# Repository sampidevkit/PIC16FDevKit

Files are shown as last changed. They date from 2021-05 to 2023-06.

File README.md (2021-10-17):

# PIC16F1887X MICROCONTROLLER DEVELOPMENT KIT
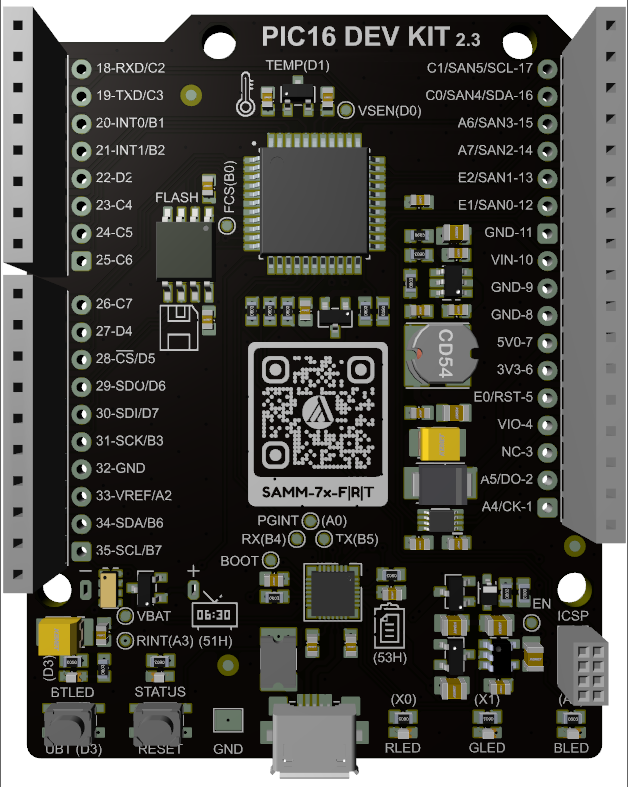
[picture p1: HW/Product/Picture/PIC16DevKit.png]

<br/>Đây là thiết kế mở - một kit phát triển vi điều khiển 8-bit họ PIC16F18875/6/7. Kit được trang bị các tính năng như sau:<br/>
* PCB và các ngõ vào ra theo định dạng của Arduino Uno.
* Mạch nạp tích hợp theo kiểu USB lưu trữ, tệp hex sẽ được kéo - thả để nạp trực tiếp mà không cần sử dụng phần mềm nạp cũng như các mạch nạp bên ngoài như PICKit, ICD, ..., tuy nhiên người dùng vẫn có thể sử dụng được các mạch nạp chuyên dụng kết nối với cổng ICSP được thiết kế sẵn.
* Cổng chuyển đổi USB - UART, người dùng không cần sử dụng thêm thiết bị chuyển đổi bên ngoài như CP2102, FT232, ...
* 4kByte SRAM dùng để mở rộng bộ nhớ tạm cho MCU chính. Chức năng này được thực hiện bởi chip nạp thông qua giao tiếp I2C.
* 2 ngõ ra mở rộng để điều khiển LED được trang bị sẵn trên board. Chức năng này cũng được thực hiện bởi chip nạp thông qua giao tiếp I2C.
* Bộ nhớ Flash 4Mbit, lưu dữ liệu, cấu hình của ứng dụng người dùng. Giao tiếp SPI với MCU chính.
* Cảm biến nhiệt độ dạng tín hiệu tương tự.
* Chip đồng hồ thời gian thực độ chính xác cao. Giao tiếp I2C với MCU chính.<br/>
## 1. Sơ Đồ Khối
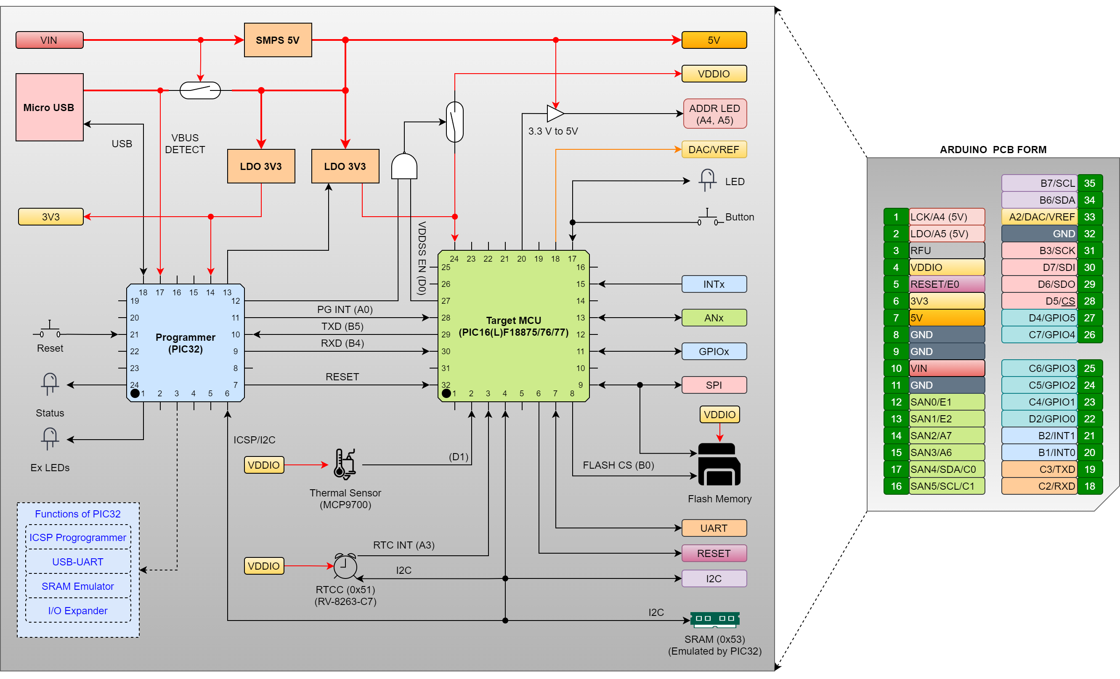
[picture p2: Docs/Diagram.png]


## 2. Sơ Đồ Nguyên Lý
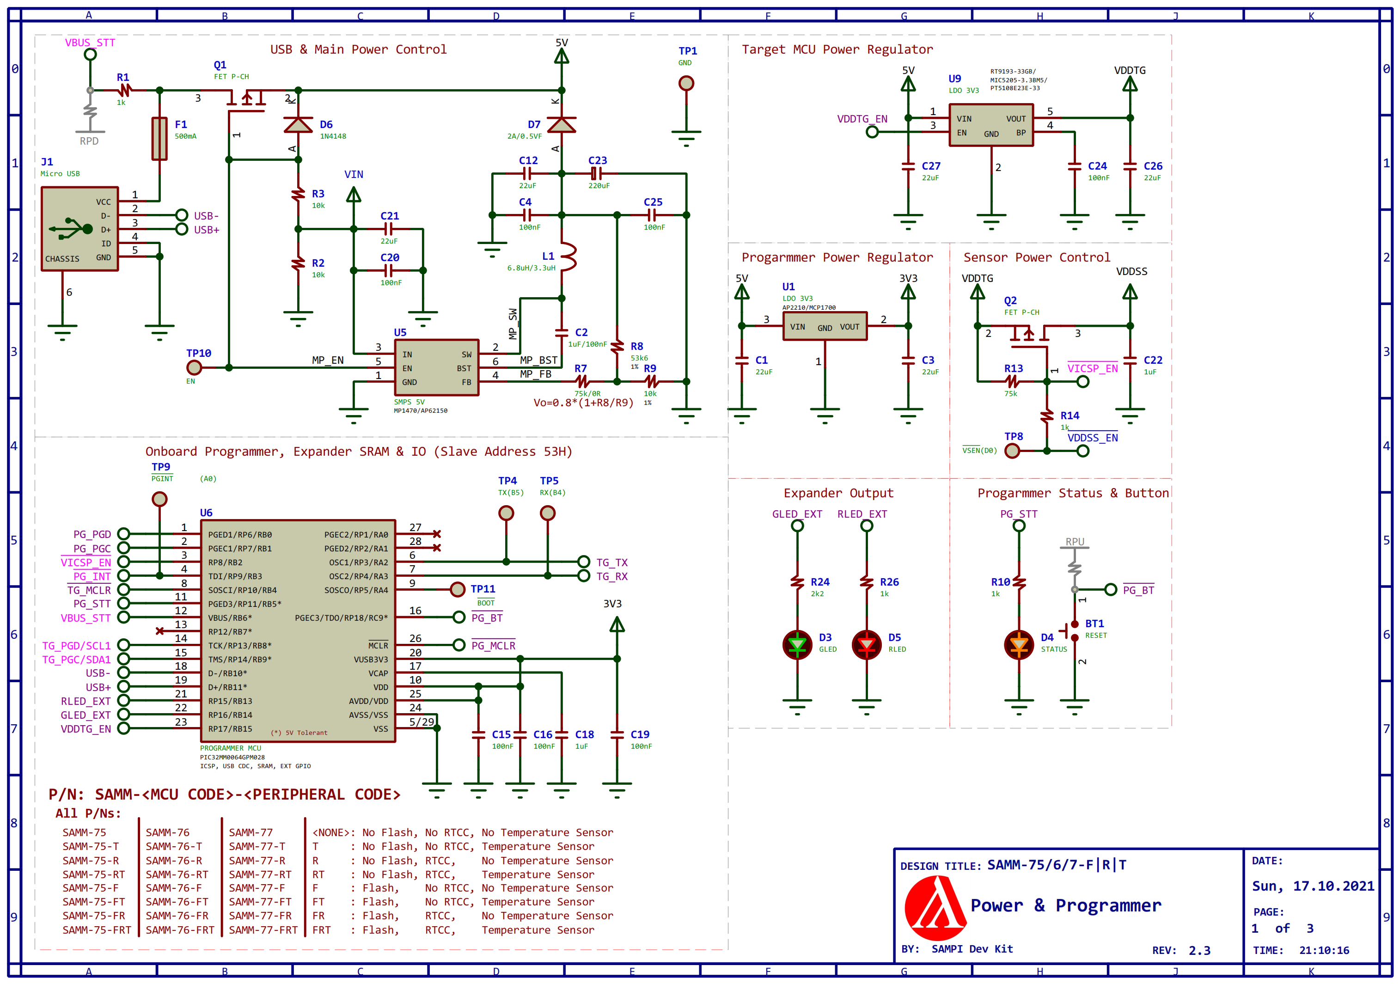
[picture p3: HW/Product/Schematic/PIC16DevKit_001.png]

<br/>
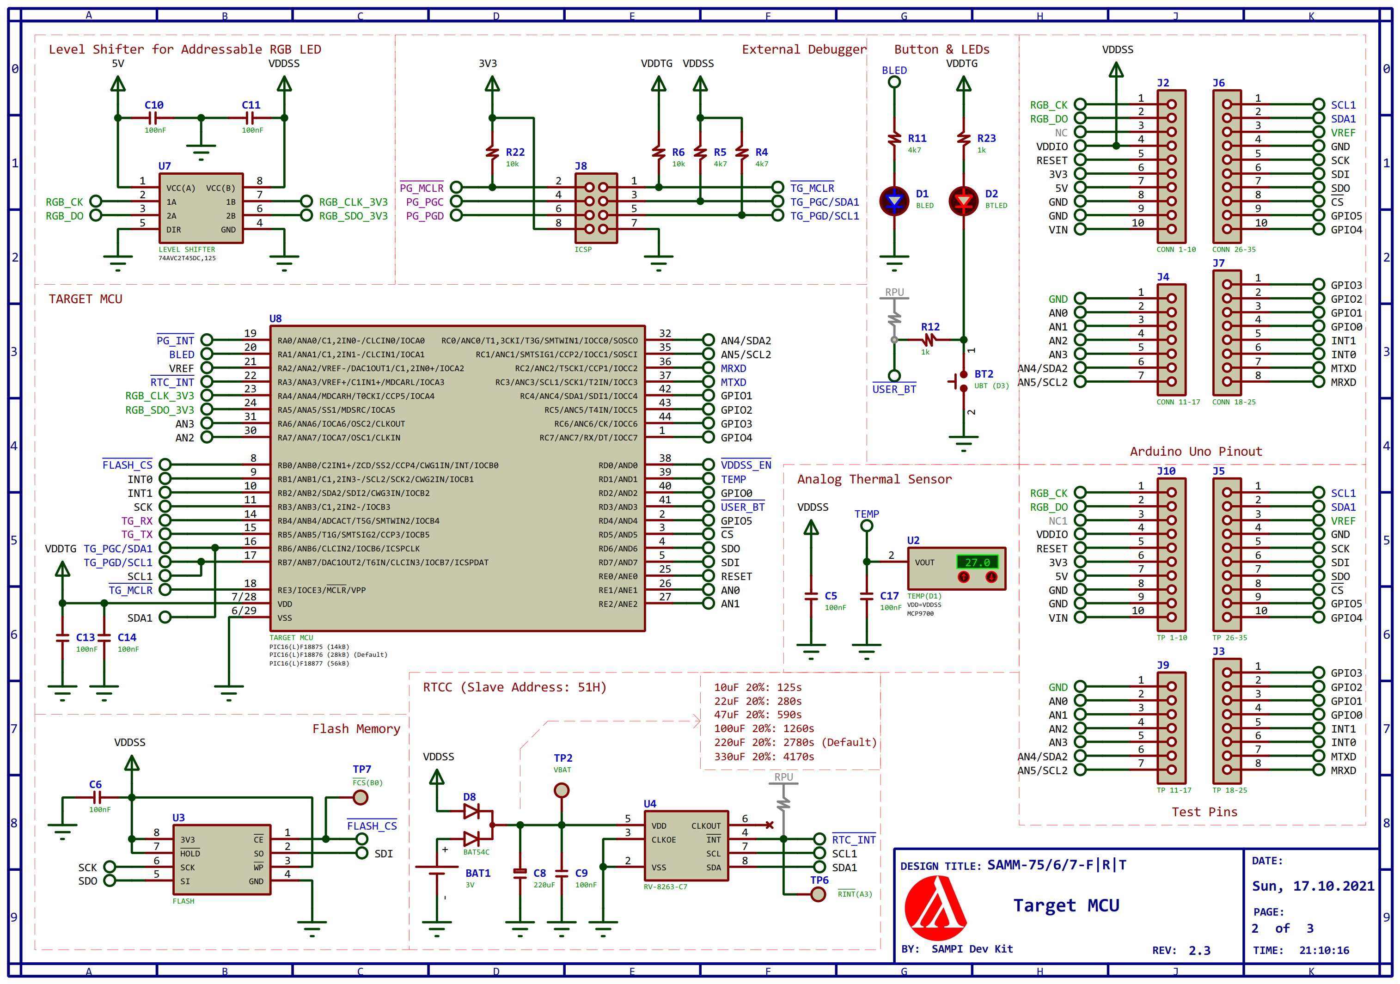
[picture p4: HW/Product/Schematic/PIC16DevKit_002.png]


## 3. Vi Điều Khiển Chính PIC16F1887x
Họ vi điều khiển PIC16F1887x là họ vi điều khiển 8-bit thế hệ mới của PIC16F887/PIC16F877A. Tương thích hoàn toàn về mặt I/O và các chức năng cơ bản. Bên cạnh đó, chip được trang bị các tính năng mới hơn như:<br/>
* Dao động nội lên đến 32MHz và tốc độ đạt 8MIPS so với 5MIPS của chip cũ.
* Bộ nhớ chương trình từ 7kByte đến 56kByte, RAM 512byte-4096byte, EEPROM nội lên đến 256byte.
* Chip được trang bị 1x UART, 2x SPI/I2C, 5x Capture/Compare/PWM (CCP), 2x PWM 10bit, 3x timer 8bit, 4x timer 16bit.
* ADC 10 bit sử dụng được cho tất cả các I/O, 1x DAC 5bit.
* Tính năng mới: 4x cổng logic khả trình (CLC), tính năng bắt điểm 0 của tín hiệu AC (ZCD), CRC, NCO, CWG, DSM, ...
* Ngõ vào ra của các module chức năng có thể cấu hình trên bất kì I/O nào nhờ chức năng Peripheral Pin Select (PPS).
* Năng lượng thấp, phù hợp cho các ứng dụng sử dụng pin.<br/>
* [Thông tin thêm xem tại đây](https://www.microchip.com/wwwproducts/ProductCompare/PIC16F877A/PIC16F18877).

## 4. Môi Trường Lập Trình, Trình Biên Dịch và Công Cụ Hỗ Trợ

### 4.1. Môi Trường Lập Trình MPLAB X IDE

Môi trường lập trình MPLAB X IDE sử dụng mã nguồn của Netbeans, giao diện thân thiện và dễ sử dụng. Tải về và hướng dẫn cài đặt tại đây: [Installing MPLAB® X IDE](https://microchipdeveloper.com/mplabx:installation). </br>
Khuyến cáo: Sử dụng Windows 64bit với RAM tối thiểu 4GB và ổ cứng trống từ 20GB.

### 4.2. Trình Biên Dịch MPLAB XC8
Nếu sử dụng ngôn ngữ lập trình C để lập trình cho Kit, bạn cần tải về trình biên dịch XC8. Nó sẽ chuyển mã C thành mã assembly. </br>

</br>Sau đó, nó sẽ chuyển mã assembly sang mã máy dưới dạng file HEX. Bạn cũng có thể sử dụng XC8 để biên dịch cho mã nguồn được viết trực tiếp bằng assembly. 

</br>Trình biên dịch có thể sử dụng miễn phí, không giới hạn code size, chỉ giới hạn các cấp độ tối ưu mã nguồn. Chức năng tối ưu mã nguồn sử dụng trong sản xuất, không cần thiết trong học tập. Tải về và hướng dẫn cài đặt tại đây: [Installing MPLAB® XC8 Compiler](https://microchipdeveloper.com/xc8:installation).

### 4.3. Công Cụ Cấu Hình và Tạo Code Mẫu MPLAB Code Configurator (MCC)
MCC là một plugin của MPLAB X IDE, hỗ trợ tạo cấu hình chip, cấu hình các ngoại vi và các API để người dùng sử dụng mà không mất nhiều thời gian xây dựng chúng. </br>

</br>Tải về và hướng dẫn cài đặt tại đây: [Install MPLAB® Code Configurator (MCC)](https://microchipdeveloper.com/install:mcc).

## 5. Mạch Nạp Tích Hợp

### 5.1. Nạp Chương Trình Mạch Nạp
Chương trình mạch nạp chỉ cần nạp 1 lần. Các công cụ cần chuẩn bị: </br>
* Mạch nạp chuyên dụng như PICkit3, PICkit4, Snap, ICD3, ICD4, ...
* Header đực 2x4x1.27 dùng cho cổng nạp ICSP theo sơ đồ sau: </br>
Pin2-MCLR, Pin4-PGC, Pin6-PGD, Pin8-VDD (3V3), Pin7-GND </br>
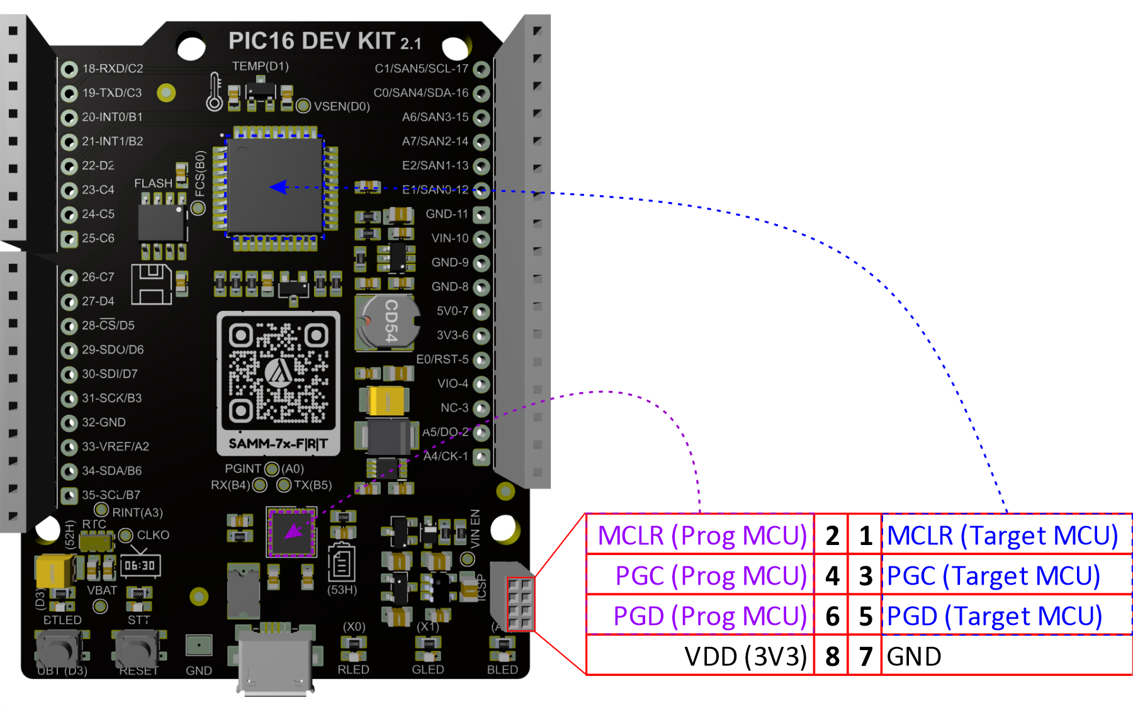
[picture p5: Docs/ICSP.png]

* Cáp micro USB: Kết nối Kit với nguồn USB 5V bất kỳ. Nếu sử dụng nguồn điện 3.3V cấp từ mạch nạp thì không cần sử dụng cáp micro USB.
* File chương trình tải về từ [master/FW/PG.X/Production.hex](https://github.com/sampidevkit/PIC16FDevKit/raw/master/FW/PG.X/Production.hex).
* MCU là PIC32MM0064GPM028.
Khi nạp thành công, kết nối kit với máy tính bằng cáp micro USB bạn sẽ thấy xuất hiện ổ đĩa như sau: </br>
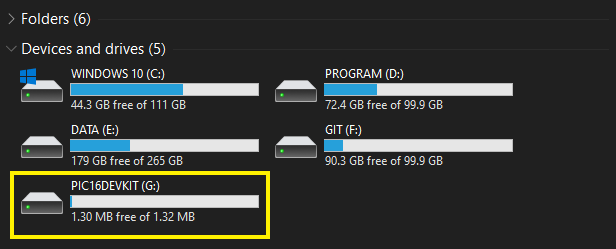
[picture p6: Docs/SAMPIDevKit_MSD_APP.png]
 </br>
Mở ổ đĩa này, bạn sẽ thấy file SAMPIDevKit_INFO.txt chứa nội dung như sau: </br>
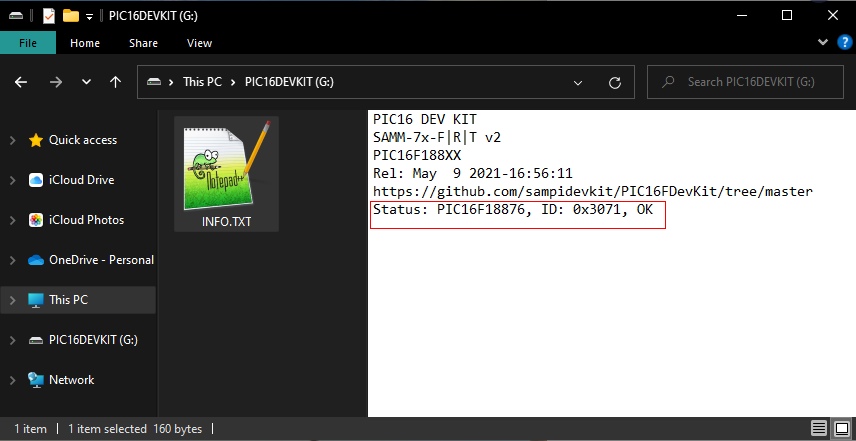
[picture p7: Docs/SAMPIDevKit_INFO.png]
 </br>
Nếu có lỗi xảy ra, xem ở mục 5.3.

### 5.2. Cập Nhật Chương Trình Mạch Nạp
Để cập nhật chương trình mới cho chip nạp, bạn có thể thực hiện như mục 5.1 hoặc thực hiện như sau: </br>
* Kết nối kit với máy tính bằng cáp micro USB.
* Nhấn giữ nút RESET đến khi các đèn STT, RLED, BLED cùng sáng (khoảng 5s).
* Vào My Computer/ This PC sẽ thấy xuất hiện ổ đĩa BOOTLOADER.
* Tải File chương trình về từ [master/FW/PG.X/app.hex](https://raw.githubusercontent.com/sampidevkit/PIC16FDevKit/master/FW/PG.X/app.hex) và lưu vào ổ đĩa BOOTLOADER. </br>
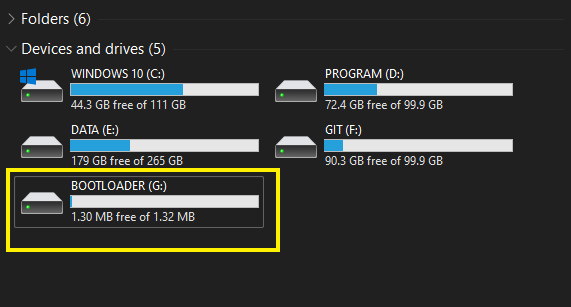
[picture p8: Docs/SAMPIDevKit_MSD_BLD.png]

* Sau khi lưu, kit sẽ tự khởi động lại và hoạt động với chương trình mới. Nếu có lỗi xảy ra, xem ở mục 5.3.

### 5.3 Các Trạng Thái LED Lỗi
* Lỗi khi ghi file hex vào ổ đĩa của kit: File nạp không đúng định dạng hoặc sự cố kết nối USB.
* Chế độ bootloader - nhấn giữ nút RESET trong 3s: RLED, GLED sáng, STT led ON=500ms, OFF=500ms. </br>
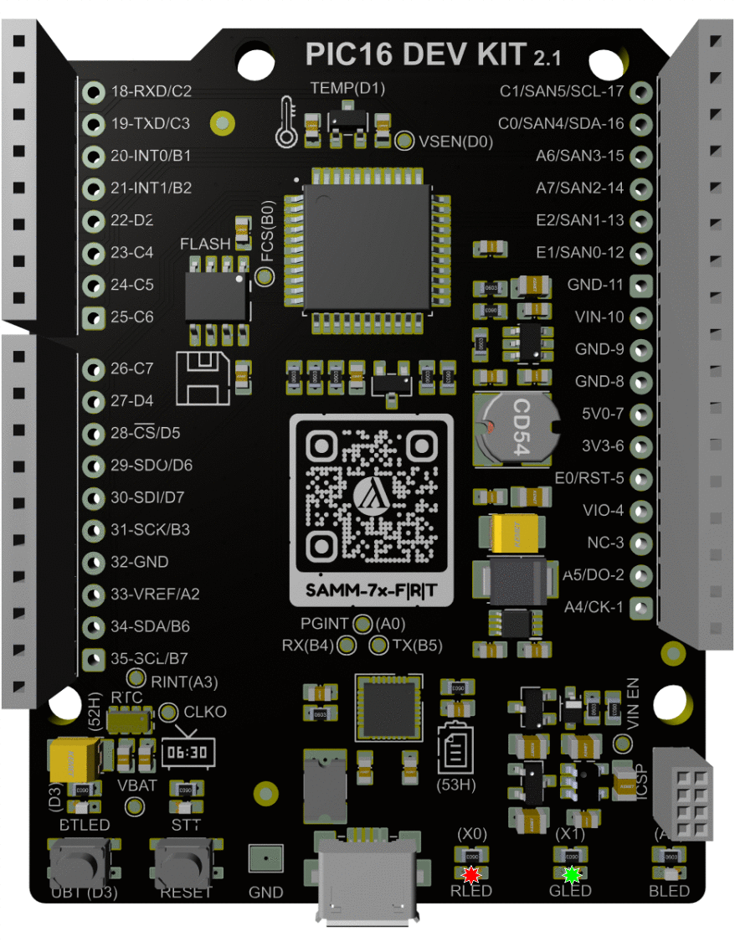
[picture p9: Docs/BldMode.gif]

* Chế độ chờ: Led STT nháy với chu kì ON=10ms, OFF=1990ms. </br>
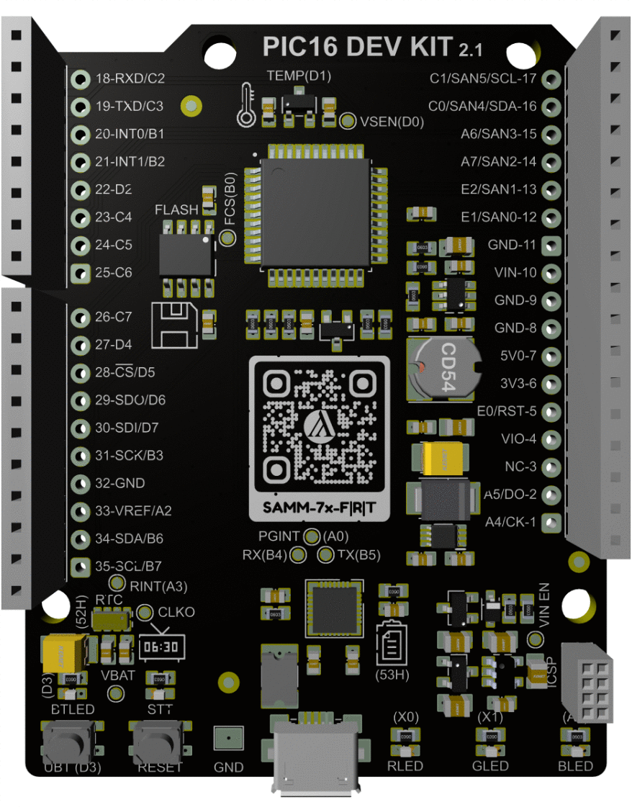
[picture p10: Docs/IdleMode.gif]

* Lỗi không nhận chip: Led STT nháy với chu kì ON=500ms, OFF=1500ms. </br>

* Truyền nhận dữ liệu UART: Led STT nháy 1 lần TON=5ms. </br>

* Reset target chip - khi nhấn giữ nút RESET khoảng 200ms: Led STT, RLED, GLED sáng 500ms. </br>
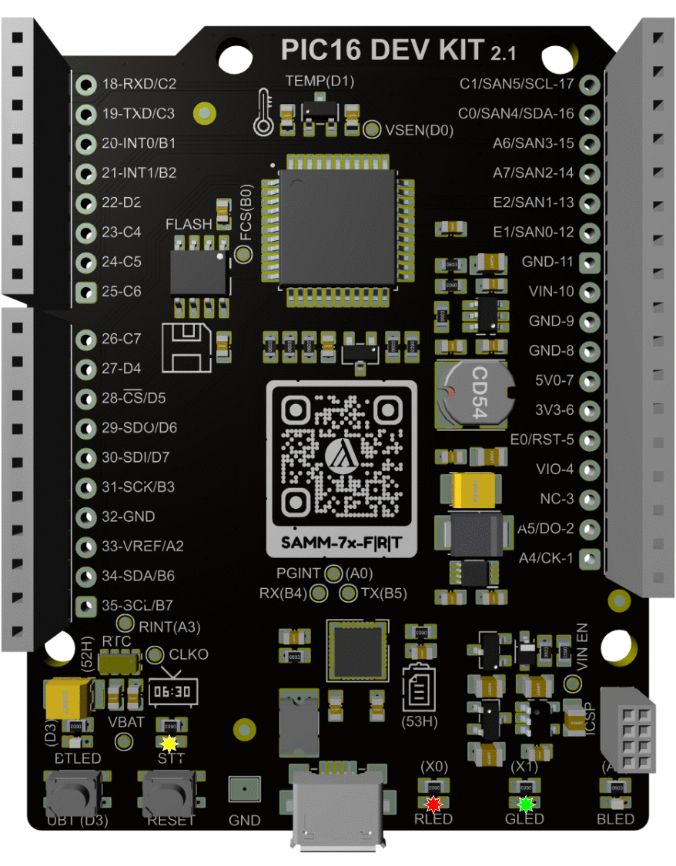
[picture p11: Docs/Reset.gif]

* Erase target chip - khi nhấn nhanh 4 lần nút RESET: Led STT sáng, RLED và GLED nháy 3 lần 250ms sau đó cả 3 cùng sáng trong 500ms. </br>


## 6. Hướng Dẫn Lập Trình Cơ Bản
[Xem tại đây](https://github.com/sampidevkit/PIC16FDevKit/blob/docs/README.md).

## 7. Tài Liệu Kỹ Thuật:
* [Target MCU PIC16LF18877](https://ww1.microchip.com/downloads/en/DeviceDoc/PIC16LF1885777_Data_Sheet_40001825F.pdf).
* [PIC16LF18877 Programming Specification](https://ww1.microchip.com/downloads/en/DeviceDoc/40001753B.pdf).
* [Programmer MCU PIC32MM0064GPM028](https://ww1.microchip.com/downloads/en/DeviceDoc/PIC32MM0256GPM064-Family-Data-Sheet-DS60001387D.pdf).
* [PIC32MM0064GPM028 Programming Specification](https://ww1.microchip.com/downloads/en/DeviceDoc/PIC32MM-Families-Flash-Programming-Specification-DS60001364E.pdf).
* [Flash memory SST25VF020B](https://ww1.microchip.com/downloads/en/DeviceDoc/20005054D.pdf).
* [Temperature sensor MCP9700](https://ww1.microchip.com/downloads/en/DeviceDoc/20001942G.pdf).
* [Real time clock and calendar RV8263-C7](https://www.microcrystal.com/fileadmin/Media/Products/RTC/Datasheet/RV-8263-C7.pdf).
* [Voltage level shifter 74LVC2T45GS-Q100X](https://assets.nexperia.com/documents/data-sheet/74LVC_LVCH2T45_Q100.pdf).
* [LDO 3.3V RT9193](https://www.richtek.com/assets/product_file/RT9193/DS9193-17.pdf).
* [LDO 3.3V MIC5205](https://www.microchip.com/content/dam/mchp/documents/OTH/ProductDocuments/DataSheets/20005785A.pdf).
* [LDO 3.3V PT5108E23E](http://www.sunnyqi.com/upLoad/product/month_1306/PT5108.pdf).
* [LDO 3.3V AP2210](https://www.diodes.com/assets/Datasheets/AP2210.pdf).
* [LDO 3.3V MCP1700](https://ww1.microchip.com/downloads/en/DeviceDoc/MCP1700-Data-Sheet-20001826F.pdf).
* [SMPS 5V MP1470](https://www.monolithicpower.com/en/documentview/productdocument/index/version/2/document_type/Datasheet/lang/en/sku/MP1470/document_id/327/).
* [SMPS 5V AP62150](https://www.diodes.com/assets/Datasheets/AP62150.pdf).
* [Button PTS 815](https://www.ckswitches.com/media/2728/pts815.pdf).
* [Inductor 3.3uH/6.8uH CD53 Series](http://www.coilsjs.com/product/product_images/b/cn_D_1_108.pdf).
* [Switching diode 1N4148W-E3-18](https://www.vishay.com/docs/85748/1n4148w.pdf).
* [Switching diode BAT54C](https://assets.nexperia.com/documents/data-sheet/BAT54_SER.pdf).
* [Schottky Power Rectifier SS24](https://www.onsemi.com/pdf/datasheet/ss24-d.pdf).
* [Resettable fuse 0ZCG0050AF2C](https://www.belfuse.com/resources/datasheets/circuitprotection/ds-cp-0zcg-series.pdf).
* [Micro USB connector 10118192-0002LF](https://www.amphenol-icc.com/media/wysiwyg/files/drawing/10118192.pdf).
* [Mosfet P-CH 2A FDN340P](https://www.onsemi.com/pdf/datasheet/fdn340p-d.pdf).
* [Battery CR1220](https://www.digikey.com/en/products/detail/panasonic-bsg/CR-1220-HFN/965114).
* [Female header 2x4x1.27mm SFMC-104-T1-S-D](http://suddendocs.samtec.com/prints/sfm-thd.pdf).
* [Female header 2x2x2.54mm M20-8760242](https://cdn.harwin.com/pdfs/M20-876.pdf).
* [Female header 1x10/8/7x2.54mm SSW-1XX-01-T-S](http://suddendocs.samtec.com/catalog_english/ssq_th.pdf).
* [Male header 1x10/8/7x2.54mm TSW-1XX-23-L-S](http://suddendocs.samtec.com/catalog_english/tsw_th.pdf).
* [Arduino Uno Dimension](http://arduino.cc/documents/ArduinoUno.dxf).
* [Arduino Uno Pinout](https://content.arduino.cc/assets/Pinout-UNOrev3_latest.png).

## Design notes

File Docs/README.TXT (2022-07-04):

PIC16(L)F1885X/7X microcontrollers feature Analog, Core Independent Peripherals and communication peripherals, combined with eXtreme Low Power (XLP) for a wide range of general purpose and low-power applications. The family features the CRC/SCAN, HLT and Windowed WDT to support customers looking to add safety to their application. Additionally, this family includes up to 56 KB of Flash memory, along with a 10-bit ADC with Computation (ADC2) for automated signal analysis to reduce the complexity of the application.
Enhanced Mid-range Core with 49 Instruction, 16 Stack Levels
Adjustable Internal Oscillator (up to 32MHz)
2x 10-bit PWMs
5x Capture, Compare, PWM (CCP)
Numerically Controlled Oscillator (NCO)
4x Configurable Logic Controller (CLC)
10-bit ADC with Computation (ADC2)
Complementary Waveform Generator (CWG)
5-bit Digital to Analog Converter (DAC)
Data Signal Modulator (DSM)
In Circuit Serial Programming (ICSP)
Zero Cross Detect (ZCD)
Cyclical Redundancy Check (CRC/SCAN)
Windowed Watchdog Timer (WWDT)
Peripheral Pin Select (PPS)
Enhanced Power-On/Off-Reset
Low-Power Brown-Out Reset (LPBOR)
Programmable Brown-Out Reset (BOR)
PIC16LF18877 (1.8V – 3.6V)
PIC16F18877 (2.3V – 5.5V)

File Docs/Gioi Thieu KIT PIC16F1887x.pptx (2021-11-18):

## PIC16F18877 DEVELOPMENT KIT

INTRODUCTION & DEMONSTRATION

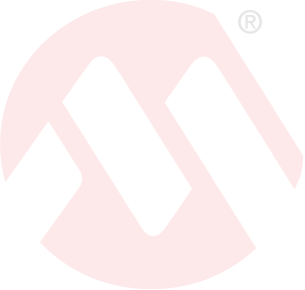
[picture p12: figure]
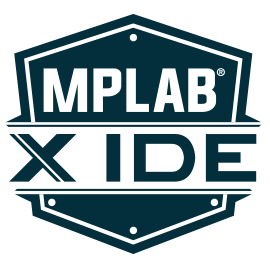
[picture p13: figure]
MPLAB X IDE Logo
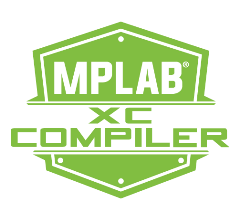
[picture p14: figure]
mplab_xc_compiler_logo_011216_03

## CONTENTS

MICROCHIP COMPANY INTRODUCTION
PIC16F18877 OVERVIEW
TRAINING PROGRAM
DEMONSTRATION

## MICROCHIP COMPANY INTRODUCTION

- Leading in microcontroller
PIC, dsPIC, AVR, MIPS, ARM.
- Acquisitions
- Atmel: MCU, MPU, Touch, RF.
- Micrel: Power supply & management.
- ISSC: Memory.
- Supertex: HV analog and mixed signal.
- EqcoLogic: Data and video transceivers.
- Microsemi: FPGA & SoC (March 1st, 2018).
- Number one in 8-bit MCU

MICROCHIP COMPANY INTRODUCTION

PIC16F1xxxx OVERVIEW

TRAINING PROGRAM

DEMONSTRATION

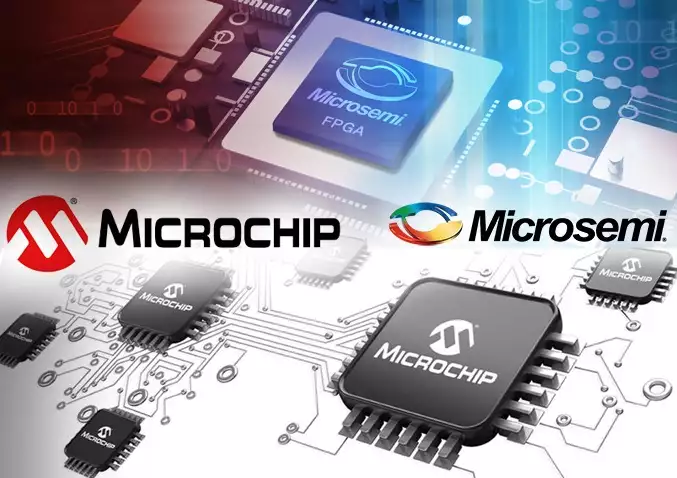
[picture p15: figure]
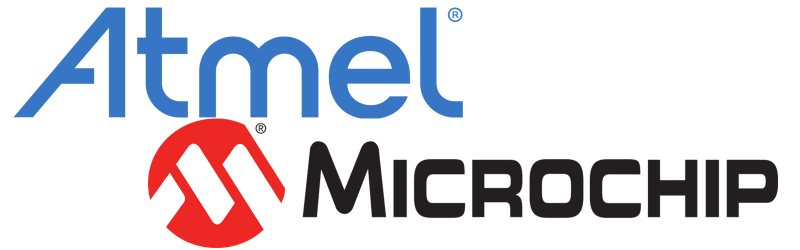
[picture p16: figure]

## PIC16F1xxxx OVERVIEW

- Summary
- PIC16F1xxxx MCU offer eXtreme Low-Power.
- LCD drive, RTCC, 12-bit ADC.
- Core Independent Peripherals.
- Memory access partition.

MICROCHIP COMPANY INTRODUCTION

PIC16F1xxxx OVERVIEW

TRAINING PROGRAM

DEMONSTRATION

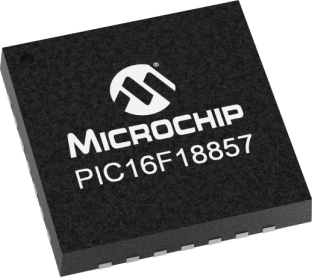
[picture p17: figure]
product primary image

## PIC16F1xxxx OVERVIEW

- Feature

MICROCHIP COMPANY INTRODUCTION

PIC16F1xxxx OVERVIEW

TRAINING PROGRAM

DEMONSTRATION

Parameters | PIC16F18857 | PIC16F886
Flash/RAM/EEPROM | Up to 56KB/4KB/256B | Up to 14KB/368B/256B
Speed | 8MIPS@32MHz (Internal) | 5MIPS&20MHz (External)
ADC/DAC resolution | 12-bit/5-bit | 10-bit/0
Timer 8/16bit | 2/2 | 2/1
CCP/PWM | 2/2 – 10-bit | 2/0 - 10-bit
CWG/CLC | 1/4 | 0/0
Zero cross detect | Yes | No
UART/SPI/I2C | 2/1/1 | 1/1/1
Peripheral pin select | Yes | No

## TRAINING PROGRAM

- What is a microcontroller?
- How to use a microcontroller?
- How to make an application?

MICROCHIP COMPANY INTRODUCTION

PIC16F1xxxx OVERVIEW

TRAINING PROGRAM

DEMONSTRATION

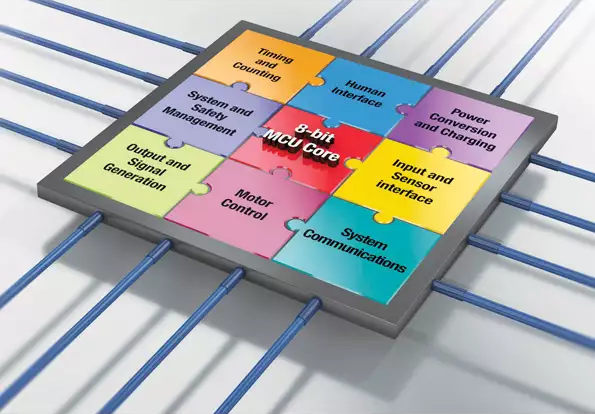
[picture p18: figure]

## TRAINING PROGRAM

- What is a microcontroller?
- MCU Basic Structure/Operation.
- Peripheral Circuitry.
- Programming Language/
Software Development Environment.
- Peripheral Circuitry Control.
- Interrupt Processing.

MICROCHIP COMPANY INTRODUCTION

PIC16F1xxxx OVERVIEW

TRAINING PROGRAM

DEMONSTRATION

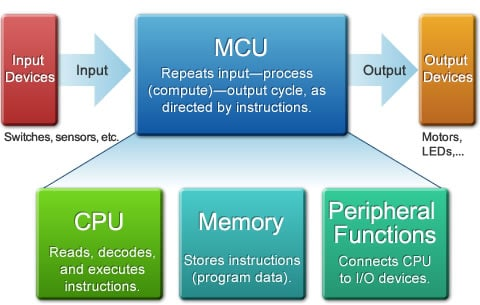
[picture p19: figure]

## TRAINING PROGRAM

- How to use a microcontroller?
- How to configure?
- How to manage memory?
- How to control I.Os & peripherals?
- MPLAB X IDE & XC8 compiler.

MICROCHIP COMPANY INTRODUCTION

PIC16F1xxxx OVERVIEW

TRAINING PROGRAM

DEMONSTRATION

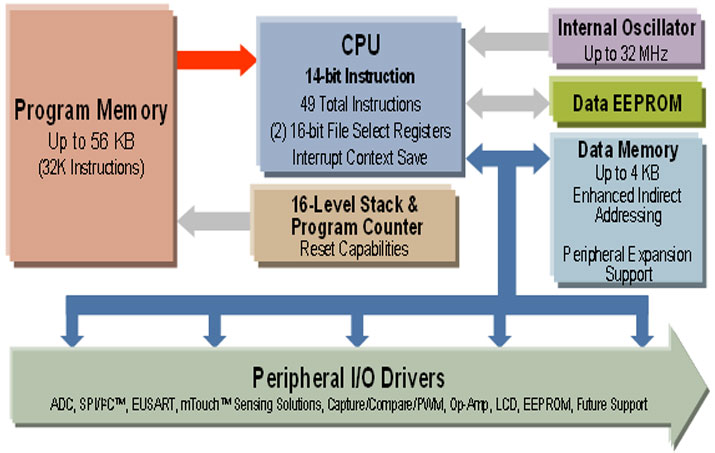
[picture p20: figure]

## TRAINING PROGRAM

MPLAB X IDE & XC8 compiler:
- Run on a PC (Windows®, Mac OS®, Linux®).
- Work on low level: ASM, register (in C).
- Work on high level: API using framework.
- Free license for student.

MICROCHIP COMPANY INTRODUCTION

PIC16F1xxxx OVERVIEW

TRAINING PROGRAM

DEMONSTRATION

## TRAINING PROGRAM

- How to make an application?

MICROCHIP COMPANY INTRODUCTION

PIC16F1xxxx OVERVIEW

TRAINING PROGRAM

DEMONSTRATION

Collect demands
Analyze
Design
Test
Adjust
Release

## TRAINING PROGRAM

- Duration
2 Shifts x 4 Weeks (18 hours).
- Main content
- Configure Chip.
- Memory partition & accessing.
- GPIO control.
- Peripherals: Timer, ADC, PWM, UART, I²C, SPI, Interrupt.
- Applications: Real time control.

MICROCHIP COMPANY INTRODUCTION

PIC16F1xxxx OVERVIEW

TRAINING PROGRAM

DEMONSTRATION

## DEMONSTRATION

- Overview
- Arduino size and pinout.
- Compatible with Arduino shields.
- Feature
- Programmer & Debugger onboard.
- External power supply up to 1.5A.
- More connectivity.

MICROCHIP COMPANY INTRODUCTION

PIC16F1xxxx OVERVIEW

TRAINING PROGRAM

DEMONSTRATION

## DEMONSTRATION

- Electrical
- 5V from micro USB or external power up to 1.5A.
- Logic 5V/3.3V.
- Demo application
MCU will connect to server and send values of sensor included:
  - Temperature & Humidity.
  - Proximity and Ambient.
  - Accelerometer.
  - GPS & RTCC.
Server will send command to control LEDs on MCU board.

MICROCHIP COMPANY INTRODUCTION

PIC16F1xxxx OVERVIEW

TRAINING PROGRAM

DEMONSTRATION

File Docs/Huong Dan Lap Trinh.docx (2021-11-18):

TÀI LIỆU HƯỚNG DẪN LẬP TRÌNH

VI ĐIỀU KHIỂN PIC 8-BIT

HỌ PIC16F18877

Chương 1. TỔNG QUAN VỀ VI ĐIỀU KHIỂN PIC16F18877
  1.1. Các thông số kỹ thuật vi điều khiển PIC16F18877

Vi điều khiển PIC16(L)F1885x/7x với thiết kế analog cải tiến, ngoại vi hoạt động độc lập với CPU (Core Independent Peripherals) và các chuẩn giao tiếp được kết hợp với công nghệ năng lượng siêu thấp (eXtreme Low Power – XLP). Bên cạnh đó, họ PIC16(L)F188xx còn có thêm các tính năng như CRC/SCAN, HLT và Windowed WDT nhằm tăng cường tính an toàn cho ứng dụng. Thêm vào đó, với bộ nhớ flash lên đến 56KB, 4KB RAM cùng với 10-bit ADC với khả năng tính toán tự động sẽ làm giảm sự phức tạp của ứng dụng.

Các tính năng mở rộng:

- Enhanced Mid-range Core with 49 Instruction, 16 Stack Levels.
- Adjustable Internal Oscillator (1-32MHz).
- 2x 10-bit PWMs.
- 5x Capture, Compare, PWM (CCP).
- Complementary Waveform Generator (CWG).
- Numerically Controlled Oscillator (NCO).
- 4x Configurable Logic Controller (CLC).
- 10-bit ADC with Computation (ADC2).
- 5-bit Digital to Analog Converter (DAC).
- Data Signal Modulator (DSM).
- Zero Cross Detect (ZCD).
- Cyclical Redundancy Check (CRC/SCAN).
- Windowed Watchdog Timer (WWDT).
- Peripheral Pin Select (PPS).
- Enhanced Power-On/Off-Reset.
- Low-Power Brown-Out Reset (LPBOR).
- Programmable Brown-Out Reset (BOR).
- In Circuit Serial Programming (ICSP).
- PIC16LF18877 (1.8V – 3.6V).
- PIC16F18877 (2.3V – 5.5V).

Các thông số:

Name | Value
Program Memory Type | Flash
Program Memory Size (KB) | 56
CPU Speed (MIPS/DMIPS) | 8
SRAM Bytes | 4096
Data EEPROM/HEF (bytes) | 256
Digital Communication Peripherals | 1-UART, 2-SPI, 2-I2C
Capture/Compare/PWM Peripherals | 5CCP+2PWM only
Timers | 3 x 8-bit, 4 x 16-bit
ADC input | 24 channel, 10-bit
Number of Comparators | 2
Temperature Range (C) | -40 to 125
Operating Voltage Range (V) | 1.8 to 3.6 (LF) 2.3 to 5.5 (F)
Pin count | 28
I/O | 25

  1.2. Các thông số kỹ thuật kit phát triển

Kit được thiết kế với kích thước và bố trí GPIO theo chuẩn Arduino Uno với các đặc trưng:

- Programmer onboard. Không giống các kit phát triển PIC khác – sử dụng mạch nạp ngoài, hoặc trang bị PICKit 2,3 onboard với chi phí cao; hay sử dụng bootloader để nạp chương trình với nhiều hạn chế trong việc tương tác với MCU. Kit được thiết kế chip nạp riêng để không hạn chế trong việc tương tác chip.
- Bộ chuyển đổi USB-UART. Bên cạnh programmer onboard, Kit còn tích hợp chức năng chuyển đổi USB-UART mà không cần bộ chuyển đổi bên ngoài.
- Bố trí IO tương thích với các shield Arduino có sẵn trên thị trường.

Name | Value
Speed | Internal 32MHz@8MIPS
Flash/RAM/EEPROM (KB) | 56/4/0.25
UART/SPI/I2C | 1/2/2
Debug | Hardware or, and Software UART
UART supported baud | 9600-115200
Ananlog
CCP/PWM | 5/2x10-bit

  1.3. Cấu trúc bộ nhớ
  1.4. Cấu hình chip
Chương 2. GIỚI THIỆU MPLAB X IDE, XC COMPILER VÀ CÔNG CỤ TẠO CODE
2.1. MPLAB X IDE

MPLAB X IDE là môi trường biên soạn được xây dựng dựa trên nền tảng Eclipse, cho phép tải miễn phí từ http://www.microchip.com/mplab/mplab-x-ide.

Trong trường hợp máy tính cấu hình yếu hoặc hệ điều hành không hỗ trợ, có thể sử dụng MPLAB X online tại địa chỉ https://mplabxpress.microchip.com/mplabcloud/ide.

2.2. XC Compiler
2.3. Microchip Code Configurator (MCC)
2.4. Programmer và Debugger
Chương 3. LẬP TRÌNH CÁC MODULE CƠ BẢN
BÀI 1. Chip configuration
BÀI 2. Digital input/output
BÀI 3. Analog input/output
BÀI 4. Interrupts
BÀI 5. Interrupt on change, External interrupt
BÀI 6. Timer/Counter
BÀI 7. Capture/Compare/PWM-EPWM
BÀI 8. EUSART
BÀI 9. MSSP
Chương 4. LẬP TRÌNH CÁC MODULE NÂNG CAO
BÀI 10. CRC
BÀI 11. CLC
BÀI 12. NCO
BÀI 13. CWG
BÀI 14. DSM
BÀI 15. ZCD
BÀI 16. SMT
Chương 5. LẬP TRÌNH TRUY XUẤT BỘ NHỚ VÀ BOOT LOADER
BÀI 17. EEPROM
BÀI 18. NVM
BÀI 19. BOOTLOADER
Chương 6. LẬP TRÌNH ỨNG DỤNG CƠ BẢN
BÀI 20. QUÉT LED 7 ĐOẠN
BÀI 21. QUÉT LED MA TRẬN
BÀI 22. TEXT LCD
BÀI 23. GRAPHIC LCD
BÀI 24. ĐIỀU KHIỂN TỐC ĐỘ ĐỘNG CƠ DC
BÀI 25. STEPPER MOTOR
BÀI 26. ĐIỀU KHIỂN TỐC ĐỘ ĐỘNG CƠ 1 PHASE AC
BÀI 27. CẢM BIẾN NHIỆT ĐỘ
BÀI 28. CẢM BIẾN QUANG VÀ TIỆM CẬN
BÀI 29. CẢM BIẾN ÁP SUẤT
BÀI 30. CẢM BIẾN GIA TỐC
BÀI 31. CON QUAY HỒI CHUYỂN
Chương 7. LẬP TRÌNH ỨNG DỤNG NÂNG CAO
BÀI 32. ĐỊNH VỊ TOÀN CẦU GPS
BÀI 33. GSM/3G/4G
BÀI 34. BLUETOOTH
BÀI 35. WIFI
BÀI 36. SUB-GHZ
BÀI 37. LORA
BÀI 38. THU THẬP DỮ LIỆU VÀ ĐIỀU KHIỂN TỪ XA
BÀI 39. HỆ THỐNG DEVICE FIRMWARE UPDATE (DFU)

TÀI LIỆU THAM KHẢO

[1]  PIC16F18877/77 - DS40001825C - 2016-2018 Microchip Technology Inc (https://www.microchip.com/wwwproducts/en/PIC16F18857).

SAMPI Dev Kit Trang 2

TÀI LIỆU HƯỚNG DẪN LẬP TRÌNH PIC 8-BIT HỌ PIC16F18877

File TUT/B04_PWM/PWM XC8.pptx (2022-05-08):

## PIC16F DEVELOPMENT KIT

PIC16F18877 – PWM
(XC8 COMPILER)

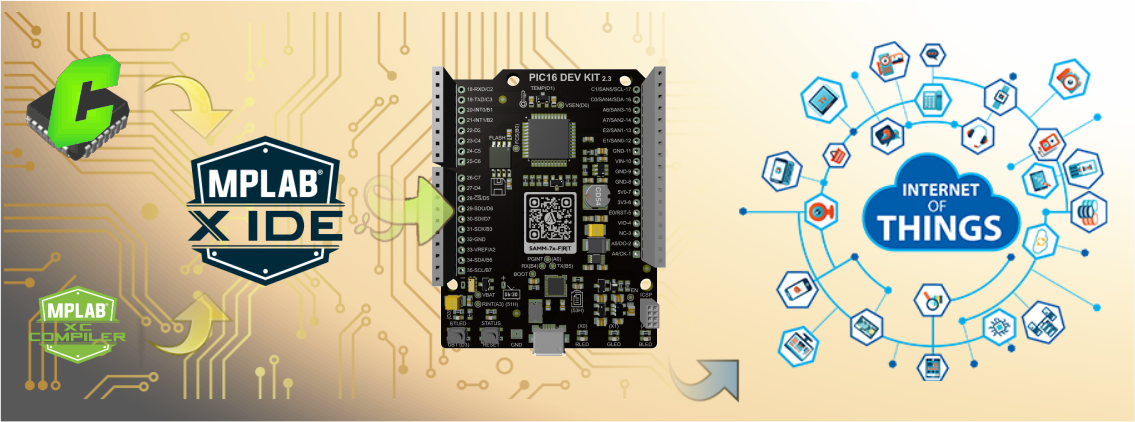
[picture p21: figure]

## NỘI DUNG

ĐIỀU RỘNG XUNG TRÊN MODULE CCP
ĐIỀU RỘNG XUNG TRÊN MODULE PWM

## CCP MODULE 1. TỔNG QUAN

ĐIỀU RỘNG XUNG TRÊN MODULE CCP

ĐIỀU RỘNG XUNG TRÊN MODULE PWM

## CCP MODULE 2. CẤU HÌNH

ĐIỀU RỘNG XUNG TRÊN MODULE CCP

ĐIỀU RỘNG XUNG TRÊN MODULE PWM

## PWM MODULE 1. TỔNG QUAN

ĐIỀU RỘNG XUNG TRÊN MODULE CCP

ĐIỀU RỘNG XUNG TRÊN MODULE PWM

## PWM MODULE 2. CẤU HÌNH

ĐIỀU RỘNG XUNG TRÊN MODULE CCP

ĐIỀU RỘNG XUNG TRÊN MODULE PWM

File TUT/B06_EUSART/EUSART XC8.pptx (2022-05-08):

## PIC16F DEVELOPMENT KIT

PIC16F18877 – EUSART
(XC8 COMPILER)


## NỘI DUNG

SOFT EUSART
EUSART

## SOFT UART

SOFT UART

EUSART

## EUSART

SOFT UART

EUSART

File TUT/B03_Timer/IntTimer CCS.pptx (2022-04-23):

## PIC16F DEVELOPMENT KIT

PIC16F18877 – INTERRUPT & TIMER
(CCS COMPILER)


## NỘI DUNG

INTERRUPT
TIMER

## INTERRUPT 1. TỔNG QUAN

- Ngắt thực thi một chương trình ưu tiên hơn chương trình chính (main function).
- Ngắt xử lý một sự kiện không xác định thời điểm xảy ra.
- Ngắt xử lý sự kiện theo chu kỳ.

INTERRUPT

TIMER

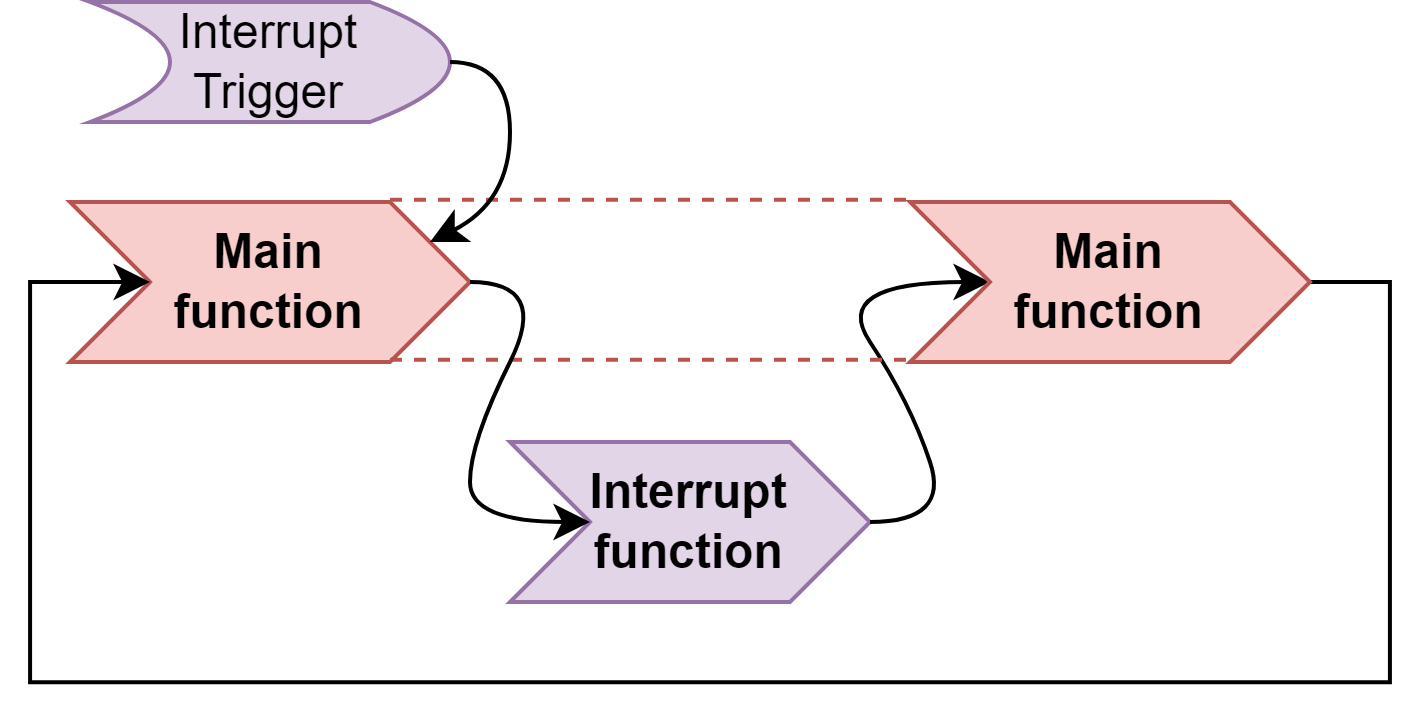
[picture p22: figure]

## INTERRUPT 2. CÁC NGUỒN NGẮT

- PIC16F18877 có 1 vector ngắt.
- Có 2 nhóm ngắt:
- Ngắt ngoại vi (peripheral interrupts), điều khiển bởi bit PEIE.
- Ngắt ngoài ngoại vi,
Điều khiển bởi bit GIE.
Bit này cũng đồng thời
điều khiển tất cả các
nguồn ngắt khác.

INTERRUPT

TIMER

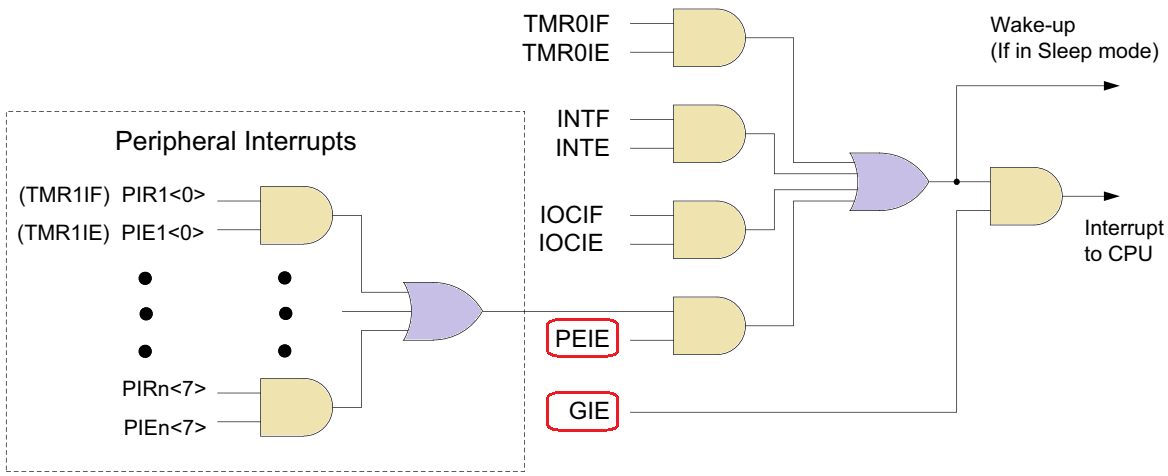
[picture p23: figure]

## INTERRUPT 3. NGẮT TRONG CCS

- Bật ngắt enable_interrupts(tên nguồn ngắt).
- Tắt ngắt disable_interrupts(tên nguồn ngắt).
- Xoá cờ ngắt clear_interrupt(tên nguồn ngắt).
- Cấu trúc khối điều khiển ngắt:

INTERRUPT

TIMER

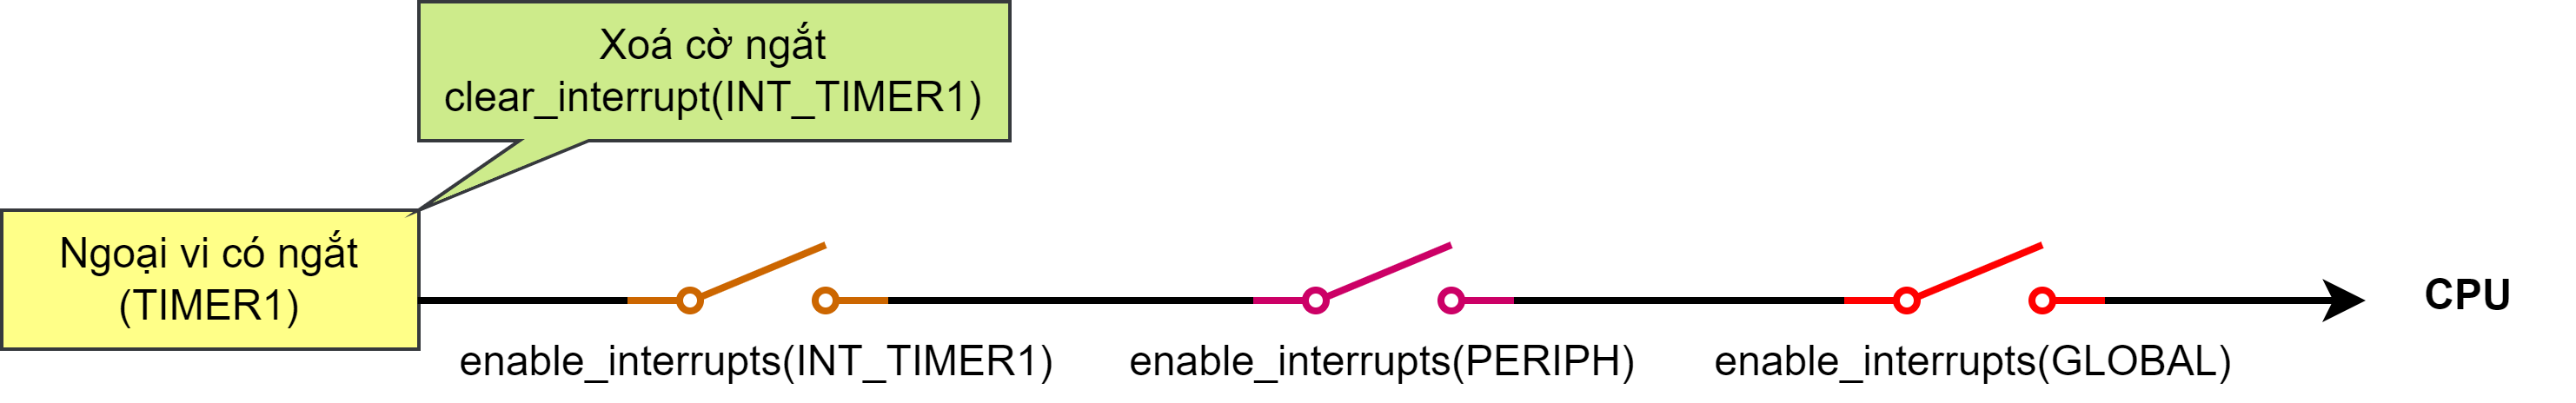
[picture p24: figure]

## INTERRUPT 3. NGẮT TRONG CCS

- Các nguồn ngắt thông dụng:

INTERRUPT

TIMER

GLOBAL | Ngắt toàn cục | INT_OSC_FAIL | Ngắt lỗi dao động
PERIPH | Ngắt ngoại vi | INT_CLCx | Ngắt cổng logic
INT_IOC_x | Ngắt thay đổi trạng thái IO | INT_CCPx | Ngắt CCP
INT_EXT | Ngắt ngoài | INT_TIMERx | Ngắt timer
INT_AD | Ngắt chuyển đổi ADC | INT_RDA | Ngắt UART
INT_SSPx | Ngắt SPI/I2C | INT_ZCD | Ngắt điểm 0

## INTERRUPT 4. CHƯƠNG TRÌNH NGẮT

- Chương trình ngắt đặt bất kỳ vị trí nào trong file source.
- Cấu trúc:
#<TÊN NGUỒN NGẮT>

void FuncName(void)
{
clear_interrupt(Tên nguồn ngắt);
// Chương trình người dùng
}

INTERRUPT

TIMER

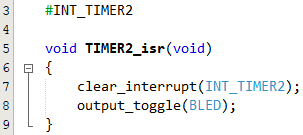
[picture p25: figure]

## INTERRUPT 4. CHƯƠNG TRÌNH NGẮT

- Cấu hình ngắt:
- Cấu hình module ngoại vi.
- Xoá cờ ngắt module ngoại vi.
- Cho phép ngắt module ngoại vi.
- Cho phép ngắt ngoại vi.
- Cho phép ngắt toàn cục.

INTERRUPT

TIMER

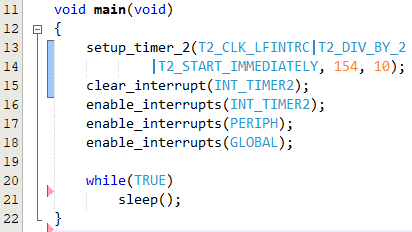
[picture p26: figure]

## TIMER 1. TỔNG QUAN

- Timer/counter thực tế là một bộ đếm với giá trị đếm tăng 1 đơn vị tương ứng với mỗi xung clock cấp vào.
- Timer/counter bản chất là 1 module, chúng chỉ khác nhau về nguồn clock.
  - Timer: Xung clock xác định
được tần số, sử dụng để
đếm thời gian.
  - Counter: Xung clock không
xác định tần số, sử dụng để đếm sự kiện.

INTERRUPT

TIMER

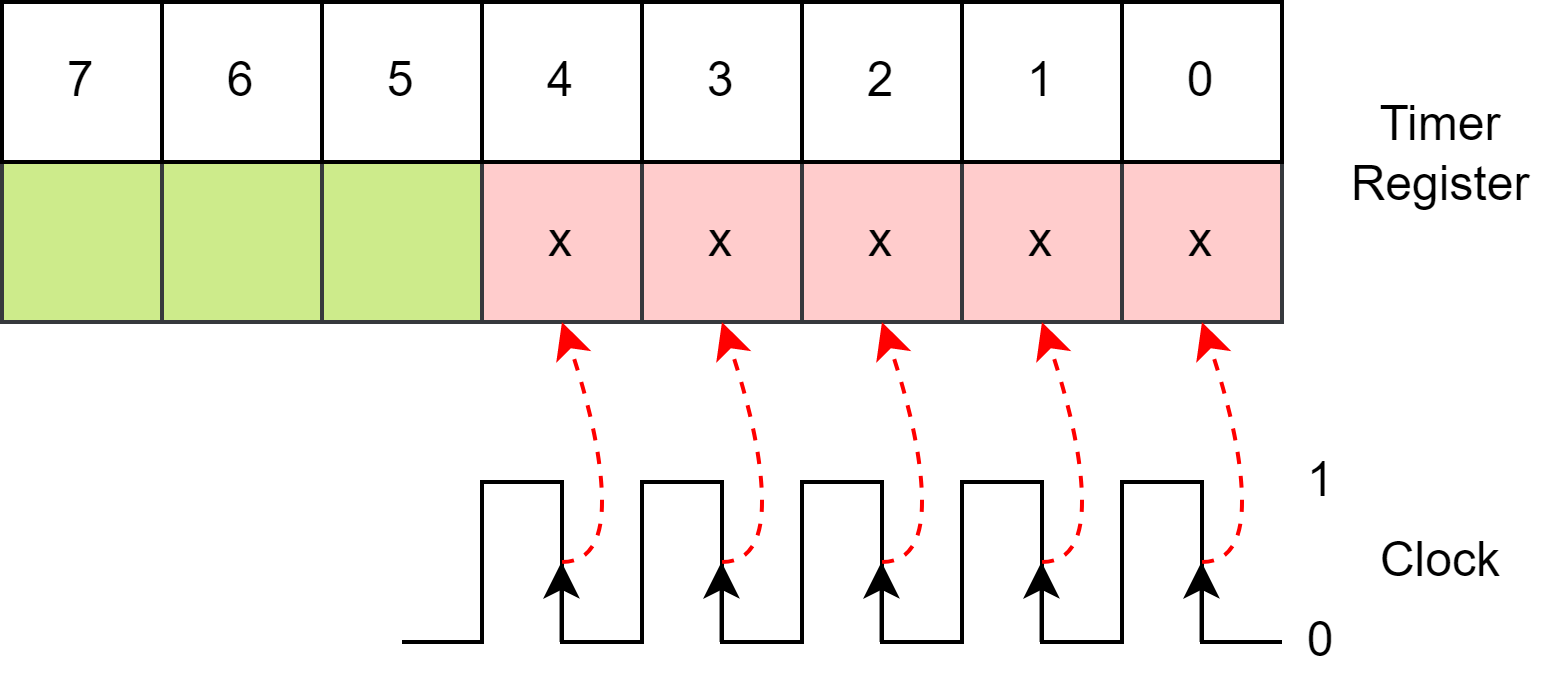
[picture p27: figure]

## TIMER 1. TỔNG QUAN

- PIC16F18877 có 7 timer:
  - Timer 0: 8-bit hoặc 16-bit.
  - Timer 1/3/5: 16-bit.
  - Timer 2/4/6: 8-bit.
- Hai chế độ hoạt động:
  - Tràn (Overflow).
  - So sánh (Compare).

INTERRUPT

TIMER

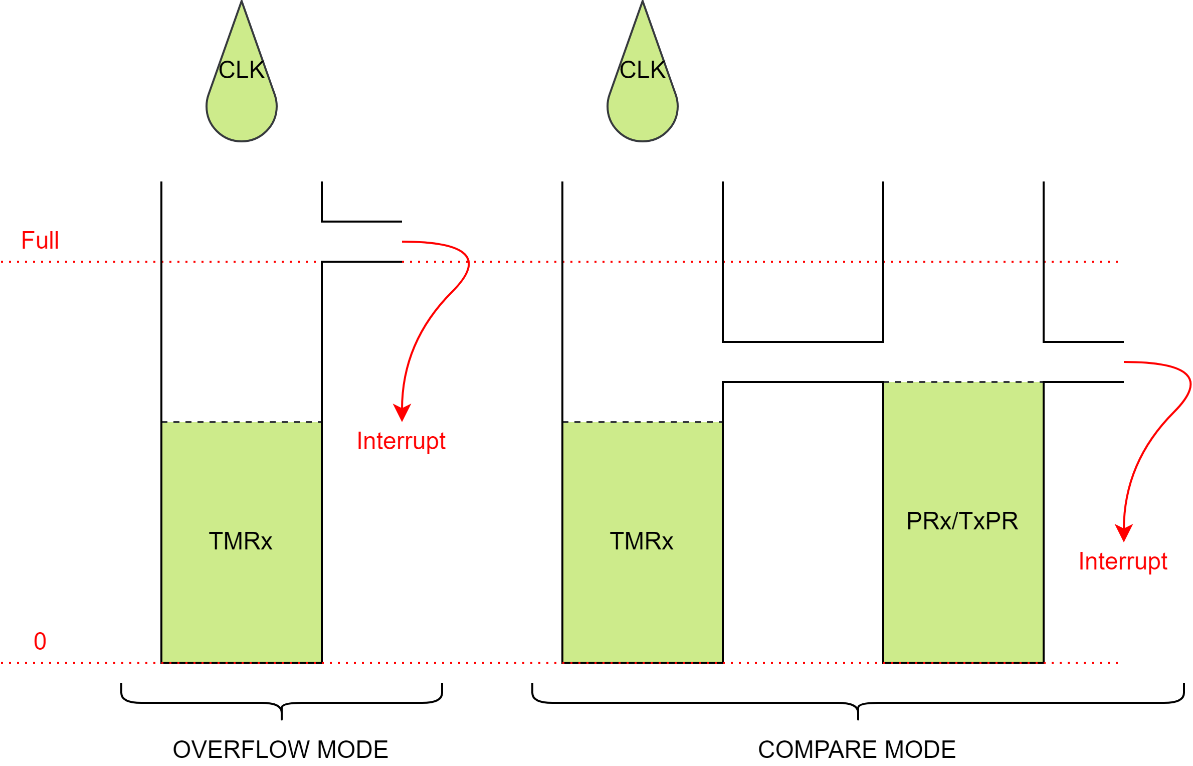
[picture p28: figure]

## TIMER 2. CHẾ ĐỘ TRÀN

- Áp dụng cho timer 16-bit (TMR0/1/3/5).
- Hoạt động:
  - Ứng với mỗi xung cạnh lên,
bộ đếm sẽ tăng 1 giá trị,
khi đạt giá trị tối đa sẽ sinh ngắt
và reset timer về 0.
  - Giá trị bắt đầu là tuỳ chọn.

INTERRUPT

TIMER

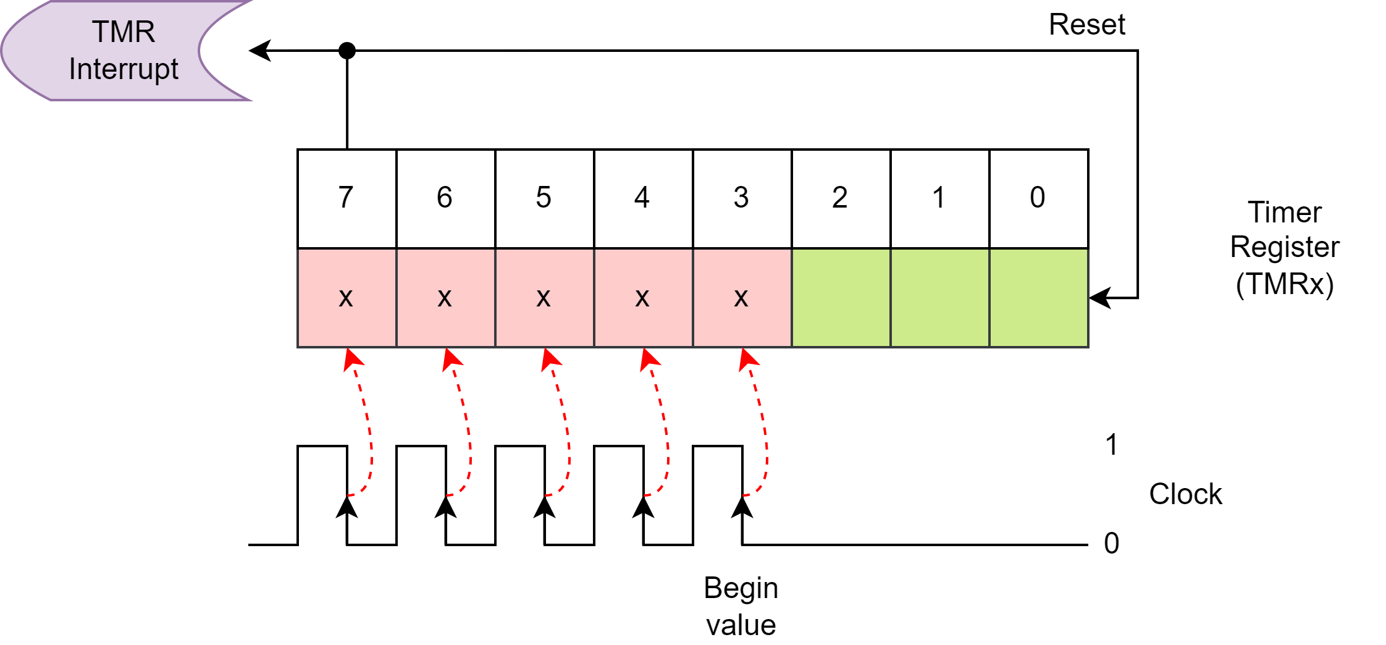
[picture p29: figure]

## TIMER 2. CHẾ ĐỘ TRÀN

- Tính toán:
Tần số xung cấp vào timer: Ftmr=(Fin)/(Pre)
Khoảng định thời: từ 1000/(Ftmr) đến 1000/(Ftmr)×65536 (ms)
Tần suất tràn: Fov=(Ftmr)/(65536−TMR)=(Fin)/(Pre×(65536−TMR))
Tần suất ngắt (TMR=0, Pos>1): Fint=(Fov)/(Pos)=(Fin)/(Pre×Pos×65536)
Tần suất ngắt (Pos=1): Fint=Fov=(Fin)/(Pre×(65536−TMR))⇒TMR=65536−(Fin)/(Fint×Pre)

INTERRUPT

TIMER

## TIMER 2. CHẾ ĐỘ TRÀN

- Ví dụ:
Tần số xung cấp vào timer: Ftmr=(Fin)/(Pre)=31000/8=3875Hz
Khoảng định thời: từ 1000/3875=0.258ms đến 1000/3875×65536=16912.516ms
Giả sử ta muốn ngắt sau mỗi 500ms (Pos=1 ⇒ Fov=Fint=2Hz):
Giá trị TMR theo Fint: TMR=65536−31000/(2×8)=63599.
MCU 8-bit nên thanh ghi 16-bit sẽ tách thành 2 thanh ghi 8bit:
8-bit thấp: TMRL=TMR%256= 111
8-bit cao: TMRH=(TMR)/256=248

INTERRUPT

TIMER

## TIMER 2. CHẾ ĐỘ TRÀN

- Cấu hình TMR trên CCS:
- Cấu hình Fin, Pre, Pos, ...
- Cấu hình giá trị timer.
- Cấu hình interrupt.

INTERRUPT

TIMER

## TIMER 2. CHẾ ĐỘ TRÀN

- Ngắt TMR trên CCS:
- Xoá cờ ngắt.
- Đặt lại giá trị bắt đầu của TMR (nếu có).
- Thực hiện chương trình người dùng.’
→ Lưu ý: Tránh sử dụng biến hoặc function trùng với chương trình chính để tránh sự xung đột.

INTERRUPT

TIMER

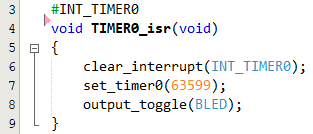
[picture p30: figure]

## TIMER 3. CHẾ ĐỘ SO SÁNH

- Áp dụng cho timer 8-bit
(TMR0/2/4/6).
- Hoạt động:
  - Ứng với mỗi xung (cạnh tuỳ chọn),
bộ đếm sẽ tăng 1 giá trị,
khi đạt giá trị của thanh ghi so sánh
sẽ sinh ngắt và reset timer về 0.
  - Giá trị TMR bắt đầu là 0.
  - Giá trị thanh ghi so sánh là tuỳ chọn.

INTERRUPT

TIMER

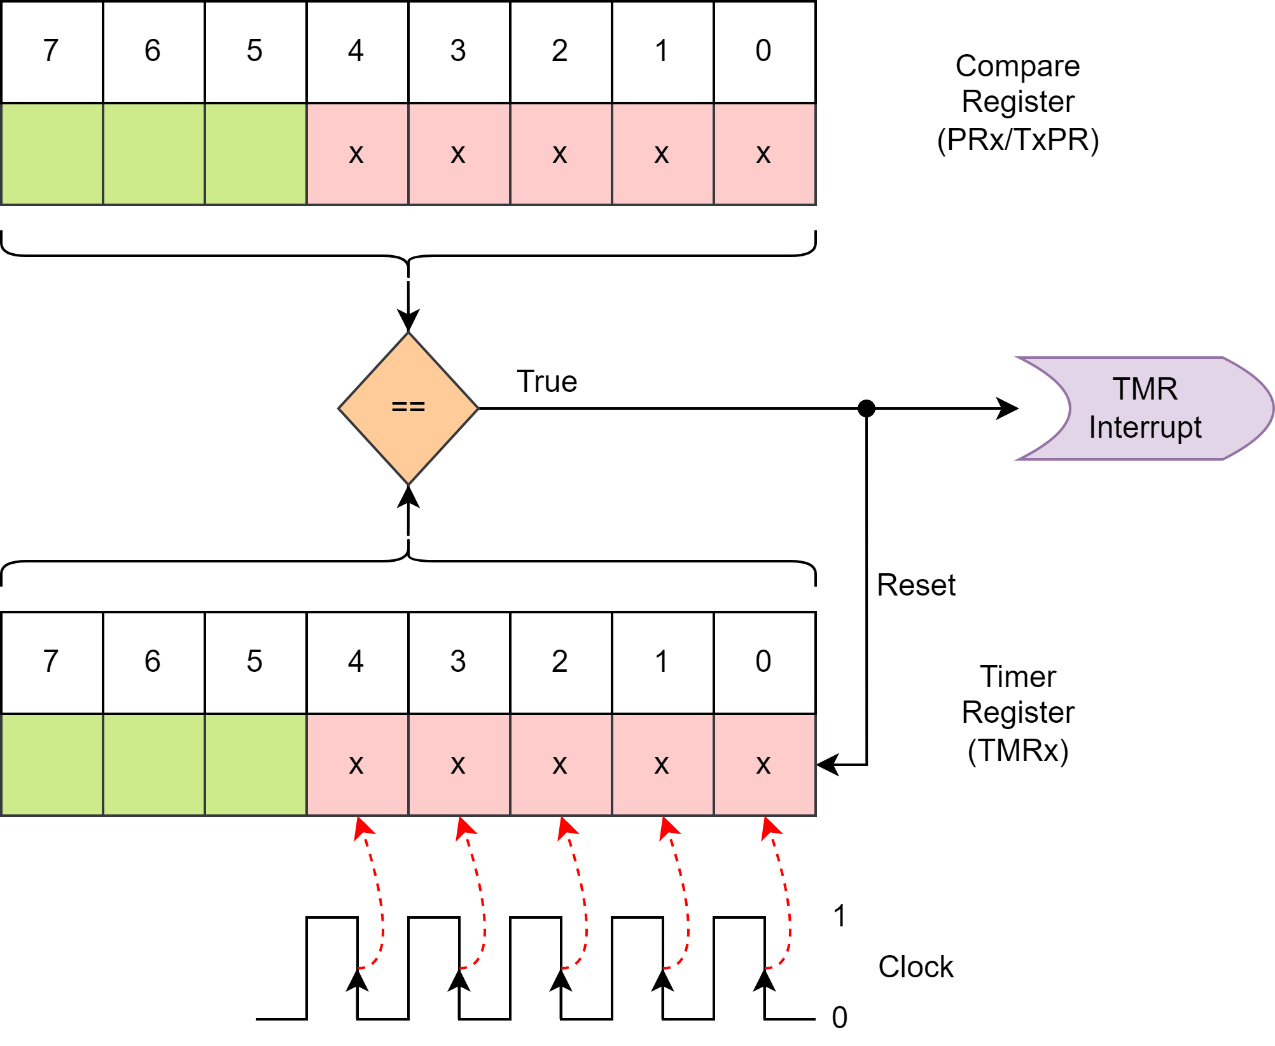
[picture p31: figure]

## TIMER 3. CHẾ ĐỘ SO SÁNH

- Tính toán:
Tần số xung cấp vào timer: Ftmr=(Fin)/(Pre)
Khoảng định thời: từ 1000/(Ftmr) đến 1000/(Ftmr)×256 (ms)
Tần suất tràn: Fov=(Ftmr)/(TMR+1)=(Fin)/(Pre×(TxPR+1))⇒TxPR=(Fin)/(Fov×Pre)−1
Tần suất ngắt: Fint=(Fov)/(Pos)=(Fin)/(Pre×Pos×(TxPR+1))⇒TxPR=(Fin)/(Fint×Pre×Pos)−1

INTERRUPT

TIMER

## TIMER 3. CHẾ ĐỘ SO SÁNH

- Ví dụ:
Tần số xung cấp vào timer: Ftmr=(Fin)/(Pre)=31000/2=15500Hz
Khoảng định thời: từ 1000/15500≈0.065ms đến 1000/15500×256≈16.516ms
Giả sử ta muốn ngắt sau mỗi 100ms (>16.516ms), ta có Fint=10Hz , chọn Pos=10
⇒Fov=Fint×Pos=10×10=100Hz
Giá trị TxPR theo Fov: TxPR=31000/(100×2)−1=154.

INTERRUPT

TIMER

## TIMER 3. CHẾ ĐỘ SO SÁNH

- Cấu hình TMR trên CCS:
- Cấu hình Fin, Pre, Pos, ...
- Cấu hình giá trị timer.
- Khởi động timer.
- Cấu hình interrupt.

INTERRUPT

TIMER

## TIMER 3. CHẾ ĐỘ SO SÁNH

- Ngắt TMR trên CCS:
- Xoá cờ ngắt.
- Đặt lại giá trị bắt đầu của TMR (nếu có).
- Thực hiện chương trình người dùng.
→ Lưu ý: Tránh sử dụng biến hoặc function trùng với chương trình chính để tránh sự xung đột.

INTERRUPT

TIMER

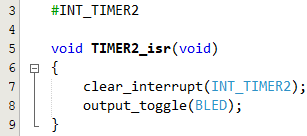
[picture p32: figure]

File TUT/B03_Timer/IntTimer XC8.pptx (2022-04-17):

## PIC16F DEVELOPMENT KIT

PIC16F18877 – INTERRUPT & TIMER
(XC8 COMPILER)


## NỘI DUNG

INTERRUPT
TIMER

## INTERRUPT 1. TỔNG QUAN

- Ngắt thực thi một chương trình ưu tiên hơn chương trình chính (main function).
- Ngắt xử lý một sự kiện không xác định thời điểm xảy ra.
- Ngắt xử lý sự kiện theo chu kỳ.

INTERRUPT

TIMER


## INTERRUPT 2. CÁC NGUỒN NGẮT

- PIC16F18877 có 1 vector ngắt tại địa chỉ 0x0004.
- Có 2 nhóm ngắt:
- Ngắt ngoại vi (peripheral interrupts), điều khiển bởi bit PEIE.
- Ngắt ngoài ngoại vi,
Điều khiển bởi bit GIE.
Bit này cũng đồng thời
điều khiển tất cả các
nguồn ngắt khác.

INTERRUPT

TIMER


## INTERRUPT 3. THANH GHI NGẮT

- Thanh ghi điều khiển ngắt toàn cục INTCON.
- Thanh ghi điều khiển ngắt ngoại vi PIEx.
- Thanh ghi cờ ngắt PIRx.
- Thanh ghi điều khiển module ngoại vi cần ngắt.

INTERRUPT

TIMER

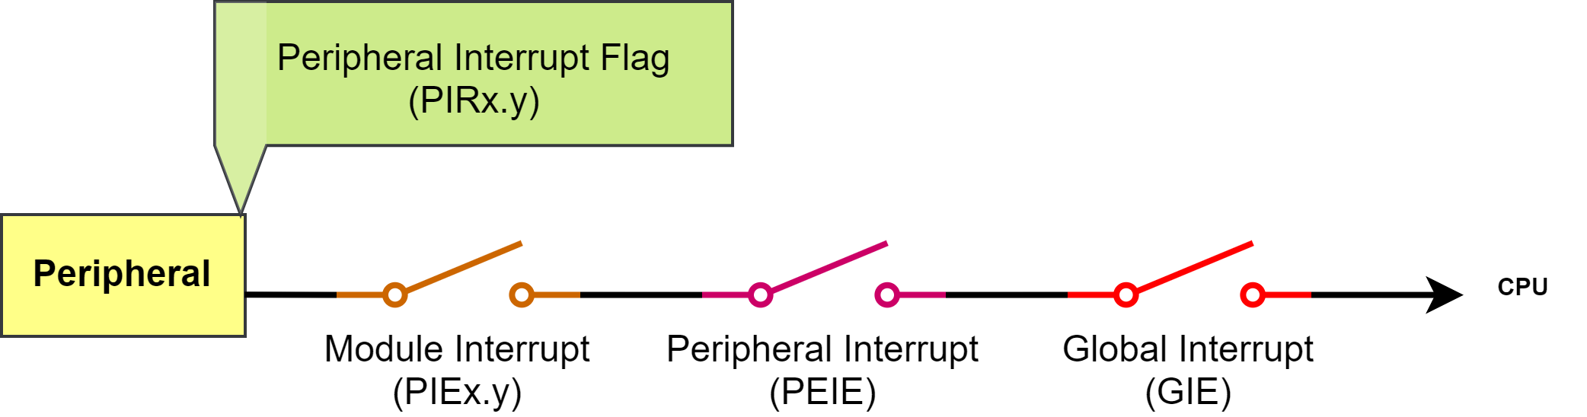
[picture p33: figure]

## INTERRUPT 3. THANH GHI NGẮT

- Thanh ghi điều khiển ngắt INTCON:

INTERRUPT

TIMER

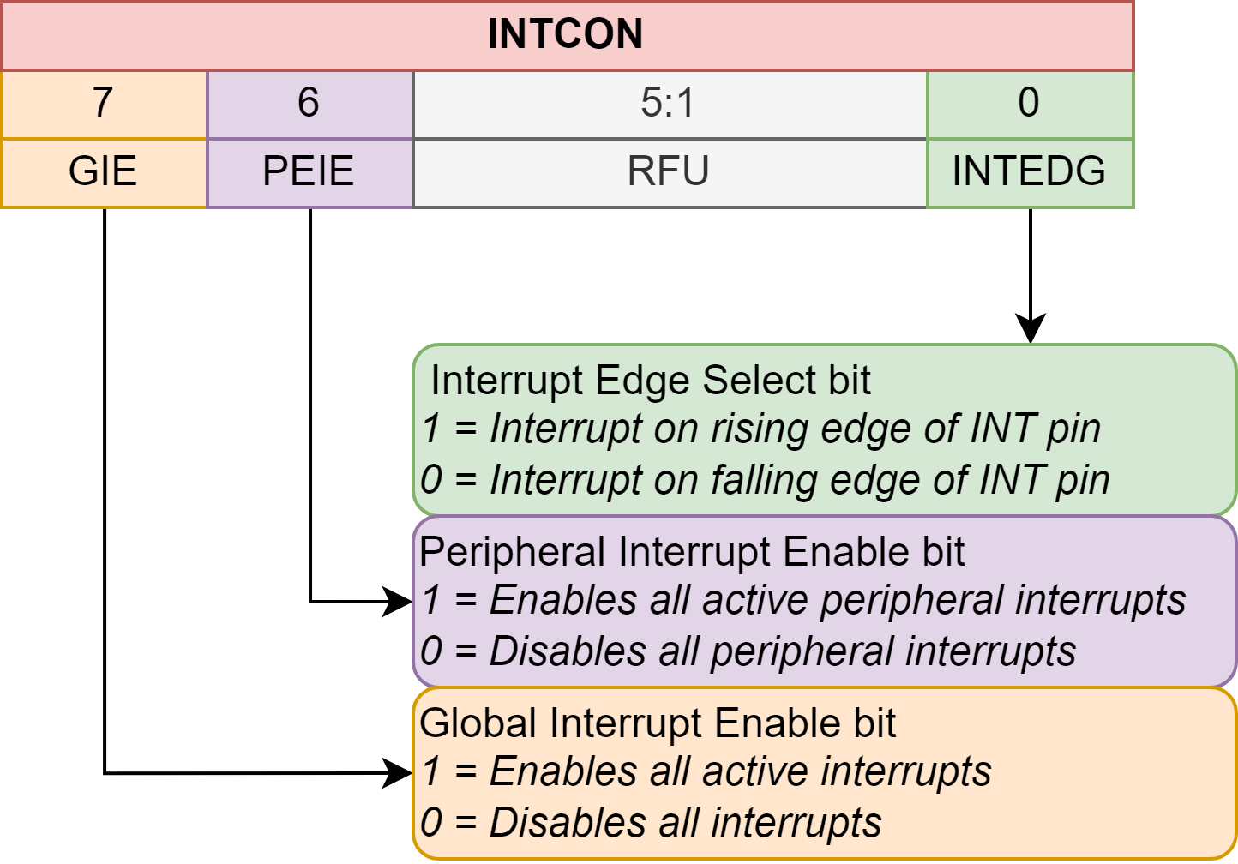
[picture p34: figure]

## INTERRUPT 4. CHƯƠNG TRÌNH NGẮT

- Chương trình ngắt đặt bất kỳ vị trí nào trong file source.
- Cấu trúc:
void __interrupt() FuncName(void)
{
if(INCONbits.PEIE) // Ngắt ngoại vi
{}
else // Ngắt ngoài ngoại vi
{}
}

INTERRUPT

TIMER

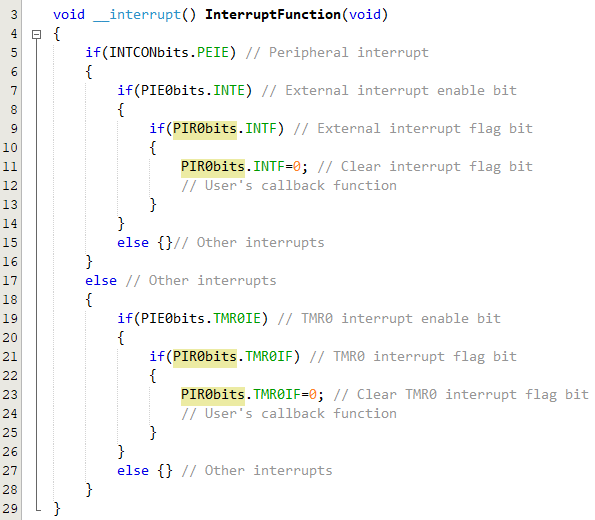
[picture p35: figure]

## INTERRUPT 4. CHƯƠNG TRÌNH NGẮT

- Cấu hình ngắt:
- Cấu hình module ngoại vi.
- Xoá cờ ngắt module ngoại vi.
- Cho phép ngắt module ngoại vi.
- Cho phép ngắt ngoại vi (PEIE).
- Cho phép ngắt toàn cục (GIE).

INTERRUPT

TIMER


## TIMER 1. TỔNG QUAN

- Timer/counter thực tế là một bộ đếm với giá trị đếm tăng 1 đơn vị tương ứng với mỗi xung clock cấp vào.
- Timer/counter bản chất là 1 module, chúng chỉ khác nhau về nguồn clock.
  - Timer: Xung clock xác định
được tần số, sử dụng để
đếm thời gian.
  - Counter: Xung clock không
xác định tần số, sử dụng để đếm sự kiện.

INTERRUPT

TIMER


## TIMER 1. TỔNG QUAN

- PIC16F18877 có 7 timer:
  - Timer 0: 8-bit hoặc 16-bit.
  - Timer 1/3/5: 16-bit.
  - Timer 2/4/6: 8-bit.
- Hai chế độ hoạt động:
  - Tràn (Overflow).
  - So sánh (Compare).

INTERRUPT

TIMER


## TIMER 2. CHẾ ĐỘ TRÀN

- Áp dụng cho timer 16-bit (TMR0/1/3/5).
- Hoạt động:
  - Ứng với mỗi xung cạnh lên,
bộ đếm sẽ tăng 1 giá trị,
khi đạt giá trị tối đa sẽ sinh ngắt
và reset timer về 0.
  - Giá trị bắt đầu là tuỳ chọn.

INTERRUPT

TIMER


## TIMER 2. CHẾ ĐỘ TRÀN

- Tính toán:
Tần số xung cấp vào timer: Ftmr=(Fin)/(Pre)
Khoảng định thời: từ 1000/(Ftmr) đến 1000/(Ftmr)×65536 (ms)
Tần suất tràn: Fov=(Ftmr)/(65536−TMR)=(Fin)/(Pre×(65536−TMR))
Tần suất ngắt (TMR=0, Pos>1): Fint=(Fov)/(Pos)=(Fin)/(Pre×Pos×65536)
Tần suất ngắt (Pos=1): Fint=Fov=(Fin)/(Pre×(65536−TMR))⇒TMR=65536−(Fin)/(Fint×Pre)

INTERRUPT

TIMER

## TIMER 2. CHẾ ĐỘ TRÀN

- Ví dụ:
Tần số xung cấp vào timer: Ftmr=(Fin)/(Pre)=31000/8=3875Hz
Khoảng định thời: từ 1000/3875=0.258ms đến 1000/3875×65536=16912.516ms
Giả sử ta muốn ngắt sau mỗi 500ms (Pos=1 ⇒ Fov=Fint=2Hz):
Giá trị TMR theo Fint: TMR=65536−31000/(2×8)=63599.
MCU 8-bit nên thanh ghi 16-bit sẽ tách thành 2 thanh ghi 8bit:
8-bit thấp: TMRL=TMR%256= 111
8-bit cao: TMRH=(TMR)/256=248

INTERRUPT

TIMER

## TIMER 2. CHẾ ĐỘ TRÀN

- Cấu hình TMR trên MPLAB:
- Bật module timer.
- Cấu hình Fin, Pre, Pos.
- Cấu hình giá trị timer.
- Khởi động timer.
- Cấu hình interrupt.

INTERRUPT

TIMER


## TIMER 2. CHẾ ĐỘ TRÀN

- Ngắt TMR trên MPLAB:
- Kiểm tra bit điều khiển ngắt.
- Kiểm tra cờ ngắt.
- Xoá cờ ngắt.
- Đặt lại giá trị bắt đầu của TMR.
- Thực hiện chương trình người dùng.
→ Lưu ý: Tránh sử dụng biến hoặc function trùng với chương trình chính để tránh sự xung đột.

INTERRUPT

TIMER


## TIMER 3. CHẾ ĐỘ SO SÁNH

- Áp dụng cho timer 8-bit
(TMR0/2/4/6).
- Hoạt động:
  - Ứng với mỗi xung (cạnh tuỳ chọn),
bộ đếm sẽ tăng 1 giá trị,
khi đạt giá trị của thanh ghi so sánh
sẽ sinh ngắt và reset timer về 0.
  - Giá trị TMR bắt đầu là 0.
  - Giá trị thanh ghi so sánh là tuỳ chọn.

INTERRUPT

TIMER


## TIMER 3. CHẾ ĐỘ SO SÁNH

- Tính toán:
Tần số xung cấp vào timer: Ftmr=(Fin)/(Pre)
Khoảng định thời: từ 1000/(Ftmr) đến 1000/(Ftmr)×256 (ms)
Tần suất tràn: Fov=(Ftmr)/(TMR+1)=(Fin)/(Pre×(TxPR+1))⇒TxPR=(Fin)/(Fov×Pre)−1
Tần suất ngắt: Fint=(Fov)/(Pos)=(Fin)/(Pre×Pos×(TxPR+1))⇒TxPR=(Fin)/(Fint×Pre×Pos)−1

INTERRUPT

TIMER

## TIMER 3. CHẾ ĐỘ SO SÁNH

- Ví dụ:
Tần số xung cấp vào timer: Ftmr=(Fin)/(Pre)=31000/2=15500Hz
Khoảng định thời: từ 1000/15500≈0.065ms đến 1000/15500×256≈16.516ms
Giả sử ta muốn ngắt sau mỗi 100ms (>16.516ms), ta có Fint=10Hz , chọn Pos=10
⇒Fov=Fint×Pos=10×10=100Hz
Giá trị TxPR theo Fov: TxPR=31000/(100×2)−1=154.

INTERRUPT

TIMER

## TIMER 3. CHẾ ĐỘ SO SÁNH

- Cấu hình TMR trên MPLAB:
- Bật module timer.
- Cấu hình Fin, Pre, Pos.
- Cấu hình cạnh xung clock.
- Cấu hình chế độ hoạt động.
- Cấu hình giá trị timer.
- Khởi động timer.
- Cấu hình interrupt.

INTERRUPT

TIMER


## TIMER 3. CHẾ ĐỘ SO SÁNH

- Ngắt TMR trên MPLAB:
- Kiểm tra bit điều khiển ngắt.
- Kiểm tra cờ ngắt.
- Xoá cờ ngắt.
- Đặt lại giá trị bắt đầu của TMR.
- Thực hiện chương trình người dùng.
→ Lưu ý: Tránh sử dụng biến hoặc function trùng với chương trình chính để tránh sự xung đột.

INTERRUPT

TIMER


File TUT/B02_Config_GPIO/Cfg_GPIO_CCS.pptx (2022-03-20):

## PIC16F DEVELOPMENT KIT

PIC16F18877 – CONFIGURATION & GPIO
(PIC C COMPILER)


## NỘI DUNG

GIỚI THIỆU CHUNG
CONFIGURATION
GENERAL-PURPOSE INPUT/OUTPUT

## GIỚI THIỆU CHUNG 1. HỆ THỐNG VI ĐIỀU KHIỂN

1. Khối dao động
2. Khối xử lý
3. Khối bộ nhớ
4. Khối ngoại vi
5. Khối sự kiện
6. Các khối khác:
Quản lý nguồn,
Gỡ lỗi, …

GIỚI THIỆU CHUNG

CONFIGURATION

GENERAL-PURPOSE INPUT/OUTPUT


## GIỚI THIỆU CHUNG 2. CÔNG CỤ PHÁT TRIỂN

1. MPLAB X IDE/ PIC C IDE
Môi trường soạn thảo, định dạng, gỡ lỗi, …
2. MPLAB XC8/ CCS C
Chuyển đổi ngôn ngữ C/Asm sang mã thực thi.
3. Evaluation Kit

GIỚI THIỆU CHUNG

CONFIGURATION

GENERAL-PURPOSE INPUT/OUTPUT


## GIỚI THIỆU CHUNG 3. TÀI LIỆU KỸ THUẬT

1. Datasheet: DS40001825F (https://ww1.microchip.com/downloads/en/DeviceDoc/PIC16LF1885777_Data_Sheet_40001825F.pdf)
2. User’s guide: C:\Program Files (x86)\PICC\ccsc.chm
3. Code Examples: C:\Program Files (x86)\PICC\Examples

GIỚI THIỆU CHUNG

CONFIGURATION

GENERAL-PURPOSE INPUT/OUTPUT

## CONFIGURATION

Để làm việc với vi điều khiển cần:
- Cấu hình được chip.
- Quản lý được bộ nhớ.
- Quản lý được ngoại vi.

GIỚI THIỆU CHUNG

CONFIGURATION

GENERAL-PURPOSE INPUT/OUTPUT

## CONFIGURATION 1. CẤU HÌNH DAO ĐỘNG

- PIC16F18877 có 2 nhóm dao động:
- Dao động nội: 31KHz đến 32MHz.
- Dao động ngoài:
  - Clock chính OSC: lên đến 32MHz.
  - Clock phụ SOSC: 32768Hz.
- Tốc độ xử lý: FCPU=FOSC/4.

GIỚI THIỆU CHUNG

CONFIGURATION

GENERAL-PURPOSE INPUT/OUTPUT


## CONFIGURATION 1. CẤU HÌNH DAO ĐỘNG

- Kit sử dụng dao động nội.
- Tốc độ tối đa 32MHz.

GIỚI THIỆU CHUNG

CONFIGURATION

GENERAL-PURPOSE INPUT/OUTPUT


## CONFIGURATION 2. CẤU HÌNH KHÁC

- Có thể sử dụng cấu hình mặc định.

GIỚI THIỆU CHUNG

CONFIGURATION

GENERAL-PURPOSE INPUT/OUTPUT


## GPIO 1. I/O PORTS

- PIC16F18877 có 5 port:
Port A, B, C, D: 8 I/O.
Port E: 4 I/O. Có 1 I/O được mặc định
chức năng MCLR.

GIỚI THIỆU CHUNG

CONFIGURATION

GENERAL-PURPOSE INPUT/OUTPUT


## GPIO 2. DIGITAL OUTPUTS

- Cấu hình trong Project Wizard:
- Cấu hình trong code:
#use FIXED_IO(<P>_outputs=PIN_<P>1)

#use FIXED_IO(A_outputs=PIN_A1, PIN_A2)

Cấu hình ngõ ra:
set_tris_<P>(value);
Bit tương ứng có giá trị 0 thì pin sẽ là ngõ ra.
Đặt mức logic theo port:
output_<P>(value);
Đặt mức logic theo pin:
output_bit(PIN, logic);
output_high(PIN);
output_low(PIN);
output_toggle(PIN);

GIỚI THIỆU CHUNG

CONFIGURATION

GENERAL-PURPOSE INPUT/OUTPUT


## GPIO 3. DIGITAL INPUTS

- Cấu hình trong Project Wizard:
- Cấu hình trong code:
Cấu hình ngõ vào:
set_tris_<P>(value);
Bit tương ứng có giá trị 1 thì pin sẽ là ngõ vào.
Cấu hình pull-up:
port_<P>_pullups(value);
Bit tương ứng có giá trị 1 thì pin sẽ pull-up.
Đọc mức logic theo port:
logic=input_<P>(value);
Đọc mức logic theo pin:
Logic=input(PIN);

GIỚI THIỆU CHUNG

CONFIGURATION

GENERAL-PURPOSE INPUT/OUTPUT


## GPIO 3. VÍ DỤ

GIỚI THIỆU CHUNG

CONFIGURATION

GENERAL-PURPOSE INPUT/OUTPUT


## GPIO 3. VÍ DỤ

Simple button:

GIỚI THIỆU CHUNG

CONFIGURATION

GENERAL-PURPOSE INPUT/OUTPUT


## GPIO 3. VÍ DỤ

Latched button:

GIỚI THIỆU CHUNG

CONFIGURATION

GENERAL-PURPOSE INPUT/OUTPUT


## GPIO 3. VÍ DỤ

Debounce button:

GIỚI THIỆU CHUNG

CONFIGURATION

GENERAL-PURPOSE INPUT/OUTPUT


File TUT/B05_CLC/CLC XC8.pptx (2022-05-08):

## PIC16F DEVELOPMENT KIT

PIC16F18877 – CLC
(XC8 COMPILER)


## NỘI DUNG

GIỚI THIỆU
COMBINATORIAL LOGIC
LATCHES

## GIỚI THIỆU

GIỚI THIỆU

COMBINATORIAL LOGIC

LATCHES

## COMBINATORIAL LOGIC

GIỚI THIỆU

COMBINATORIAL LOGIC

LATCHES

## LATCHES

GIỚI THIỆU

COMBINATORIAL LOGIC

LATCHES

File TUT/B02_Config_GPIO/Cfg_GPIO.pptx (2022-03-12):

## PIC16F DEVELOPMENT KIT

PIC16F18877 – CONFIGURATION & GPIO


## NỘI DUNG

GIỚI THIỆU CHUNG
CONFIGURATION
GENERAL-PURPOSE INPUT/OUTPUT

## GIỚI THIỆU CHUNG 1. HỆ THỐNG VI ĐIỀU KHIỂN

1. Khối dao động
2. Khối xử lý
3. Khối bộ nhớ
4. Khối ngoại vi
5. Khối sự kiện
6. Các khối khác:
Quản lý nguồn,
Gỡ lỗi, …

GIỚI THIỆU CHUNG

CONFIGURATION

GENERAL-PURPOSE INPUT/OUTPUT


## GIỚI THIỆU CHUNG 2. CÔNG CỤ PHÁT TRIỂN

1. MPLAB X IDE/ PIC C IDE
Môi trường soạn thảo, định dạng, gỡ lỗi, …
2. MPLAB XC8/ CCS C
Chuyển đổi ngôn ngữ C/Asm sang mã thực thi.
3. Evaluation Kit

GIỚI THIỆU CHUNG

CONFIGURATION

GENERAL-PURPOSE INPUT/OUTPUT


## GIỚI THIỆU CHUNG 3. TÀI LIỆU KỸ THUẬT

1. Datasheet: DS40001825 (https://ww1.microchip.com/downloads/en/DeviceDoc/PIC16LF1885777_Data_Sheet_40001825F.pdf)
2. Programming Specifications: DS40001753 (https://ww1.microchip.com/downloads/en/DeviceDoc/40001753B.pdf)
3. Application Notes: https://www.microchip.com/en-us/application-notes
4. Code Examples: https://www.microchip.com/doclisting/CodeExamplesByFunc.aspx

GIỚI THIỆU CHUNG

CONFIGURATION

GENERAL-PURPOSE INPUT/OUTPUT

## CONFIGURATION 1. CẤU TRÚC BỘ NHỚ

Để làm việc với vi điều khiển cần:
- Cấu hình được chip.
- Quản lý được bộ nhớ.
- Quản lý được ngoại vi.
Xem thêm:
- DS40001753 (https://ww1.microchip.com/downloads/en/DeviceDoc/40001753B.pdf) – trang 3.
- DS40001825 (https://ww1.microchip.com/downloads/en/DeviceDoc/PIC16LF1885777_Data_Sheet_40001825F.pdf) – trang 39.

GIỚI THIỆU CHUNG

CONFIGURATION

GENERAL-PURPOSE INPUT/OUTPUT


## CONFIGURATION 2. CẤU HÌNH CHIP

- Quy định các tính năng cụ thể của chip, bao gồm:
dao động, quản lý lỗi, quản lý nguồn, tính năng bảo mật, …
- Các bit cấu hình là cố định, không thay đổi trong quá
trình hoạt động.
- Vùng nhớ cấu hình chip có độ dài 5 word:
Word 1: Oscillator
Word 2: Supervisors
Word 3: Watchdog
Word 4: Memory
Word 5: Code protection

GIỚI THIỆU CHUNG

CONFIGURATION

GENERAL-PURPOSE INPUT/OUTPUT

## CONFIGURATION 3. CẤU DAO ĐỘNG

- PIC16F18877 có 2 nhóm dao động:
- Dao động nội: 31KHz đến 32MHz.
- Dao động ngoài: lên đến 32MHz.
- Tốc độ xử lý: FCPU=FOSC/4.

GIỚI THIỆU CHUNG

CONFIGURATION

GENERAL-PURPOSE INPUT/OUTPUT


## CONFIGURATION 3. CẤU DAO ĐỘNG

GIỚI THIỆU CHUNG

CONFIGURATION

GENERAL-PURPOSE INPUT/OUTPUT


## GPIO 1. I/O PORTS

- PIC16F18877 có 5 port:
Port A, B, C, D: 7 I/O.
Port E: 4 I/O. Có 1 I/O được mặc định
chức năng MCLR.

GIỚI THIỆU CHUNG

CONFIGURATION

GENERAL-PURPOSE INPUT/OUTPUT


## GPIO 1. I/O PORTS

- Mỗi port được điều khiển bởi các
thanh ghi sau với mỗi bit tương ứng
1 pin:
TRISx: Qui định ngõ vào/ra. Pin là ngõ vào
nếu bit tương ứng là 1.
ANSELx: Qui định dạng tín hiệu là số (0)
hoặc tương tự (1).
LATx: Qui định trạng thái ngõ ra.
PORTx: Lưu trạng thái ngõ vào.

GIỚI THIỆU CHUNG

CONFIGURATION

GENERAL-PURPOSE INPUT/OUTPUT


## GPIO 1. I/O PORTS

WPUx: Cấu hình điện trở kéo lên.
INLVLx: Qui định chuẩn logic TTL
hoặc CMOS. (Mặc định)
SLRCONx: Qui định tốc độ thay đổi
trạng thái. (Mặc định)
ODCONx: Cấu hình ngõ ra cực
nguồn hở.

GIỚI THIỆU CHUNG

CONFIGURATION

GENERAL-PURPOSE INPUT/OUTPUT

## GPIO 2. DIGITAL OUTPUTS

Qui trình cấu hình:
- Cấu hình tín hiệu số: ANSELxbits.ANSxy=0
- Cấu hình ngõ ra: TRISxbits.TRISxy=0
- Cấu hình cực nguồn: ODCONxbits.ODCxy=0/1
- Đặt trạng thái: LATxbits.LATxy=0/1

GIỚI THIỆU CHUNG

CONFIGURATION

GENERAL-PURPOSE INPUT/OUTPUT

## GPIO 3. DIGITAL INPUTS

Qui trình cấu hình:
- Cấu hình tín hiệu số: ANSELxbits.ANSxy=0
- Cấu hình ngõ vào: TRISxbits.TRISxy=0
- Cấu hình điện trở kéo: WPUAbits.WPUxy=0/1
- Đọc trạng thái: PORTxbits.Rxy

GIỚI THIỆU CHUNG

CONFIGURATION

GENERAL-PURPOSE INPUT/OUTPUT

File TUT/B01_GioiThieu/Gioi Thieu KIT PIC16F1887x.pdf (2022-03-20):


# NỘI DUNG

GIỚI THIỆU CHUNG; HƯỚNG DẪN NẠP CHƯƠNG TRÌNH

# HƯỚNG DẪN SỬ DỤNG VỚI MPLAB X IDE + XC8 COMPILER

# HƯỚNG DẪN SỬ DỤNG VỚI MPLAB X IDE + PIC C COMPILER

# GIỚI THIỆU CHUNG 1. CẤU TẠO

# Hệ thống

GIỚI THIỆU CHUNG

HD NẠP CHƯƠNG TRÌNH

HDSD VỚI XC8 COMPILER

HDSD VỚI PIC C COMPILER


# GIỚI THIỆU CHUNG 1. CẤU TẠO


# Sơ đồ khối

HD NẠP CHƯƠNG TRÌNH

HDSD VỚI XC8 COMPILER

HDSD VỚI PIC C COMPILER

# GIỚI THIỆU CHUNG

# 1. CẤU TẠO


# Các thành phần chính

HD NẠP CHƯƠNG TRÌNH

HDSD VỚI XC8 COMPILER

HDSD VỚI PIC C COMPILER

# GIỚI THIỆU CHUNG

# 2. TÍNH NĂNG

❖ Mạch nạp tích hợp dạng kéo thả, không sử dụng chương trình hỗ trợ.
❖ Tích hợp bộ chuyển đổi USB –UART.
❖ I/O mở rộng, SRAM.
❖ RTCC, Flash, cảm biến nhiệt.
❖ Bộ chuyển đổi logic điều khiển LED RGB.

HD NẠP CHƯƠNG TRÌNH

HDSD VỚI XC8 COMPILER

HDSD VỚI PIC C COMPILER

# GIỚI THIỆU CHUNG

# 3. VI ĐIỀU KHIỂN PIC16F18877

# So sánh PIC16F18877 & PIC16F877A

HD NẠP CHƯƠNG TRÌNH

HDSD VỚI XC8 COMPILER

HDSD VỚI PIC C COMPILER

| PIC16F877A | PIC16F18877
CPU Speed (MIPS) | 5@20MHz External clock | 8@32MHz Internal clock
Program Memory Size (KB) | 14.3 | 56
Data SRAM (bytes) | 368 | 4096
Data EEPROM (bytes) | 256 | 256
I/O Pins | 33 | 36
Low Power | No | Yes
Operation Voltage (V) | 2.0-5.5 | F: 2.3-5.5 LF: 1.8-3.6
Temperature Range (oC) | -40-125 | -40-125

# GIỚI THIỆU CHUNG

# 3. VI ĐIỀU KHIỂN PIC16F18877

# So sánh PIC16F18877 & PIC16F877A

HD NẠP CHƯƠNG TRÌNH

HDSD VỚI XC8 COMPILER

HDSD VỚI PIC C COMPILER

| PIC16F877A | PIC16F18877
ADC bits/Channels | 10/8 | 10/35
DAC bits/Channels | 0/0 | 5/1
CCP/PWM/Comparator | 2/0/2 | 5/2/2
Timer 8bit/16bit | 2/1 | 3/4
EUSART/MSSP (I2C/SPI) | 1/1 | 1/2
FVR/IOC | 0/0 | 2/35
ZCD/CWG/NCO/DSM/SMT | 0/0/0/0/0 | 1/3/1/1/2
CLC | 0 | 4
Peripheral Pin Select | No | Yes

# HD NẠP CHƯƠNG TRÌNH

# 1. CẬP NHẬT FW CHIP NẠP

❖ Bước 1: Kết nối Kit với máy tính bằng cáp micro USB.

HD NẠP CHƯƠNG TRÌNH

HDSD VỚI XC8 COMPILER

HDSD VỚI PIC C COMPILER


# HD NẠP CHƯƠNG TRÌNH

# 1. CẬP NHẬT FW CHIP NẠP

# ❖ Bước 2: Nhấn giữ nút RESET đến khi RLED, GLED cùng

sáng và Status LED nháy.

HD NẠP CHƯƠNG TRÌNH

HDSD VỚI XC8 COMPILER

HDSD VỚI PIC C COMPILER


# HD NẠP CHƯƠNG TRÌNH

# 1. CẬP NHẬT FW CHIP NẠP

# ❖ Bước 3: Truy cập vào bit.ly/3rMJ4hs, tìm phiên bản firmware mới nhất, so sánh với phiên bản hiện tại trong file BOOTLOADER/INFO.TXT

HD NẠP CHƯƠNG TRÌNH

HDSD VỚI XC8 COMPILER

HDSD VỚI PIC C COMPILER

# HD NẠP CHƯƠNG TRÌNH

# 1. CẬP NHẬT FW CHIP NẠP


# ❖ Bước 4: Tải về phiên bản firmware mới nhất lưu vào ổ đĩa

BOOTLOADER. Thiết bị tự khởi động lại sau khi cập nhật thành công.

HD NẠP CHƯƠNG TRÌNH

HDSD VỚI XC8 COMPILER

HDSD VỚI PIC C COMPILER

# HD NẠP CHƯƠNG TRÌNH

# 2. NẠP FW CHO PIC16F18877

❖ Bước 1: Kết nối Kit với máy tính bằng cáp micro USB.

HD NẠP CHƯƠNG TRÌNH

HDSD VỚI XC8 COMPILER

HDSD VỚI PIC C COMPILER

# HD NẠP CHƯƠNG TRÌNH

# 2. NẠP FW CHO PIC16F18877

❖ Bước 2: Copy và paste file hex vào folder PIC16DEVKIT.


# → Quá trình copy sẽ lỗi nếu file sai định dạng hoặc không phải

file hex của PIC16F18877.

HD NẠP CHƯƠNG TRÌNH

HDSD VỚI XC8 COMPILER

HDSD VỚI PIC C COMPILER

# HDSD VỚI MPLAB X IDE + XC8 COMPILER

# ❖ Bước 1: Khởi động MPLAB X IDE. Trên thanh công cụ, chọn

File → New Project… (Ctrl+Shift+N).

HD NẠP CHƯƠNG TRÌNH

HDSD VỚI XC8 COMPILER

HDSD VỚI PIC C COMPILER

# HDSD VỚI MPLAB X IDE + XC8 COMPILER


# ❖ Bước 2: Trong cửa sổ New Project, chọn

Standalone Project → Next.

HD NẠP CHƯƠNG TRÌNH

HDSD VỚI XC8 COMPILER

HDSD VỚI PIC C COMPILER

# HDSD VỚI MPLAB X IDE + XC8 COMPILER

❖ Bước 3: Nhập tên chip vào ô Device → Next.

HD NẠP CHƯƠNG TRÌNH

HDSD VỚI XC8 COMPILER

HDSD VỚI PIC C COMPILER


# HDSD VỚI MPLAB X IDE + XC8 COMPILER

❖ Bước 4: Chọn XC8.

HD NẠP CHƯƠNG TRÌNH

HDSD VỚI XC8 COMPILER

HDSD VỚI PIC C COMPILER


# HDSD VỚI MPLAB X IDE + XC8 COMPILER

❖ Bước 5: Đặt tên cho project và vị trí lưu.
→ Không đặt tên project hoặc lưu vào vị trí mà đường dẫn chứa tiếng Việt có dấu.

HD NẠP CHƯƠNG TRÌNH

HDSD VỚI XC8 COMPILER

HDSD VỚI PIC C COMPILER

# HDSD VỚI MPLAB X IDE + XC8 COMPILER


# Cây thư mục của project

## Hai folder quan trọng gồm: - Header Files: Chứa các file .h - Source Files: Chứa các file .c, .asm

HD NẠP CHƯƠNG TRÌNH

HDSD VỚI XC8 COMPILER

HDSD VỚI PIC C COMPILER

# HDSD VỚI MPLAB X IDE + XC8 COMPILER

# ❖ Bước 6: Cấu hình project. Click vào project, trên thanh Run toolbar, chọn Customize…

HD NẠP CHƯƠNG TRÌNH

HDSD VỚI XC8 COMPILER

HDSD VỚI PIC C COMPILER


# HDSD VỚI MPLAB X IDE + XC8 COMPILER

# ❖ Bước 6: Cấu hình project. Trong tab Conf:[default] → Building


## → Click chọn:

Execute this line after build.

## → Điền dòng lệnh sau:

copy ${ImagePath} ".\lastbuild.${OUTPUT_SUFFIX}“

## Lệnh này sẽ tạo ra file lastbuild.hex

trong project folder sau mỗi lần build.

## →Click chọn:

## Normalize hex file → Apply

HD NẠP CHƯƠNG TRÌNH

HDSD VỚI XC8 COMPILER

HDSD VỚI PIC C COMPILER

# HDSD VỚI MPLAB X IDE + XC8 COMPILER

# ❖ Bước 6: Cấu hình project. Trong tab XC8 Global Options


# → XC8 Compiler

## →Trong mục Option categories:

Preprocessing and messages, Đặt Warning level lên mức 0.
→ Apply.

HD NẠP CHƯƠNG TRÌNH

HDSD VỚI XC8 COMPILER

HDSD VỚI PIC C COMPILER

# HDSD VỚI MPLAB X IDE + XC8 COMPILER

# ❖ Bước 6: Cấu hình project. Trong tab XC8 Global Options

# → XC8 Compiler

## →Trong mục Option categories:

Optimizations,
Đặt Optimization level lên mức 2. → Apply → OK.

HD NẠP CHƯƠNG TRÌNH

HDSD VỚI XC8 COMPILER

HDSD VỚI PIC C COMPILER

# HDSD VỚI MPLAB X IDE + XC8 COMPILER

❖ Bước 7: Cấu hình nạp chương trình vào Kit.


Trong cây thư mục project,

# click phải chuột vào Important Files →

# Add Items to Important files… → Chọn file D2K.bat

→ Copy → Select.

HD NẠP CHƯƠNG TRÌNH

HDSD VỚI XC8 COMPILER

HDSD VỚI PIC C COMPILER

# HDSD VỚI MPLAB X IDE + XC8 COMPILER

❖ Bước 7: Cấu hình nạp chương trình vào Kit.


→ Kết nối Kit với máy tính.
→ Mở file D2K.bat vừa copy.

# → Sửa lại tên ổ đĩa đúng với tên

thật.

HD NẠP CHƯƠNG TRÌNH

HDSD VỚI XC8 COMPILER

HDSD VỚI PIC C COMPILER

# HDSD VỚI MPLAB X IDE + XC8 COMPILER

❖ Bước 8: Tạo source file.


# Click phải chuột vào Source Files → New → main.c

HD NẠP CHƯƠNG TRÌNH

HDSD VỚI XC8 COMPILER

HDSD VỚI PIC C COMPILER

# HDSD VỚI MPLAB X IDE + XC8 COMPILER

❖ Bước 8: Tạo source file. Đặt tên file và vị trí lưu.

# Mặc định file sẽ được tạo

trong project folder.

HD NẠP CHƯƠNG TRÌNH

HDSD VỚI XC8 COMPILER

HDSD VỚI PIC C COMPILER

# HDSD VỚI MPLAB X IDE + XC8 COMPILER


❖ Bước 9: Build project.

# Trên thanh công cụ, chọn Clean and Build

Main Project (Shift + F11).

# Nếu không có lỗi, cửa sổ

# Output sẽ thông báo

## BUILD SUCCESSFUL (total time:…)

HD NẠP CHƯƠNG TRÌNH

HDSD VỚI XC8 COMPILER

HDSD VỚI PIC C COMPILER

# HDSD VỚI MPLAB X IDE + XC8 COMPILER

❖ Bước 10: Nạp chương trình vào Kit.


# Click phải chuột vào file D2K.bat → Run Khi nạp thành công, cửa sổ Output hiển thị:

1 file(s) copied.

HD NẠP CHƯƠNG TRÌNH

HDSD VỚI XC8 COMPILER

HDSD VỚI PIC C COMPILER

# HDSD VỚI MPLAB X IDE + PIC C COMPILER

# ❖ Bước 1: Khởi động PIC C IDE. Trên thanh công cụ, chọn


# File → Project Wizard

→ Đặt tên và lưu file.

HD NẠP CHƯƠNG TRÌNH

HDSD VỚI XC8 COMPILER

HDSD VỚI PIC C COMPILER

# HDSD VỚI MPLAB X IDE + PIC C COMPILER

❖ Bước 2: Cấu hình project.

# Family: PIC16

Device: PIC16F18877.
…
→ Create Project.

HD NẠP CHƯƠNG TRÌNH

HDSD VỚI XC8 COMPILER

HDSD VỚI PIC C COMPILER

# HDSD VỚI MPLAB X IDE + PIC C COMPILER

❖ Bước 3: Build project.


# Khi build thành công, cửa sô

̉

# Output thông báo:

Build Successful.

# File hex được tạo ra và lưu

tại project folder.

HD NẠP CHƯƠNG TRÌNH

HDSD VỚI XC8 COMPILER

HDSD VỚI PIC C COMPILER

# HDSD VỚI MPLAB X IDE + PIC C COMPILER

❖ Bước 4: Nạp chương trình vào Kit.


Mở project folder,
Copy file hex vào Kit.

HD NẠP CHƯƠNG TRÌNH

HDSD VỚI XC8 COMPILER

HDSD VỚI PIC C COMPILER

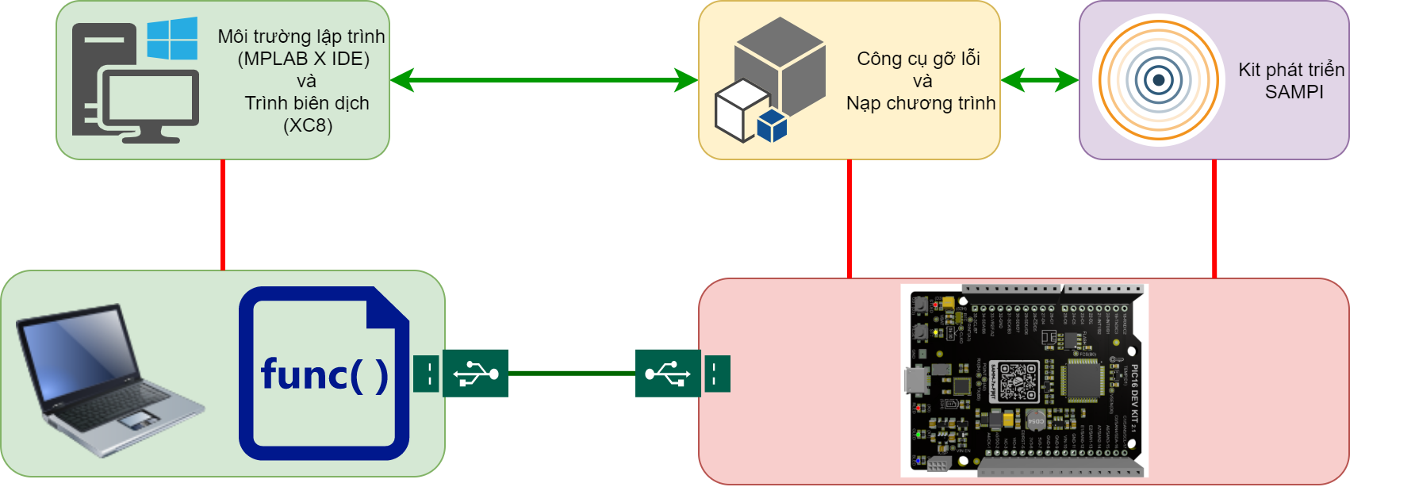
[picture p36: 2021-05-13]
Docs/SysOverview.png

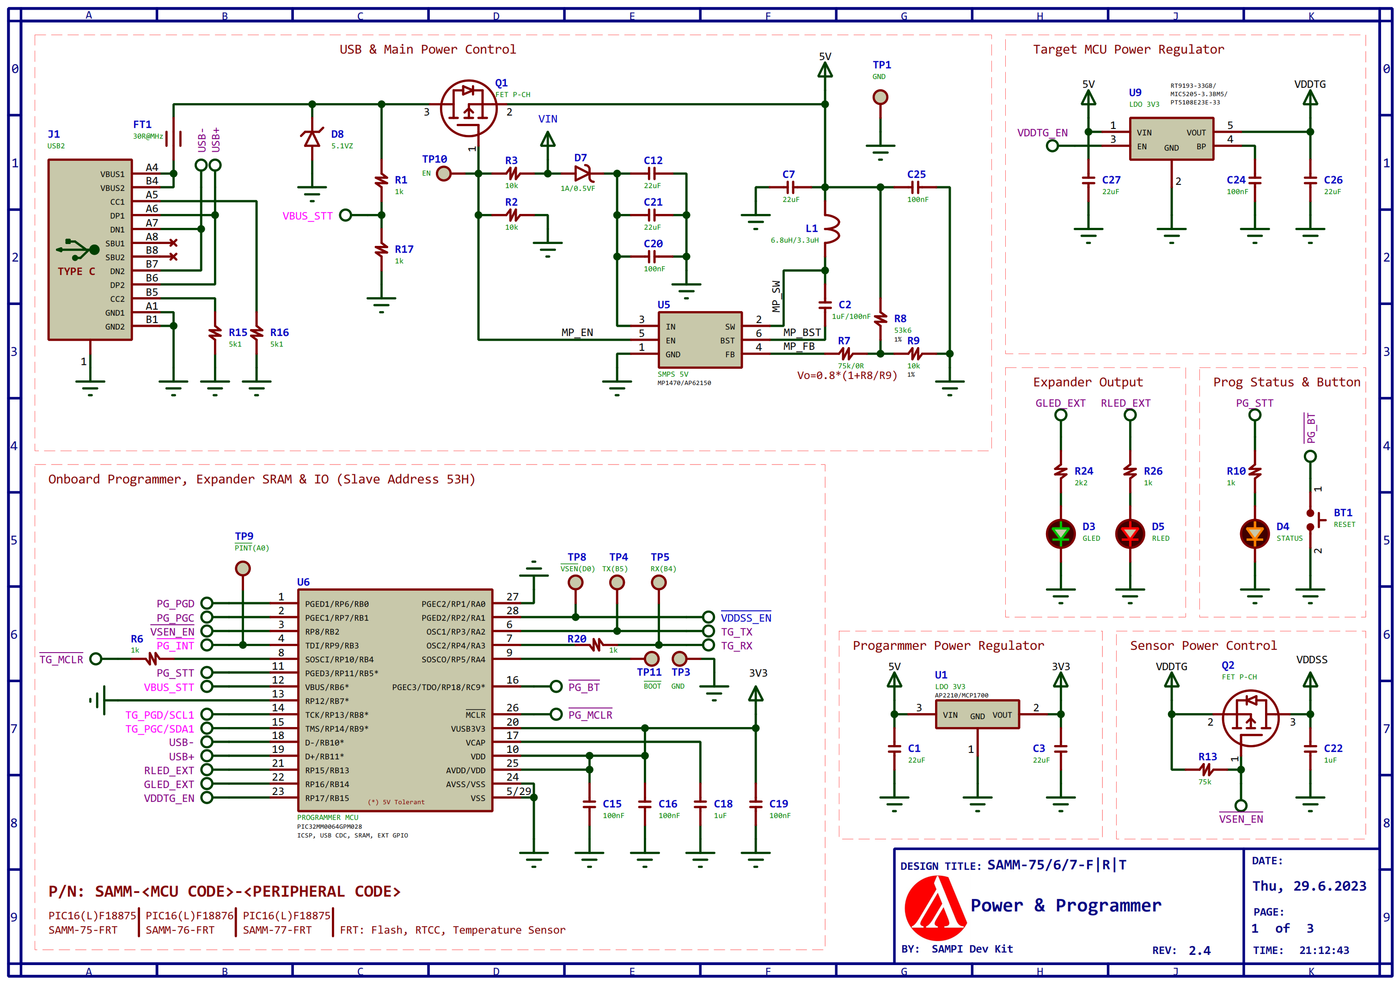
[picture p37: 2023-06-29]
HW/Product/Standard/Schematic/PIC16DevKit_001.png

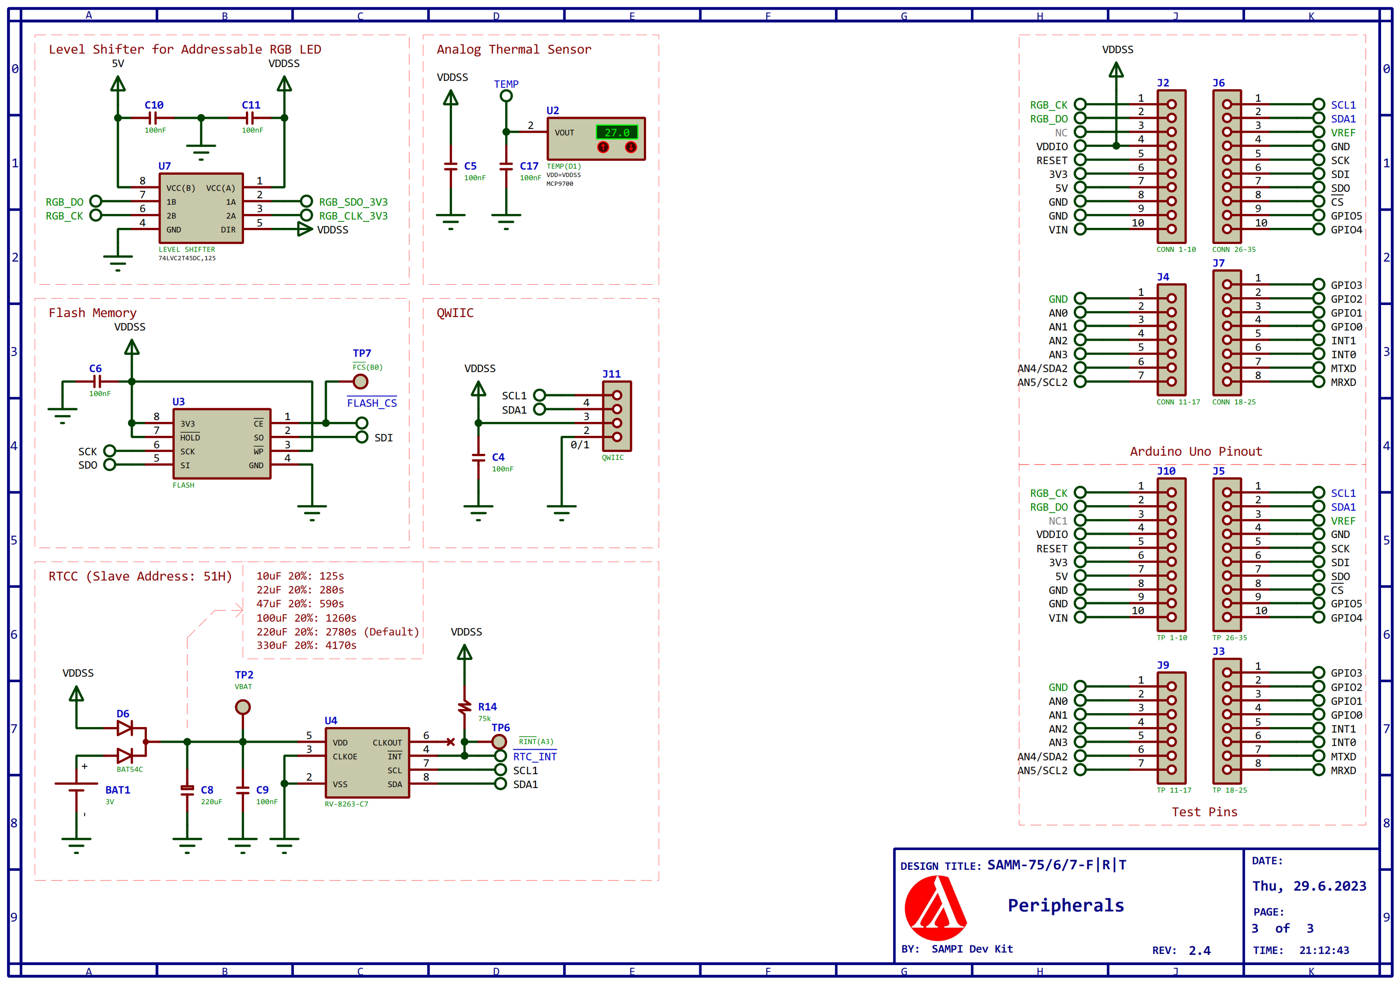
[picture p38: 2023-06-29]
HW/Product/Standard/Schematic/PIC16DevKit_003.png

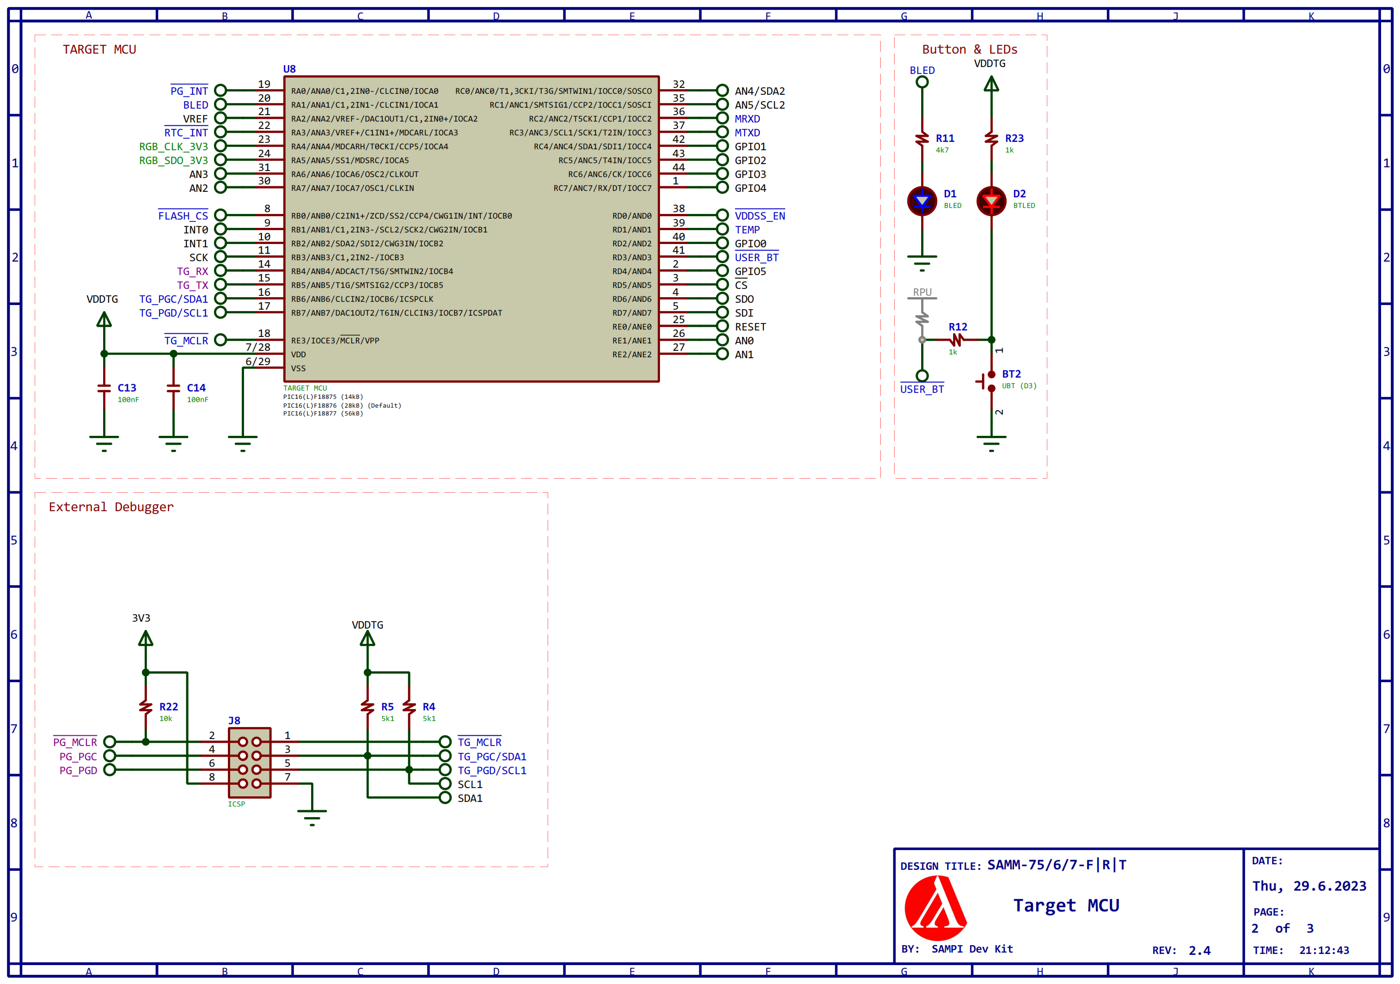
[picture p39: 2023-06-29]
HW/Product/Standard/Schematic/PIC16DevKit_002.png

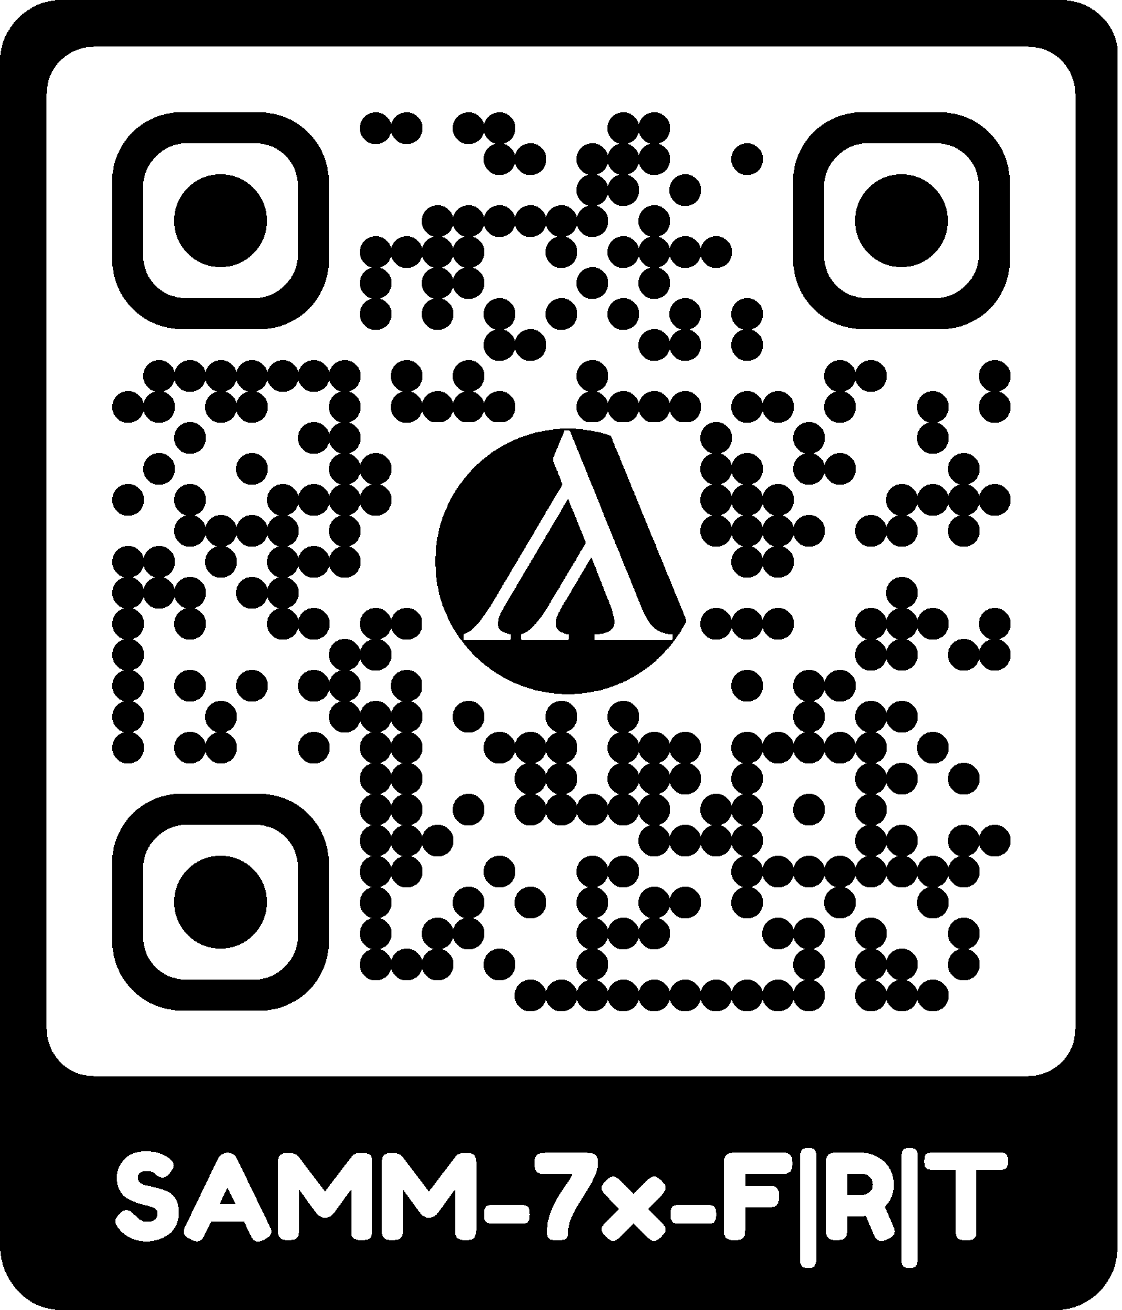
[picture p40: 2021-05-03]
Docs/bit.ly_3rMJ4hs.bmp

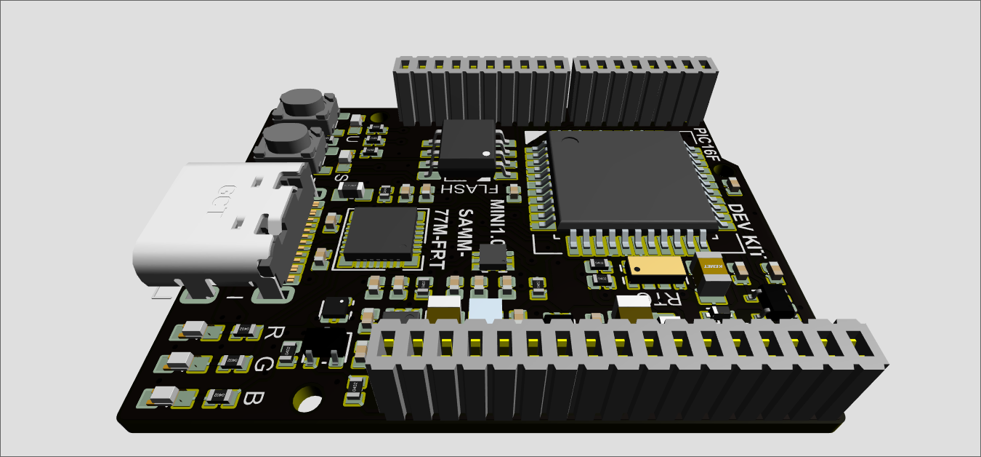
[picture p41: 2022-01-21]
HW/Product/Mini/Picture/ScreenShot_20220119223801.png

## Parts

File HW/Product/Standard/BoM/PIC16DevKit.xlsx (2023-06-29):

No | Stock Code | Description | References | Quantity | Unit Cost | Sub-Cost
1 | CC0805ZKY5V6BB226 | CAP CER 22UF 10V Y5V 0805 | C1,C3,C7,C12,C21,C26,C27 | 7 | $0.14220 | $0.99540
2 | CC0603JRX7R7BB105 | CAP CER 1UF 16V X7R 0603 | C2,C18,C22 | 3 | $0.16400 | $0.49200
3 | CC0603JRX7R7BB104 | CAP CER 0.1UF 16V X7R 0603 | C4,C5,C6,C9,C10,C11,C13,C14,C15,C16,C17,C19,C20,C24,C25 | 15 | $0.03010 | $0.45150
4 | TMCMB0J227MTRF | CAP TANT 220UF 20% 6.3V 1411 | C8 | 1 | $0.56200 | $0.56200
6 | AC0603JR-071KL | RES SMD 1K OHM 5% 1/10W 0603 | R1,R6,R10,R12,R17,R20,R23,R26 | 8 | $0.01180 | $0.09440
7 | RT0603FRE0710KL | RES SMD 10K OHM 1% 1/10W 0603 | R2,R3,R9,R22 | 4 | $0.05900 | $0.23600
8 | RC0603FR-075K1L | RES 5.1K OHM 1% 1/10W 0603 | R4,R5,R15,R16 | 4 | $0.01800 | $0.07200
9 | RC0603FR-0775KL | RES SMD 75K OHM 1% 1/10W 0603 | R7 | 1 | $0.01800 | $0.01800
10 | RC0603FR-0753K6L | RES 53.6K OHM 1% 1/10W 0603 | R8 | 1 | $0.01800 | $0.01800
11 | AC0603JR-074K7L | RES SMD 4.7K OHM 5% 1/10W 0603 | R11 | 1 | $0.01900 | $0.01900
12 | RC0603FR-0775KL | RES SMD 75K OHM 1% 1/10W 0603 | R13,R14 | 2 | $0.01800 | $0.03600
13 | AC0603JR-072K2L | RES SMD 2.2K OHM 5% 1/10W 0603 | R24 | 1 | $0.01900 | $0.01900
14 | AP2210N-3.3TRG1 | IC REG LINEAR 3.3V 300MA SOT23-3 | U1 | 1 | $0.32300 | $0.32300
15 | MCP9700T-H/LT | SENSOR ANALOG -10C-125C SOT23-3 | U2 | 1 | $0.46000 | $0.46000
16 | SST25VF040B-50-4C-SAF-T | IC FLASH 4MBIT SPI 50MHZ 8SOIC | U3 | 1 | $1.17000 | $1.17000
17 | RV-8263-C7-32.768KHZ-20PPM-TA-QC | IC RTC CLK/CALENDAR I2C 8SON | U4 | 1 | $1.53700 | $1.53700
18 | MP1470GJ-Z | IC REG BUCK ADJ 2A TSOT23-6 | U5 | 1 | $1.53200 | $1.53200
19 | PIC32MM0064GPM028-I/M6 | IC MCU 32BIT 64KB FLASH 28UQFN | U6 | 1 | $2.51000 | $2.51000
20 | 74LVC2T45DC,125 | IC TRNSLTR BIDIRECTIONAL 8VSSOP | U7 | 1 | $0.72900 | $0.72900
21 | PIC16F18876-I/PT | IC MCU 8BIT 28KB FLASH 44TQFP | U8 | 1 | $2.05000 | $2.05000
22 | MIC5504-3.3YM5-TR | IC REG LINEAR 3.3V 300MA SOT23-5 | U9 | 1 | $0.16000 | $0.16000
23 | SSM3J378R,LF | MOSFET P-CH 20V 6A SOT23F | Q1,Q2 | 2 | $0.28800 | $0.57600
24 | 150060BS75000 | LED BLUE CLEAR 0603 SMD | D1 | 1 | $0.17000 | $0.17000
25 | 150060SS75000 | LED RED CLEAR 0603 SMD | D2 | 1 | $0.15000 | $0.15000
26 | 150060VS75000 | LED GREEN CLEAR 0603 SMD | D3 | 1 | $0.15000 | $0.15000
27 | 150060YS75000 | LED YELLOW CLEAR 0603 SMD | D4 | 1 | $0.15000 | $0.15000
28 | 150060SS75000 | LED RED CLEAR 0603 SMD | D5 | 1 | $0.15000 | $0.15000
29 | BAT54C | DIODE ARRAY SCHOTTKY 30V SOT-23-3 | D6 | 1 | $0.32200 | $0.32200
30 | SS14 | DIODE SCHOTTKY 40V 1A DO214AC | D7 | 1 | $0.19900 | $0.19900
31 | SMAJ5.0CA | TVS, BI-DIR, 400W, 5V, DO-214AC | D8 | 1 | $0.21000 | $0.21000
32 | PTS810 SJG 250 SMTR LFS | SWITCH TACTILE SPST-NO 0.05A 16V | BT1,BT2 | 2 | $0.36300 | $0.72600
34 | 2508056017Y2 | FERRITE BEAD 600 OHM 0805 1LN | FT1 | 1 | $0.05000 | $0.05000
35 | USB4105-GF-A | CONN RCP USB2.0 TYP C 24P SMD RA | J1 | 1 | $0.68800 | $0.68800
36 | RS1-10-G | RECEPTACLE STRIP 10P 2.54MM PITC | J2,J6 | 2 | $0.54200 | $1.08400
37 | RS1-07-G | RECEPTACLE STRIP 7P 2.54MM PITCH | J4 | 1 | $0.41400 | $0.41400
39 | RS1-08-G | RECEPTACLE STRIP 8P 2.54MM PITCH | J7 | 1 | $0.43400 | $0.43400
40 | HRS-2B-10-GA | RECEPTACLE STRIP, 1.27MM,VERTICA | J8 | 1 | $0.52100 | $0.52100
41 | 10147606-00004LF | CONN HEADER SMD R/A 4POS 1MM | J11 | 1 | $0.58300 | $0.58300
42 | SDE0604A-6R8M | FIXED IND 6.8UH 3A 80 MOHM SMD | L1 | 1 | $0.57500 | $0.57500
43 | PCB |  | PCB | 1 | $1.00000 | $1.00000
 |  |  |  | SUM |  | 20.64090
 |  |  |  | VAT(%) | 10 | 2.06409
 |  |  |  | TOTAL |  | 22.70499

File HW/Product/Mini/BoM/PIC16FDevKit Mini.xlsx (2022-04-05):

Category | Quantity | References | Value | Description | PCB Package | Stock Code | Unit Cost
Capacitors | 6 | C1,C3,C18,C20-C22 | 10uF | CAP CER SMD 0402 10uF 6.3V 20% X6S | 0402_CAP | GRM155C80J106ME11D
Capacitors | 12 | C2,C5-C7,C10-C11,C13-C17,C19 | 100nF | CAP CER SMD 0402 100nF 25V 20% Y5V | 0402_CAP | CC0402ZRY5V8BB104 | $0.01
Capacitors | 2 | C4,C9 | 47uF | CAP CER SMD 1206 10uF 25V 10% X5R | CAP1206 | GRM319R61E106KA12D | $0.54
Capacitors | 1 | C8 | 22uF | CAP CER SMD 0805 22uF 6.3V 10% X5R | 0805_CAP | C2012X5R0J226K/1.25 | $0.10
Resistors | 6 | R1,R10,R12,R14,R23,R26 | 1k | RES SMD 0402 1K 5% 1/16W | 0402_RES | RC0402JR-071KL | $0.01
Resistors | 3 | R2,R7,R17 | 5k1 | RES SMD 0402 5.1K OHM 1% 1/16W | 0402_RES | AC0402FR-075K1L | $0.02
Resistors | 2 | R3, R16 | 52k3 | RES SMD 0402 52.3K 1% 1/16W | 0402_RES | RC0402FR-0752K3L | $0.02
Resistors | 3 | R4-R5,R11 | 4k7 | RES SMD 0402 4.7K 5% 1/16W | 0402_RES | MCR01MRTJ472 | $0.01
Resistors | 2 | R15,R22 | 10k | RES SMD 0402 10K 1% 1/16W | 0402_RES | RC0402FR-0710KL | $0.16
Resistors | 1 | R24 | 2k2 | RES SMD 0402 2.2K 5% 1/16W | 0402_RES | MCR01MRTF2201 | $0.01
Integrated Circuits | 1 | U1 | AP6220X | 17V 2A ADJ ACOT BUCK SOT-563(FC) | SOT563_DIODE | RT6252BHGH6F (https://www.digikey.com/en/products/detail/richtek-usa-inc/RT6252BHGH6F/13180173) | $0.85
Integrated Circuits | 1 | U2 | TEMP(D1) | SENSOR ANALOG -40C-150C SC70 | SC70-5-MIC | MCP9700T-H/LT (https://www.digikey.com/en/products/detail/microchip-technology/MCP9700T-H-LT/2342427) | $0.42
Integrated Circuits | 1 | U3 | FLASH | IC FLASH 4MBIT SPI 50MHZ 8SOIC | SOIC127P600X173-8 | SST25VF040B-50-4C-SAF (https://www.digikey.com/en/products/detail/microchip-technology/SST25VF040B-50-4C-SAF/4740879) | $1.03
Integrated Circuits | 1 | U4 | RV-8263-C7 | IC RTC CLK/CALENDAR I2C 8SON | RV8263C7 | RV-8263-C7-32.768KHZ-20PPM-TA-QC (https://www.digikey.com/en/products/detail/micro-crystal-ag/RV-8263-C7-32-768KHZ-20PPM-TA-QC/10499245) | $1.54
Integrated Circuits | 1 | U5 | MIC5370-PGYMT-TR | IC REG LINEAR 3.3V/3.3V 6TMLF | SON50P160X160X60-7N-D | MIC5370-SSYMT-TR (https://www.digikey.com/en/products/detail/microchip-technology/MIC5370-SSYMT-TR/1974124) | $0.46
Integrated Circuits | 1 | U6 | PROGRAMMER MCU | IC MCU 32BIT 64KB FLASH 28UQFN | UQFN28_0.4X4X4 | PIC32MM0064GPM028-I/M6 (https://www.digikey.com/en/products/detail/microchip-technology/PIC32MM0064GPM028-I-M6/8037777) | $2.38
Integrated Circuits | 1 | U7 | LEVEL SHIFTER | IC TRNSLTR BIDIRECTIONAL 8VSSOP | SOP50P310X100-8N | 74LVC2T45DC,125 (https://www.digikey.com/en/products/detail/nexperia-usa-inc/74LVC2T45DC-125/2530595) | $0.67
Integrated Circuits | 1 | U8 | TARGET MCU | IC MCU 8BIT 56KB FLASH 44TQFP | TQFP44_0.8_10X10X1_MCHP | PIC16F18877-I/PT (https://www.digikey.com/en/products/detail/microchip-technology/PIC16F18877-I-PT/6098397) | $2.15
Integrated Circuits | 1 | U9 | MIC5528 | IC REG LINEAR 3.3V 500MA 6XTDFN | DTFN1212-6LD-PL-1 | MIC5528-3.3YMX-TR (https://www.digikey.com/en/products/detail/microchip-technology/MIC5528-3-3YMX-TR/4465358) | $0.24
Transistors | 1 | Q1 | RZF013P01TL | MOSFET P-CH 12V 1.3A TUMT3 | SOT-323T_TUMT3_ROHM | RZF013P01TL (https://www.digikey.com/en/products/detail/rohm-semiconductor/RZF013P01TL/5042831) | $0.34
Diodes | 1 | D1 | BLED | LED BLUE CLEAR 0603 SMD | SML-D12U8W | 150060BS75000 (https://www.digikey.com/en/products/detail/würth-elektronik/150060BS75000/4489895) | $0.16
Diodes | 1 | D2 | BTLED | LED RED CLEAR 0603 SMD | SML-D12U8W | 150060SS75000 (https://www.digikey.com/en/products/detail/würth-elektronik/150060SS75000/4489903) | $0.15
Diodes | 1 | D3 | GLED | LED GREEN CLEAR 0603 SMD | SML-D12U8W | 150060VS75000 (https://www.digikey.com/en/products/detail/würth-elektronik/150060VS75000/4489906) | $0.15
Diodes | 1 | D4 | STATUS | LED YELLOW CLEAR 0603 SMD | SML-D12U8W | 150060YS75000 (https://www.digikey.com/en/products/detail/würth-elektronik/150060YS75000/4489909) | $0.15
Diodes | 1 | D5 | RLED | LED RED CLEAR 0603 SMD | SML-D12U8W | 150060SS75000 (https://www.digikey.com/en/products/detail/würth-elektronik/150060SS75000/4489903) | $0.15
Diodes | 1 | D6 | RB162VAM-20TR | DIODE SCHOTTKY 20V 1A TUMD2M | TUMD2 | RB162VAM-20TR (https://www.digikey.com/en/products/detail/rohm-semiconductor/RB162VAM-20TR/7793317) | $0.31
Diodes | 1 | D7 | RB751G-40T2R | DIODE SCHOTTKY 30V 100MA SOD723 | SOD-723_SC-104A_VMD2_ROHM | RB521G-30HF (https://www.digikey.com/en/products/detail/comchip-technology/RB521G-30HF/7201128) | $0.29
Miscellaneous | 1 | BT1 | RESET | SWITCH TACTILE SPST-NO 0.05A 16V | PTS815 | PTS810 SJG 250 SMTR LFS (https://www.digikey.com/en/products/detail/c-k/PTS810-SJG-250-SMTR-LFS/4176612) | $0.37
Miscellaneous | 1 | BT2 | UBT (D3) | SWITCH TACTILE SPST-NO 0.05A 16V | PTS815 | PTS810 SJG 250 SMTR LFS (https://www.digikey.com/en/products/detail/c-k/PTS810-SJG-250-SMTR-LFS/4176612) | $0.37
Miscellaneous | 1 | FT1 | 100R@100MHz | FERRITE BEAD 600 OHM 0603 1LN | 0603_FE | BBPY00160808601Y00 (https://www.digikey.com/en/products/detail/chilisin-electronics/BBPY00160808601Y00/10498841) | $0.06
Miscellaneous | 1 | J1 | USB2 | CONN RCP USB2.0 TYP C 24P SMD RA | GCT_USB4105 | USB4105-GF-A (https://www.digikey.com/en/products/detail/gct/USB4105-GF-A/11198441) | $0.71
Miscellaneous | 1 | J2 | CONN 1-10 | RECEPTACLE STRIP, 1.27MM, VERTIC | SIL10_1.27_TH_SMD | HRS-1B-10-GA (https://www.digikey.com/en/products/detail/adam-tech/HRS-1B-10-GA/9832954) | $0.63
Miscellaneous | 1 | J4 | CONN 11-17 | RECEPTACLE STRIP, 1.27MM, VERTIC | SIL7_1.27_TH_SMD | HRS-1B-07-GA (https://www.digikey.com/en/products/detail/adam-tech/HRS-1B-07-GA/9832943) | $0.45
Miscellaneous | 1 | J6 | CONN 26-35 | RECEPTACLE STRIP, 1.27MM, VERTIC | SIL10_1.27_TH_SMD | HRS-1B-10-GA (https://www.digikey.com/en/products/detail/adam-tech/HRS-1B-10-GA/9832954) | $0.63
Miscellaneous | 1 | J7 | CONN 18-25 | RECEPTACLE STRIP, 1.27MM, VERTIC | SIL8_1.27_TH_SMD | HRS-1B-08-GA (https://www.digikey.com/en/products/detail/adam-tech/HRS-1B-08-GA/9832941) | $0.50
Miscellaneous | 1 | L1 | 4.7uH | FIXED IND 4.7UH 600MA 615MOHM SM | IND0805 | MBKK2012T4R7M (https://www.digikey.com/en/products/detail/taiyo-yuden/MBKK2012T4R7M/5035139) | $0.22

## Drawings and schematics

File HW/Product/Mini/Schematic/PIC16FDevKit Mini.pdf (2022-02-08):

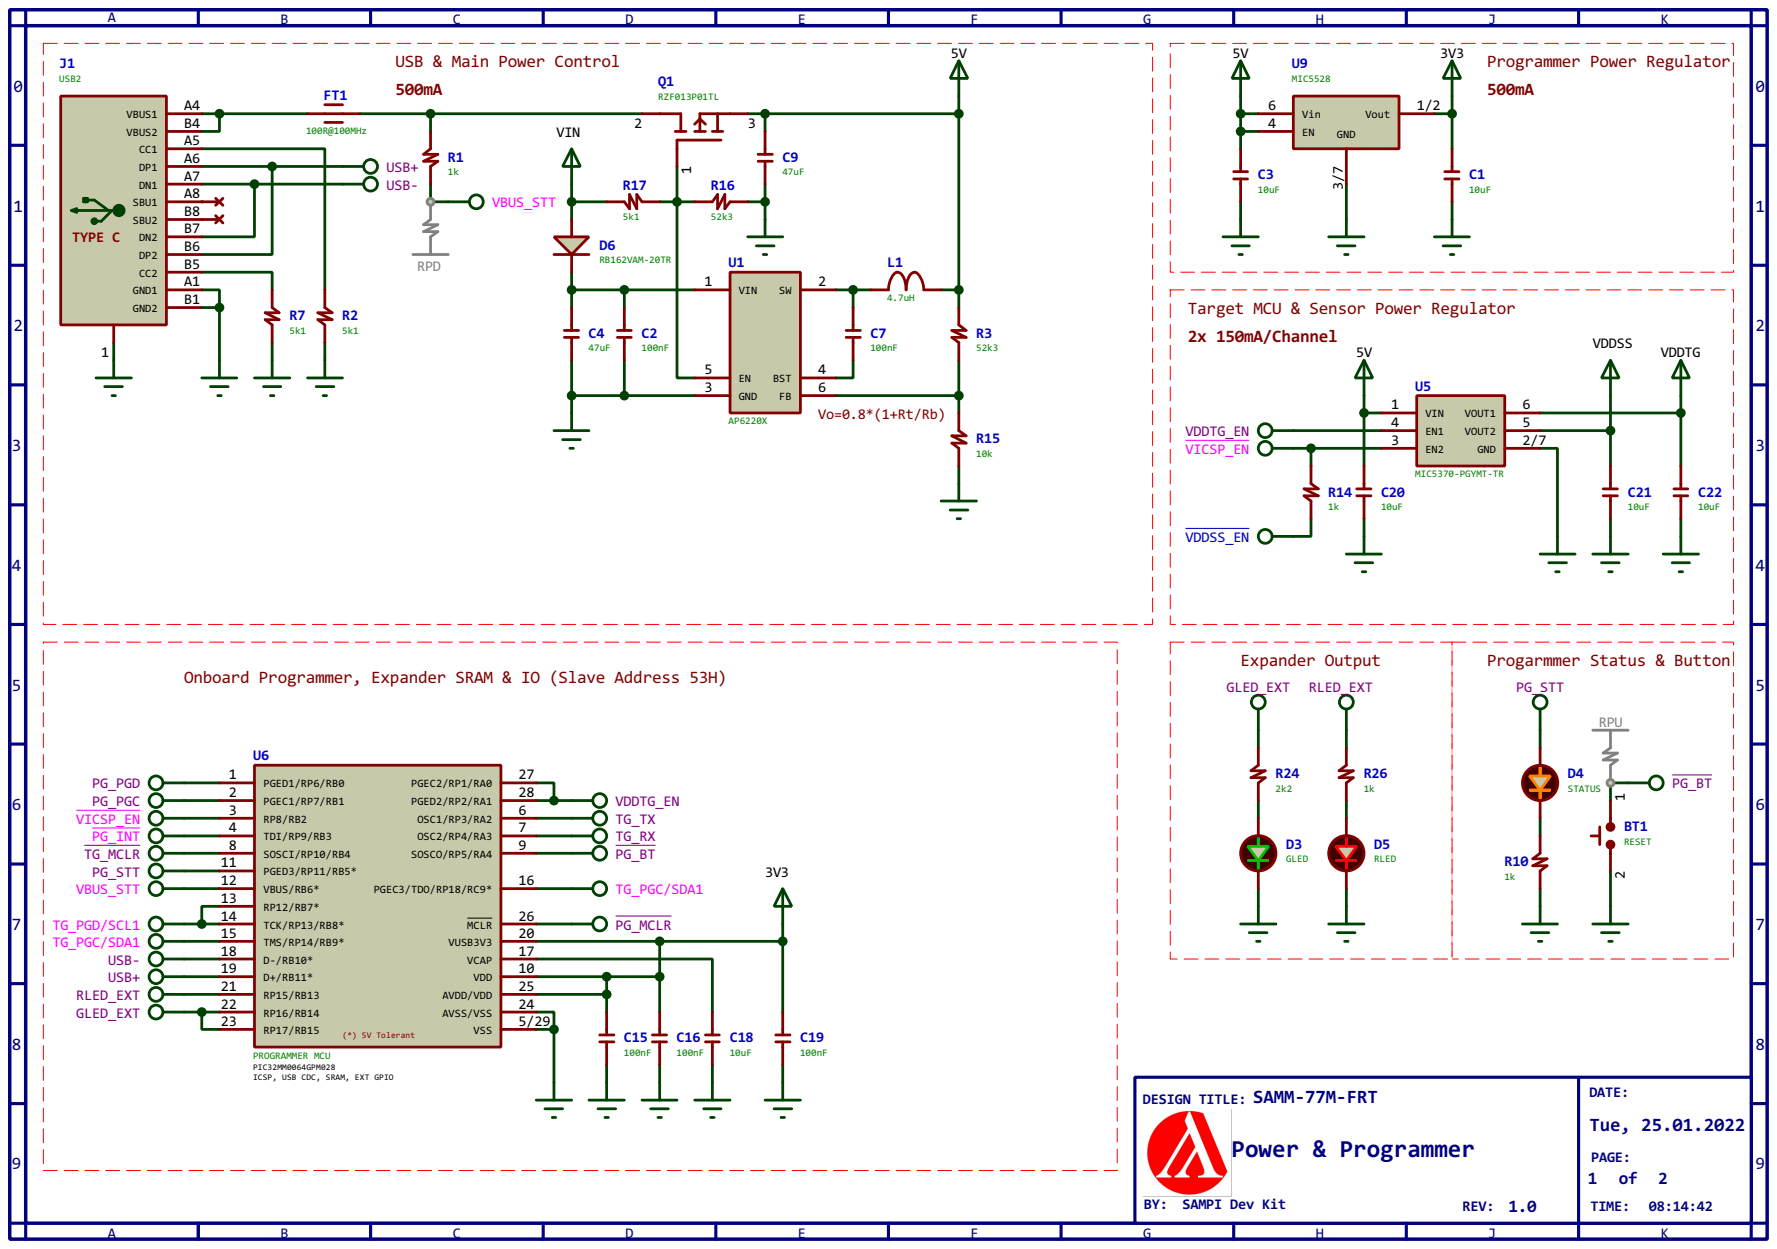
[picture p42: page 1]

Target MCU & Sensor Power Regulator
2x 150mA/Channel

Onboard Programmer, Expander SRAM & IO (Slave Address 53H)

PROGRAMMER MCU
PIC32MM0064GPM028
ICSP, USB CDC, SRAM, EXT GPIO

DESIGN TITLE: SAMM-77M-FRT

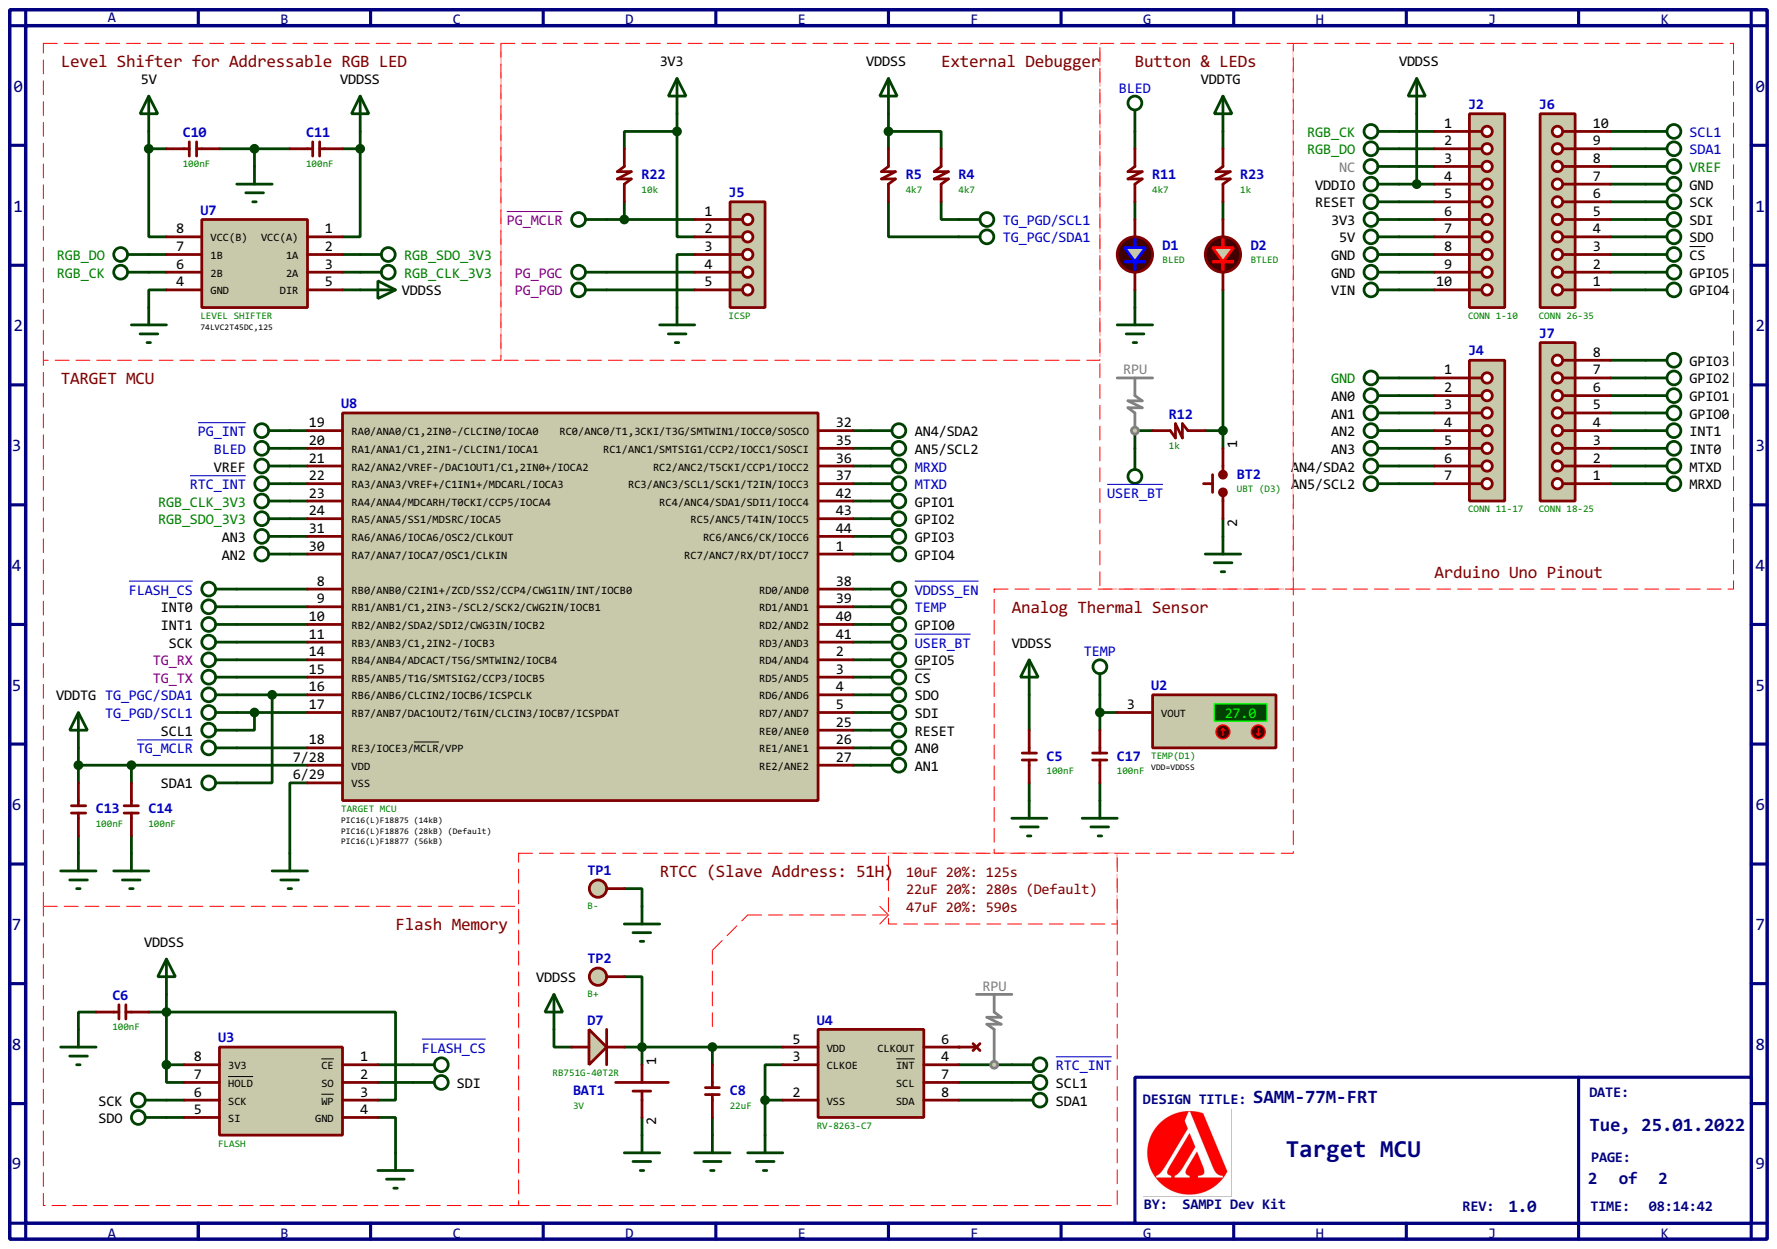
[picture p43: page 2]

RB6/ANB6/CLCIN2/IOCB6/ICSPCLK 16
RB7/ANB7/DAC1OUT2/T6IN/CLCIN3/IOCB7/ICSPDAT 17

DESIGN TITLE: SAMM-77M-FRT

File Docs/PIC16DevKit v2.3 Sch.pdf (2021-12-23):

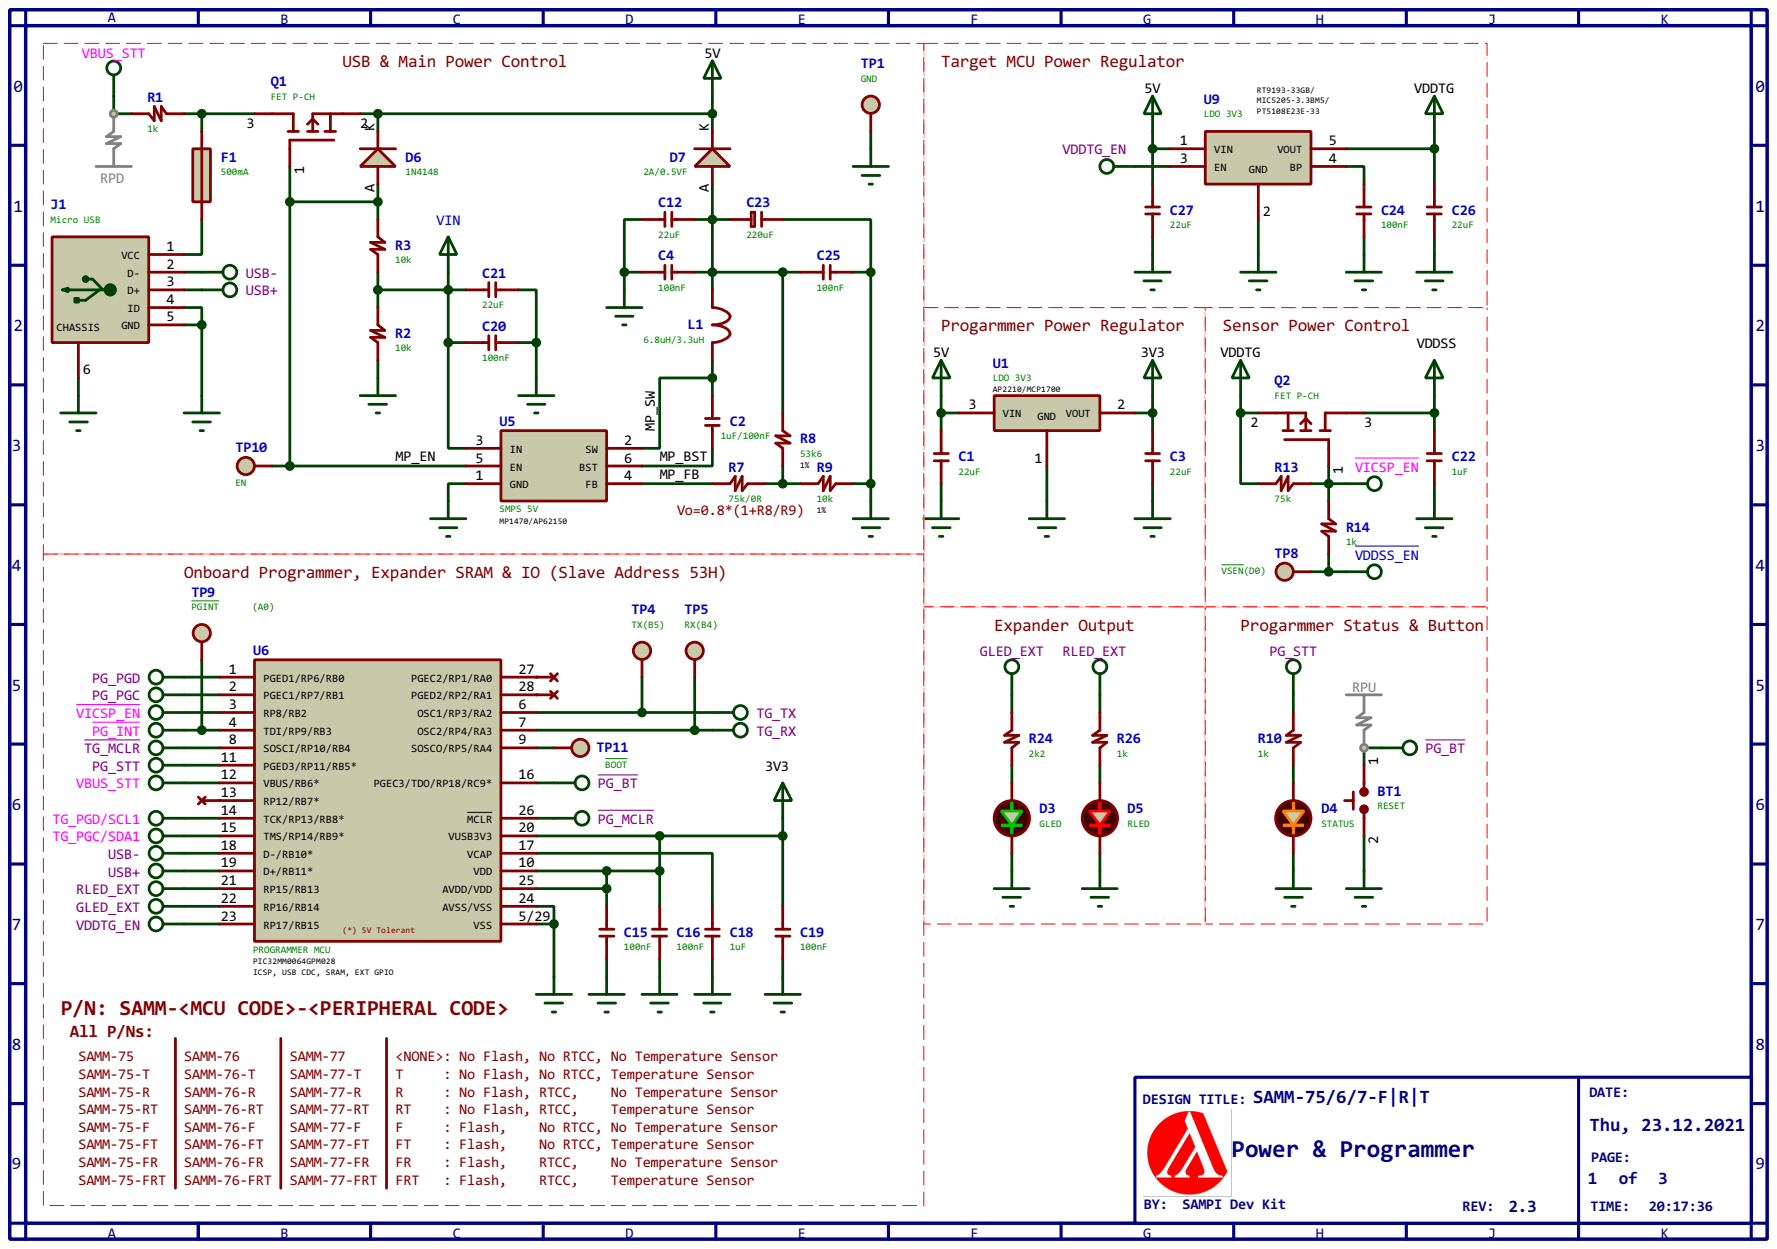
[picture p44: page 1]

USB & Main Power Control

Target MCU Power Regulator

Onboard Programmer, Expander SRAM & IO (Slave Address 53H)
VSEN(D0) TP9

PROGRAMMER MCU
PIC32MM0064GPM028
ICSP, USB CDC, SRAM, EXT GPIO

<NONE>: No Flash, No RTCC, No Temperature Sensor

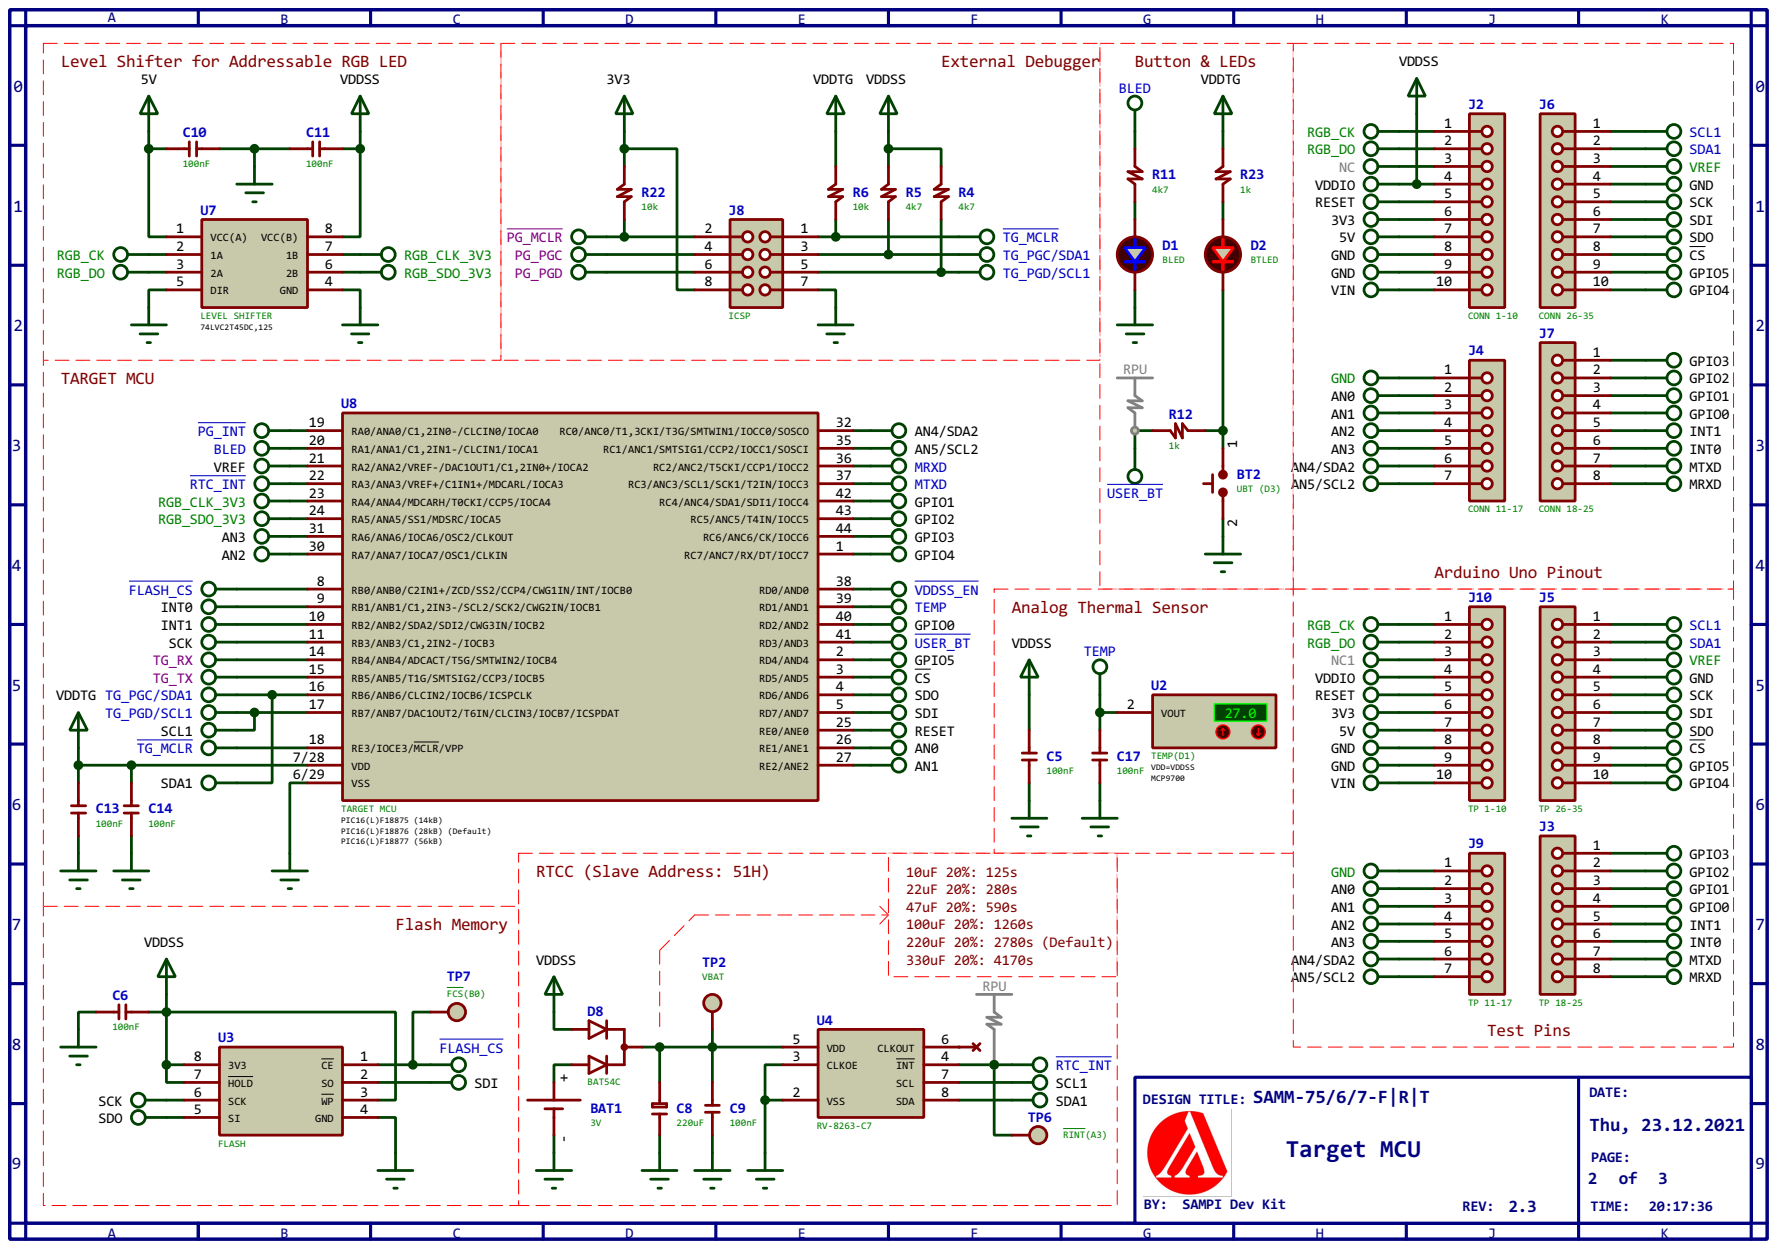
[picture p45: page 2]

RB6/ANB6/CLCIN2/IOCB6/ICSPCLK 16
RB7/ANB7/DAC1OUT2/T6IN/CLCIN3/IOCB7/ICSPDAT 17

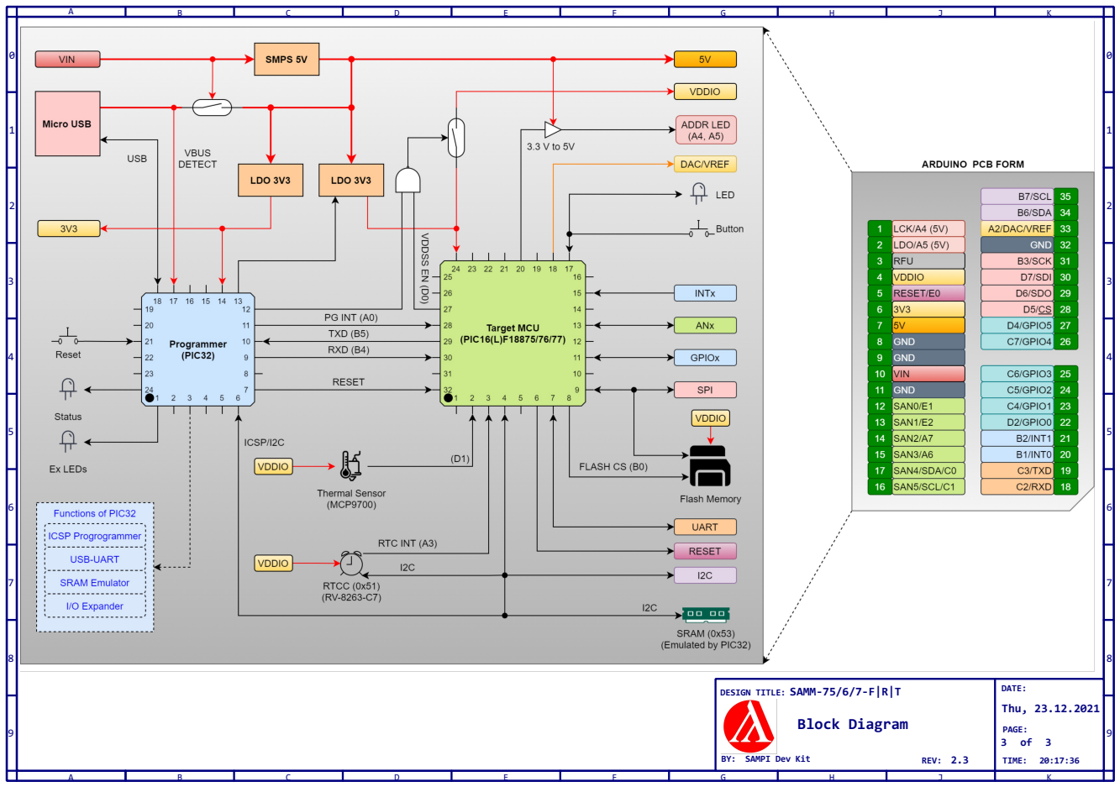
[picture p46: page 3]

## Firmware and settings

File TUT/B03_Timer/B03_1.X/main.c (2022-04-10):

/*
 * File:   main.c
 * Author: sampi
 *
 * Created on January 21, 2022, 10:28 PM
 */

// PIC16F18877 Configuration Bit Settings
// 'C' source line config statements
// CONFIG1
#pragma config FEXTOSC = OFF    // External Oscillator mode selection bits (Oscillator not enabled)
#pragma config RSTOSC = HFINT32 // Power-up default value for COSC bits (HFINTOSC with OSCFRQ= 32 MHz and CDIV = 1:1)
#pragma config CLKOUTEN = OFF   // Clock Out Enable bit (CLKOUT function is disabled; i/o or oscillator function on OSC2)
#pragma config CSWEN = ON       // Clock Switch Enable bit (Writing to NOSC and NDIV is allowed)
#pragma config FCMEN = ON       // Fail-Safe Clock Monitor Enable bit (FSCM timer enabled)

// CONFIG2
#pragma config MCLRE = ON       // Master Clear Enable bit (MCLR pin is Master Clear function)
#pragma config PWRTE = OFF      // Power-up Timer Enable bit (PWRT disabled)
#pragma config LPBOREN = OFF    // Low-Power BOR enable bit (ULPBOR disabled)
#pragma config BOREN = ON       // Brown-out reset enable bits (Brown-out Reset Enabled, SBOREN bit is ignored)
#pragma config BORV = LO        // Brown-out Reset Voltage Selection (Brown-out Reset Voltage (VBOR) set to 1.9V on LF, and 2.45V on F Devices)
#pragma config ZCD = OFF        // Zero-cross detect disable (Zero-cross detect circuit is disabled at POR.)
#pragma config PPS1WAY = ON     // Peripheral Pin Select one-way control (The PPSLOCK bit can be cleared and set only once in software)
#pragma config STVREN = ON      // Stack Overflow/Underflow Reset Enable bit (Stack Overflow or Underflow will cause a reset)

// CONFIG3
#pragma config WDTCPS = WDTCPS_31// WDT Period Select bits (Divider ratio 1:65536; software control of WDTPS)
#pragma config WDTE = OFF       // WDT operating mode (WDT Disabled, SWDTEN is ignored)
#pragma config WDTCWS = WDTCWS_7// WDT Window Select bits (window always open (100%); software control; keyed access not required)
#pragma config WDTCCS = SC      // WDT input clock selector (Software Control)

// CONFIG4
#pragma config WRT = OFF        // UserNVM self-write protection bits (Write protection off)
#pragma config SCANE = available// Scanner Enable bit (Scanner module is available for use)
#pragma config LVP = ON         // Low Voltage Programming Enable bit (Low Voltage programming enabled. MCLR/Vpp pin function is MCLR.)

// CONFIG5
#pragma config CP = OFF         // UserNVM Program memory code protection bit (Program Memory code protection disabled)
#pragma config CPD = OFF        // DataNVM code protection bit (Data EEPROM code protection disabled)

// #pragma config statements should precede project file includes.
// Use project enums instead of #define for ON and OFF.

#include <xc.h>

#define _XTAL_FREQ 32000000 // System clock

void __interrupt() INTERRUPT_InterruptManager(void)
{
    if((PIE0bits.TMR0IE==1)&&(PIR0bits.TMR0IF==1))
    {
        PIR0bits.TMR0IF=0; // clear the TMR0 interrupt flag
        // Reinitialize TMR0 value for 500ms overflow;
        TMR0L=111;
        TMR0H=248;
        // Do something
        LATAbits.LATA1^=1; // toggle A1
    }
}

void main(void)
{
    // Oscillator configure, data sheet pg. 121-126
    OSCCON1=0b01100000; // NOSC HFINTOSC; NDIV 1; 
    OSCFRQ=0b00000110; // HFFRQ 32_MHz;

    // GPIO configure
    ANSELAbits.ANSA1=0; // A1 signal is digital
    TRISAbits.TRISA1=0; // A1 is an output
    LATAbits.LATA1=0; // State of A1 is low

    // Timer 0 configure
    PMD1bits.TMR0MD=0; // TMR0 module is enabled
    T0CON0=0b00010000; // T0EN disabled; T016BIT 16-bit; T0OUTPS 1:1; 
    T0CON1=0b10010011; // T0CS LFINTOSC; T0ASYNC not sync; T0CKPS 1:8; 
    // TMR0 initialize value for 500ms overflow;
    TMR0L=111;
    TMR0H=248;
    PIR0bits.TMR0IF=0; // Clear Interrupt flag
    PIE0bits.TMR0IE=1; // Enabling TMR0 interrupt
    T0CON0bits.T0EN=1; // enable TMR0
    INTCONbits.GIE=1; // enable global interrupt

    while(1)
    {
        // do nothing
    }
}

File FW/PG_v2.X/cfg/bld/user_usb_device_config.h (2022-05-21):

#ifndef USER_USB_CONFIG_H
#define USER_USB_CONFIG_H

/** DEFINITIONS ****************************************************/
#define USB_EP0_BUFF_SIZE		8	// Valid Options: 8, 16, 32, or 64 bytes.
// Using larger options take more SRAM, but
// does not provide much advantage in most types
// of applications.  Exceptions to this, are applications
// that use EP0 IN or OUT for sending large amounts of
// application related data.

#define USB_MAX_NUM_INT     	1   // For tracking Alternate Setting
#define USB_MAX_EP_NUMBER	    1

//Device descriptor - if these two definitions are not defined then
//  a const USB_DEVICE_DESCRIPTOR variable by the exact name of device_dsc
//  must exist.
#define USB_USER_DEVICE_DESCRIPTOR &device_dsc
#define USB_USER_DEVICE_DESCRIPTOR_INCLUDE extern const USB_DEVICE_DESCRIPTOR device_dsc

//Configuration descriptors - if these two definitions do not exist then
//  a const uint8_t *const variable named exactly USB_CD_Ptr[] must exist.
#define USB_USER_CONFIG_DESCRIPTOR USB_CD_Ptr
#define USB_USER_CONFIG_DESCRIPTOR_INCLUDE extern const uint8_t *const USB_CD_Ptr[]

//Make sure only one of the below "#define USB_PING_PONG_MODE"
//is uncommented.
//#define USB_PING_PONG_MODE USB_PING_PONG__NO_PING_PONG
#define USB_PING_PONG_MODE USB_PING_PONG__FULL_PING_PONG
//#define USB_PING_PONG_MODE USB_PING_PONG__EP0_OUT_ONLY
//#define USB_PING_PONG_MODE USB_PING_PONG__ALL_BUT_EP0		//NOTE: This mode is not supported in PIC18F4550 family rev A3 devices

#define USB_POLLING
//#define USB_INTERRUPT

/* Parameter definitions are defined in usb_device.h */
#define USB_PULLUP_OPTION USB_PULLUP_ENABLE
//#define USB_PULLUP_OPTION USB_PULLUP_DISABLED

#define USB_TRANSCEIVER_OPTION USB_INTERNAL_TRANSCEIVER
//External Transceiver support is not available on all product families.  Please
//  refer to the product family datasheet for more information if this feature
//  is available on the target processor.
//#define USB_TRANSCEIVER_OPTION USB_EXTERNAL_TRANSCEIVER

#define USB_SPEED_OPTION USB_FULL_SPEED
//#define USB_SPEED_OPTION USB_LOW_SPEED //(not valid option for PIC24F devices)

//------------------------------------------------------------------------------------------------------------------
//Option to enable auto-arming of the status stage of control transfers, if no
//"progress" has been made for the USB_STATUS_STAGE_TIMEOUT value.
//If progress is made (any successful transactions completing on EP0 IN or OUT)
//the timeout counter gets reset to the USB_STATUS_STAGE_TIMEOUT value.
//
//During normal control transfer processing, the USB stack or the application 
//firmware will call USBCtrlEPAllowStatusStage() as soon as the firmware is finished
//processing the control transfer.  Therefore, the status stage completes as 
//quickly as is physically possible.  The USB_ENABLE_STATUS_STAGE_TIMEOUTS 
//feature, and the USB_STATUS_STAGE_TIMEOUT value are only relevant, when:
//1.  The application uses the USBDeferStatusStage() API function, but never calls
//      USBCtrlEPAllowStatusStage().  Or:
//2.  The application uses host to device (OUT) control transfers with data stage,
//      and some abnormal error occurs, where the host might try to abort the control
//      transfer, before it has sent all of the data it claimed it was going to send.
//
//If the application firmware never uses the USBDeferStatusStage() API function,
//and it never uses host to device control transfers with data stage, then
//it is not required to enable the USB_ENABLE_STATUS_STAGE_TIMEOUTS feature.

#define USB_ENABLE_STATUS_STAGE_TIMEOUTS    //Comment this out to disable this feature.  

//Section 9.2.6 of the USB 2.0 specifications indicate that:
//1.  Control transfers with no data stage: Status stage must complete within 
//      50ms of the start of the control transfer.
//2.  Control transfers with (IN) data stage: Status stage must complete within 
//      50ms of sending the last IN data packet in fullfilment of the data stage.
//3.  Control transfers with (OUT) data stage: No specific status stage timing
//      requirement.  However, the total time of the entire control transfer (ex:
//      including the OUT data stage and IN status stage) must not exceed 5 seconds.
//
//Therefore, if the USB_ENABLE_STATUS_STAGE_TIMEOUTS feature is used, it is suggested
//to set the USB_STATUS_STAGE_TIMEOUT value to timeout in less than 50ms.  If the
//USB_ENABLE_STATUS_STAGE_TIMEOUTS feature is not enabled, then the USB_STATUS_STAGE_TIMEOUT
//parameter is not relevant.

#define USB_STATUS_STAGE_TIMEOUT    (uint8_t)45   //Approximate timeout in milliseconds, except when
//USB_POLLING mode is used, and USBDeviceTasks() is called at < 1kHz
//In this special case, the timeout becomes approximately:
//Timeout(in milliseconds) = ((1000 * (USB_STATUS_STAGE_TIMEOUT - 1)) / (USBDeviceTasks() polling frequency in Hz))
//------------------------------------------------------------------------------------------------------------------
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

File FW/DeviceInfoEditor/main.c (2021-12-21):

#include "libcomp.h"

#define DATA_LEN        144
#define BEGIN_ADDR      0x1D00C000
#define END_ADDR        (BEGIN_ADDR+DATA_LEN)

static uint8_t RawLen;
static uint8_t RawHex[64];
static uint8_t ModIdx;
static uint8_t ModLen;
static uint8_t ModTotalLen;
static uint8_t ModHex[DATA_LEN];
static uint8_t mod=0;

int8_t DATA_Write(uint32_t Addr, uint8_t *pData, uint8_t Len) // <editor-fold defaultstate="collapsed" desc="Write data">
{
    if((Addr>=BEGIN_ADDR)&&(Addr<END_ADDR))
    {
        ModLen=Len;
        ModIdx=(uint8_t) (Addr-BEGIN_ADDR);
        mod=1;
    }

    return PROC_DONE;
} // </editor-fold>

uint8_t Ascii2Hex(uint8_t *pD) // <editor-fold defaultstate="collapsed" desc="Convert ASCII to hex">
{
    uint8_t x;

    if(*pD<='9')
        x=(*pD)-'0';
    else if(*pD<='F')
        x=((*pD)-'A')+10;
    else
        x=((*pD)-'a')+10;

    x<<=4;
    pD++;

    if(*pD<='9')
        x|=(*pD)-'0';
    else if(*pD<='F')
        x|=((*pD)-'A')+10;
    else
        x|=((*pD)-'a')+10;

    return x;
} // </editor-fold>

int main(int argc, char** argv)
{
    uint8_t *p;
    uint8_t c, i, j, k;
    FILE *pHex, *pTemplate, *pNewHex, *pUser;
    char footer[128], new_file_name[64], user_name[64];

    if(argc!=4)
    {
        printf("Incorrect inputs");
        printf("\nHELP:\n<hex file> <template file> <user name file>");
        goto EXIT;
    }

    pUser=fopen(argv[3], "r");

    if(pUser==NULL)
    {
        printf("\nCan not open User name file");
        goto EXIT;
    }

    while(1)
    {
        i=0;
        memset(user_name, 0x00, (size_t) membersof(user_name));

        do
        {
            c=fgetc(pUser);
            user_name[i++]=c;
        }
        while((c!=0x00)&&(c!=0xFF)&&(c!=EOF)&&(c!='\n'));

        if(i<=1)
            goto EXIT;
        
        if(user_name[i-1]==0xFF)
            user_name[i-1]=0x00;

        pHex=fopen(argv[1], "r");

        if(pHex==NULL)
        {
            printf("\nCan not open Hex file");
            goto EXIT;
        }

        pTemplate=fopen(argv[2], "r");

        if(pTemplate==NULL)
        {
            printf("\nCan not open Template file");
            goto EXIT;
        }

        str_remove(user_name, '"');
        str_remove(user_name, '\r');
        str_remove(user_name, '\n');
        sprintf(new_file_name, "%s.hex", user_name);
        pNewHex=fopen(new_file_name, "w+");

        if(pNewHex==NULL)
        {
            printf("\nCan not create new hex file");
            goto EXIT;
        }

        mod=0;
        RawLen=0;
        ModTotalLen=9;
        memset(RawHex, 0x00, (size_t) membersof(RawHex));
        memset(ModHex, 0x00, (size_t) membersof(ModHex));

        i=0;

        do
        {
            c=(uint8_t) fgetc(pTemplate);
            ModHex[i++]=c;

            if(i>=(size_t) membersof(ModHex))
                break;
        }
        while((c!=0x00)&&(c!=0xFF)&&(c!=EOF));

        p=strstr(ModHex, "BLD Rel: ");

        if(p==NULL)
        {
            printf("\nNo \"BLD Rel: \" in template file");
            goto EXIT;
        }

        memset(footer, 0x00, (size_t) membersof(footer));
        strcpy(footer, p);
        p=strstr(ModHex, "Owner: ");

        if(p==NULL)
        {
            printf("\nNo \"Owner: \" in template file");
            goto EXIT;
        }

        p+=7;

        while(*p!=0x00)
        {
            *p=0x00;
            p++;
        }

        i=strlen(ModHex);
        sprintf(&ModHex[i], "%s\n%s", user_name, footer);

        printf("\nNew info:\n%s\n", ModHex);
        PrintHex(ModHex, DATA_LEN, 8);

        do
        {
            c=(uint8_t) fgetc(pHex);
            HEXPARSE_Tasks(c);

            if((c==':')||(c==0x00)||(c==0xFF)||(c==EOF))
            {
                if(mod!=0)
                {
                    j=0;

                    for(i=1; i<ModTotalLen; i+=2)
                    {
                        k=Ascii2Hex(&RawHex[i]);
                        j+=k;
                    }

                    j=(0xFF-j);
                    j++;

                    RawHex[ModTotalLen++]=Bcd2Hex(j>>4);
                    RawHex[ModTotalLen++]=Bcd2Hex(j&0x0F);
                    RawHex[ModTotalLen++]='\n';
                    RawHex[ModTotalLen++]=0x00;

                    ModTotalLen=9;
                    mod=0;
                }

                fprintf(pNewHex, "%s", RawHex);
                memset(RawHex, 0x00, (size_t) membersof(RawHex));
                RawLen=0;
            }

            RawHex[RawLen++]=c;

            if(mod==1)
            {
                for(i=0; i<ModLen; i++)
                {
                    j=2*i+9;
                    k=ModHex[ModIdx+i];
                    RawHex[j]=Bcd2Hex(k>>4);
                    RawHex[j+1]=Bcd2Hex(k&0x0F);
                    ModTotalLen+=2;
                }

                mod=2;
            }
        }
        while((c!=0xFF)&&(c!=0x00)&&(c!=EOF));

        if(pHex)
            fclose(pHex);

        if(pNewHex)
            fclose(pNewHex);
    }

EXIT:
    if(pHex)
        fclose(pHex);

    if(pTemplate)
        fclose(pTemplate);

    if(pNewHex)
        fclose(pNewHex);

    if(pUser)
        fclose(pUser);

    return (EXIT_SUCCESS);
}

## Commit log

2021-01-03 Schematic update 1
2021-01-04 Schematic update 2
2021-01-04 Schematic update 3
2021-01-05 Schematic update 4
2021-01-05 Schematic update 5
2021-01-06 Schematic update 6
2021-01-12 Schematic update 7
    [Target MCU ID Cfg.xlsx]
2021-01-13 Schematic update 8
2021-01-13 Schematic update 9
2021-01-14 Schematic update 10
2021-01-15 Schematic update 11
2021-01-15 Schematic update 12
2021-01-17 Schematic update 13
2021-01-26 Gerber, schematic, images, 3D of version 1.0
    [PIC16DevKit - CADCAM Bottom Copper.GBR, PIC16DevKit - CADCAM Bottom Solder Resist.GBR, PIC16DevKit - CADCAM Drill.DRL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]
2021-01-27 BoM PIC16DevKit v1.0
    [PIC16DevKit v1.0.xlsx]
2021-01-29 Rel PIC16DevKit v1.1: fix top silk
    [PIC16DevKit v1.0.xlsx, PIC16DevKit v1.1.xlsx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]
2021-02-17 Rel PIC16DevKit v1.2: fix top silk
    [PIC16DevKit v1.1.xlsx, PIC16DevKit v1.2.xlsx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]
2021-02-19 PIC16DevKit v2.0: external programmer, SRAM, UART switch via I2C
2021-02-20 PIC16DevKit v2.0 schematic
2021-03-05 Change solution, PIC16LF18877
    [Target MCU ID Cfg.xlsx]
2021-04-03 PIC16DevKit v2.0 release
    [PIC16DevKit - CADCAM Bottom Copper.GBR, PIC16DevKit - CADCAM Bottom Solder Resist.GBR, PIC16DevKit - CADCAM Drill TOP-BOT Plated.GBR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]
2021-04-03 PIC16DevKit v2.0 update silk
    [PIC16DevKit - CADCAM Bottom Copper.GBR, PIC16DevKit - CADCAM Bottom Solder Resist.GBR, PIC16DevKit - CADCAM Drill TOP-BOT Plated.GBR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]
2021-04-08 Update schematic V2.0
2021-04-26 Cross BoM list
    [PIC16DevKit.xlsx]
2021-04-29 Photo of real PCB
2021-05-03 PIC16 Dev Kit v2.1 - change logo, add fiducial
    [PIC16DevKit - CADCAM Bottom Copper.GBR, PIC16DevKit - CADCAM Bottom Solder Resist.GBR, PIC16DevKit - CADCAM Drill.DRL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]
2021-05-04 PIC16 Dev Kit v2.1 - change level shifter, diode after SMPS
    [PIC16DevKit.xlsx]
2021-05-05 PIC16 Dev Kit v2.1 - layout update 2
    [PIC16DevKit - CADCAM Bottom Copper.GBR, PIC16DevKit - CADCAM Bottom Solder Resist.GBR, PIC16DevKit - CADCAM Drill.DRL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]
2021-05-06 Update 3D model, add all devices of PIC16F18877 family, add failed LED state
2021-05-10 PIC16 Dev Kit v2.1 - layout update 3
    [PIC16DevKit - CADCAM Bottom Copper.GBR, PIC16DevKit - CADCAM Bottom Solder Resist.GBR, PIC16DevKit - CADCAM Drill.DRL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]
2021-05-11 Production v2.1 update 1
    [PIC16DevKit.xlsx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]
2021-05-11 Production v2.1 update 2
    [PIC16DevKit.xlsx]
2021-05-23 Fix powering up chip ID error
    [main.c]
2021-05-28 BoM crossing, cost down to 15$ (included PCBA fee)
    [PIC16DevKit.xlsx]
2021-05-30 TG: fix canot get target ID in powering up, change masked address of I2C slaver to 0x00, fix ext gpio read/write functions
    [main.c]
2021-06-05 Add Sensors submodule
2021-10-09 PIC16FDevKit V2.2
    [PIC16DevKit - CADCAM Bottom Copper.GBR, PIC16DevKit - CADCAM Bottom Solder Resist.GBR, PIC16DevKit - CADCAM Drill.DRL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]
2021-10-14 BoM PIC16DevKit_VN
    [PIC16DevKit_VN.xlsx]
2021-10-17 PIC16 Dev Kit v2.3 Production files: RV-8263-C7, CR1220
    [PIC16DevKit - CADCAM Bottom Copper.GBR, PIC16DevKit - CADCAM Bottom Solder Resist.GBR, PIC16DevKit - CADCAM Drill.DRL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]
2021-11-02 Part number options
    [SO12110196323.DXF, TGPCB.xlsx, THEGIOIIC.xlsx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]
2021-11-18 Update: BoM list, Docs
    [THEGIOIIC.xlsx]
2021-12-16 Device info editor tool
2021-12-17 PIC16DevKit Mini schematic
2021-12-20 Device info editor tool update 1
2021-12-21 Device info editor tool update 2
2021-12-21 PIC16DevKit Mini schematic update 1
2021-12-22 PIC16DevKit Mini schematic update 2
2021-12-26 PIC16DevKit v2.4: Change SMPS, logic level shifter update 2
    [PIC16DevKit - CADCAM Bottom Copper.GBR, PIC16DevKit - CADCAM Bottom Solder Resist.GBR, PIC16DevKit - CADCAM Drill.DRL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]
2021-12-26 TG_v2.X: fix RV8263 clock stop bit
    [RV8263C7.c, main.c]
2022-01-07 USB CDC Driver
2022-01-08 TG_v2.X: full test, led test, uart test
2022-01-16 PIC16DevKit Mini rel 1.0
    [PIC16DevKit - CADCAM Bottom Copper.GBR, PIC16DevKit - CADCAM Bottom Solder Resist.GBR, PIC16DevKit - CADCAM Drill.DRL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]
2022-01-18 TG_v2.X: pwm test
2022-02-08 TUT B02 Configuration & GPIO update 1
    [PIC16DevKit Mini.csv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]
2022-02-15 TUT B03 Timer
2022-03-16 BoM of PIC16FDevKit Mini
    [PIC16FDevKit Mini.xlsx]
2022-03-24 Present 2: Timer - update 1
2022-04-05 Present 2: Timer - update 2
    [PIC16FDevKit Mini.xlsx]
2022-04-10 Present 2: Timer - update 3
2022-04-17 Present 2: Timer - update 4
2022-04-21 Present 2:Timer CCS- update 5
2022-04-23 Present 2: Timer CCS - update 6
2022-05-08 Present 3: PWM XC8
2022-07-04 MSSPx I2C master
2023-06-22 Schematic V2.4: USB C, fix disable I2C of RTCC in ICSP mode
    [PIC16DevKit - CADCAM Bottom Copper.GBR, PIC16DevKit - CADCAM Bottom Solder Resist.GBR, PIC16DevKit - CADCAM Drill.DRL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]
2023-06-23 Schematic V2.4 update 1
2023-06-24 Schematic V2.4 update 2
2023-06-25 Schematic V2.4 update 3
2023-06-26 Schematic V2.4 update 4
2023-06-28 Layout V2.4
    [PIC16DevKit.csv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]
2023-06-29 Production V2.4
    [PIC16DevKit - CADCAM Bottom Copper.GBR, PIC16DevKit - CADCAM Bottom Solder Resist.GBR, PIC16DevKit - CADCAM Drill.DRL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]
